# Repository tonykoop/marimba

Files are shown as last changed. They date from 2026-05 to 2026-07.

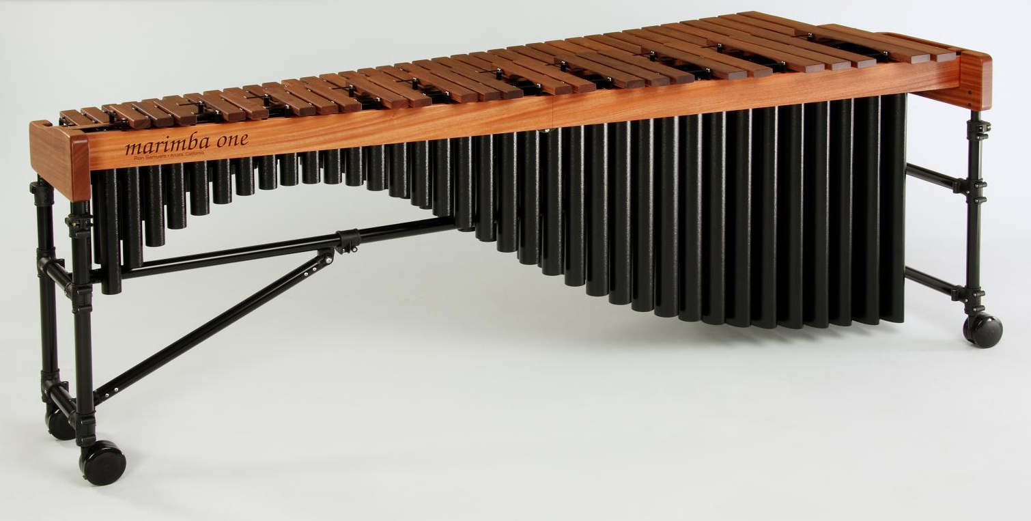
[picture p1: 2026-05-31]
images/hero-render.png

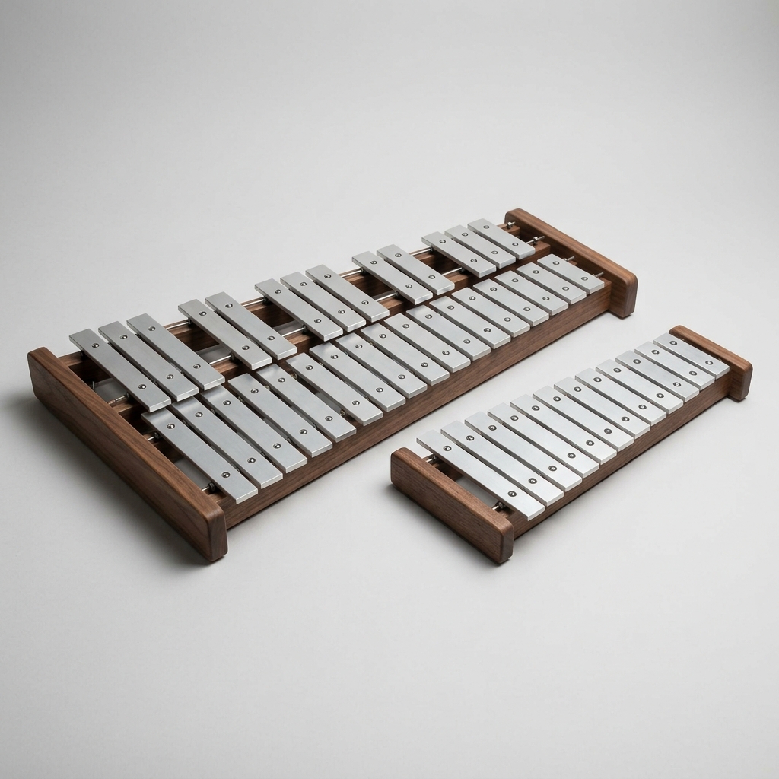
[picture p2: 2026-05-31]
images/family-group.png

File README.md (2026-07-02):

# Marimba - CNC Bar And Resonator Build Packet

> A workbook-derived 37-bar C3-C6 marimba packet for CNC-cut Padauk bars, 3D arch undercuts, tuned quarter-wave resonators, and a SolidWorks-ready master-layout handoff.

Status: L1 concept packet

## What This Is

This repository is the Mode A v4.2 build packet for a marimba: tuned wooden free-free bars suspended at their nodes, with a matched resonator under each note. It turns the existing `marimba-design-table.xlsx` scaffold into a shop-facing documentation set:

1. `design.md` explains the physics model, build range, assumptions, and validation plan.
2. `family-spec.csv` is the 37-bar C3-C6 schedule extracted from the workbook formulas.
3. `bom.csv`, `sourcing.csv`, and `cut-list.csv` separate stable specifications from supplier facts that should be verified before buying.
4. `drawings/`, `cad/`, `cnc/`, `wolfram/`, and `site/` carry the technical handoff layers.
5. `jig-decision.md` turns the fixture assumptions into pilot-build gates before the full Padauk run.
6. `visual-output-register.csv`, `docs/v5-authority-register.csv`,
   `validation-loop.csv`, `docs/v5-readiness.md`, and
   `cad/mcp-session-log.md` make the V5 promotion boundary explicit.

Part of the [tonykoop/instrument-maker](https://github.com/tonykoop/instrument-maker) catalog.

## Physics In One Minute

A marimba bar is a free-free beam. The first mode uses `lambda_1 = 4.730`, and the practical workbook model is:

```text
f ~= K * t / L^2
L ~= sqrt(K * t / f)
```

Length is the dominant pitch lever. Bar thickness and the underside arch tune the bar; width mostly affects feel, loudness, stiffness distribution, and available resonator bore. The cord/support points land at about `0.224 * L` and `0.776 * L`.

The resonator tubes are quarter-wave closed pipes:

```text
L_res ~= c / (4 * f) - 0.82 * bore
```

The resonator reinforces the bar's target frequency. It does not tune the bar itself.

## Build Range

The active packet is a 37-bar chromatic range from C3 to C6, using the workbook's African Padauk setting:

| Note | Frequency | Bar length | Width | Arch depth | Resonator |
| --- | ---: | ---: | ---: | ---: | ---: |
| C3 | 130.813 Hz | 32.251 in | 2.000 in | 0.625 in | 24.260 in |
| C4 | 261.626 Hz | 22.805 in | 1.750 in | 0.469 in | 11.515 in |
| A4 | 440.000 Hz | 17.585 in | 1.750 in | 0.352 in | 6.265 in |
| C6 | 1046.502 Hz | 11.403 in | 1.250 in | 0.156 in | 2.212 in |

The workbook also documents two expansion shapes: a full C2-F6 marimba and a portable C4-F6 instrument. Those are not cut lists yet; they are future configurations once the C3-C6 bar and resonator workflow is validated.

## Repository Structure

```text
marimba/
|-- README.md
|-- design.md
|-- marimba-design-table.xlsx
|-- family-spec.csv
|-- bom.csv
|-- sourcing.csv
|-- cut-list.csv
|-- validation.csv
|-- validation-loop.csv
|-- visual-output-register.csv
|-- assembly-manual.md
|-- supplier-rfq.md
|-- visual-bom-brief.md
|-- drawing-brief.md
|-- risks.md
|-- photo-shotlist.md
|-- cad/
|-- cnc/
|-- data/
|-- docs/
|-- drawings/
|-- evolution/
|-- images/
|-- site/
`-- wolfram/
```

`evolution/` - Stage 0 intake only (manifest, design-intent, revisions); Gate A not yet run.

## Status

**Readiness: L1** — concept / scaffold. Acoustic predictions are empirical estimates; no validated physical build or measured outputs yet. Not a V5 build-packet candidate.

| Area | Status |
| --- | --- |
| Readiness level | **L1** (concept/scaffold; estimates only) |
| V5 status | explorer/prototype scaffold only; not a V5 build-packet candidate |
| Workbook scaffold | done, source table in `marimba-design-table.xlsx` |
| Guided intake | done, see `data/design-intake.json` |
| C3-C6 bar schedule | done, see `family-spec.csv` |
| Visual authority register | done, see `visual-output-register.csv` |
| Issue #5 V5 authority register | reviewed packet surface, see `docs/v5-authority-register.csv` |
| Pilot DXF | C3/A4/C6 only, see `drawings/marimba-pilot-plate.dxf` |
| Validation loop | measurement-required, see `validation-loop.csv` |
| V5 readiness ledger | scaffolded, see `docs/v5-readiness.md` |
| MCP provenance | scaffolded with no live sessions yet, see `cad/mcp-session-log.md` |
| CNC operation plan | generated, pre-CAM only |
| SolidWorks handoff | prepared as CSV/Markdown contract, no native CAD yet |
| Wolfram source | prepared as `.wl`; notebook execution pending local Wolfram |
| Jig decision layer | done, see `jig-decision.md` |
| Build photos | pending first shop build |
| Measured tuning data | pending prototype validation |

The current CAD/DXF authority chain is a reviewed packet surface, not measured
fabrication authority. Workbook-derived design tables, the OpenSCAD starter,
and the pilot DXF plate are registered as `pending_measurement` in
`visual-output-register.csv` and `docs/v5-authority-register.csv`. Generated or
rendered visuals, when added later, are concept/support artifacts only and do
not control dimensions, node locations, resonator lengths, or CNC toolpaths.

## License

[CC BY 4.0](LICENSE) - see `LICENSE` for details.

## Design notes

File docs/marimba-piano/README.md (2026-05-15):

# Marimba Piano

Current status: bare-bones readiness packet

Fabrication authority: not build-ready. The sketch, notes, and estimates in this folder are concept and planning material only until a measured coupon build promotes specific dimensions into CAD, DXF, or a reviewed drawing.

## Concept

The Marimba Piano is a keyboard-driven modular idiophone. Piano-style keys and hammers stay in the chassis. The sound source is a removable tone-bar frame that can be swapped for different acoustic profiles: wood, synthetic bar stock, aluminum, or other tested materials.

The core idea has three modular systems:

- Interchangeable tone-bar frames on the front plane.
- A right-side platen lever that clamps the selected frame and seals its aperture plate against the resonator bank.
- A left-side hammer selector that rotates or indexes multiple hammer-face materials across the whole keyboard.

## File Map

- `design.md` - architecture, assumptions, acoustic model, and open measurements.
- `prototype-plan.md` - P0 through P3 build sequence.
- `tuning-targets-c4-c5.csv` - first-order C4-C5 targets for a 13-note module.
- `hammer-head-test-matrix.csv` - candidate hammer faces and expected effects.
- `aperture-test-matrix.csv` - aperture and coupling tests for resonator throats.
- `bom.csv` - starter bill of materials.
- `sourcing.csv` - sourcing placeholders; all supplier facts are unverified.
- `cut-list.csv` - candidate parts with TBD or estimate status.
- `validation.csv` - gates needed before this becomes a build-ready packet.
- `risks.md` - failure modes and mitigations.
- `drawing-brief.md` - future drawings and authority rules.
- `photo-shotlist.md` - optional documentation shots.
- `references/sketch-20260514.jpg` - original morning sketch, reference-only.

## Next Gates

1. Build a one-note P0 coupon with one key, one hammer, one interchangeable bar, one aperture plate, and one resonator.
2. Measure bar pitch, resonator pitch, gasket leakage, hammer-face tone changes, and platen repeatability.
3. Update the estimates with measured corrections.
4. Promote only measured or reviewed geometry into CAD/DXF authority.

## License Note

No license has been selected for this concept packet yet. Add a license before publishing or sharing fabrication files.

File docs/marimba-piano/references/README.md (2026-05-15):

# References

The files in this folder are reference-only. They do not control dimensions, cut paths, hole locations, aperture locations, hammer centers, or resonator lengths.

- `sketch-20260514.jpg` - original Marimba Piano sketch from the morning idea capture.

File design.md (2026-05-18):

# Marimba Design Packet

## Project Intent

Build a 37-bar C3-C6 marimba packet from the existing workbook design table. The first build target is a CNC-friendly instrument with African Padauk bars, parabolic underside arch undercuts, drilled node supports, quarter-wave resonators, and a frame layout that can become a SolidWorks master sketch.

The useful boundary for this packet is "prototype/shop-planning documentation, not finished CAD or measured build authority." Native SolidWorks files do not exist yet. The CAD folder defines the global-variable and design-table contract Tony can use to build the real model after pilot measurements review the workbook predictions.

## Design Intake

| Field | Value |
| --- | --- |
| Instrument | Marimba |
| Instrument family | Free-free beam idiophone with tuned quarter-wave resonators |
| Active build range | C3-C6 chromatic, 37 bars |
| Source workbook | `marimba-design-table.xlsx`, sheet `Marimba`, range `A1:X106` |
| Primary material | African Padauk bars, workbook K constant `155502` |
| Bar thickness | `0.875 in` nominal edge thickness |
| Minimum center thickness | `0.250 in` after arch undercut |
| Construction pipeline | CNC surfaced blanks, 3D arch undercut, profile/tabs, node drilling, resonator cutting, frame assembly |
| Done-bar reference | `tongue-drum` README and wooden idiophone validation discipline |

The guided v4.2 intake artifacts are in `data/design-intake.json` and `data/design-input-row.csv`.

## Governing Model

### Bar Pitch

The marimba bars are treated as free-free beams. The first flexural mode uses:

```text
lambda_1 = 4.730
f_1 = (lambda_1^2 / (2*pi*L^2)) * sqrt(E*I/(rho*A))
```

The workbook uses the practical shop form:

```text
f ~= K * t / L^2
L ~= sqrt(K * t / f)
```

where:

- `f` is target frequency in Hz.
- `K` is the material-specific free-free bar constant.
- `t` is nominal bar thickness at the edge.
- `L` is bar length.

For the active packet:

```text
K = 155502
t = 0.875 in
```

The workbook material library derives this free-free K from the beam material properties and the `lambda_1 = 4.730` mode shape. Do not apply flute-bore K2 corrections here; those belong to Native American style flute bore correction work, not beam idiophones.

### Nodes And Supports

The suspension node locations are:

```text
node_1 = 0.224 * L
node_2 = 0.776 * L
```

Cord holes and rail pins reference these two locations. Holes must be drilled at the nodal line so the support does not damp the main mode.

### Arch Undercut

The workbook defines a linear MIDI-scaled arch-depth schedule:

```text
arch_depth = (edge_thickness - min_center_thickness) * min(1, (96 - midi)/48)
center_thickness = edge_thickness - arch_depth
```

This makes the low bars carry the deepest undercut and the high bars approach a shallow arch. The current minimum center thickness is `0.250 in`, so C3 reaches the minimum while C6 remains about `0.719 in` at center.

The arch should be cut as a centered parabolic underside relief over roughly 60 percent of the bar length. Final voicing still requires controlled sanding and tuner checks; the workbook is the first-pass schedule.

### Resonators

The resonator tubes are treated as quarter-wave closed pipes:

```text
L_res = 13552 / (4 * f) - 0.82 * bore
```

The sheet currently uses the bar-width column as the resonator bore/end-correction proxy. That is acceptable as a first-pass planning value, but the sourcing pass should decide real tube diameters and update `family-spec.csv` if the selected bore differs from the workbook proxy.

The distinction is important:

- Bar pitch is tuned by bar length, thickness, arch geometry, and material.
- Resonator length is tuned to reinforce the already-tuned bar frequency.
- A resonator mismatch changes sustain/loudness/color; it does not fix a wrong bar pitch.

## Bar Schedule

The full schedule is in `family-spec.csv`. Representative rows:

| Note | MIDI | Target Hz | Length in | Width in | Node 1 in | Node 2 in | Arch in | Center in | Resonator in |
| --- | ---: | ---: | ---: | ---: | ---: | ---: | ---: | ---: | ---: |
| C3 | 48 | 130.813 | 32.251 | 2.000 | 7.224 | 25.027 | 0.625 | 0.250 | 24.260 |
| C4 | 60 | 261.626 | 22.805 | 1.750 | 5.108 | 17.697 | 0.469 | 0.406 | 11.515 |
| A4 | 69 | 440.000 | 17.585 | 1.750 | 3.939 | 13.646 | 0.352 | 0.523 | 6.265 |
| C6 | 84 | 1046.502 | 11.403 | 1.250 | 2.554 | 8.848 | 0.156 | 0.719 | 2.212 |

## Resonator Schedule

`family-spec.csv` includes a first-pass tube length for every note. Treat these as cut-long values until a tube material, bore, cap style, and stopper/trim strategy are selected.

Recommended build behavior:

1. Cut resonators at least `0.5 in` long for C5 and above, and at least `1.0 in` long below C5.
2. Use adjustable caps or removable plugs for the first build.
3. Tune resonators after the bars are struck and measured in the frame.
4. Record final tube length and cents response in `validation.csv`.

## Hardware Alignment

The support rails follow the node path rather than a fixed straight rail. For each bar:

- Left support: `node_1_in`.
- Right support: `node_2_in`.
- Cord/support hole diameter: `0.250 in` starting point.
- Frame pin/rubber support must touch at the node, not at the bar end.
- Bar spacing and frame taper are `TBD` until mallet clearance and resonator tube diameters are chosen.

`jig-decision.md` is the controlling fixture decision record. It keeps the pilot workflow staged: build only the carrier, two-sided spoilboard, arch cradle, node-drilling support, and tube V-block needed for C3/A4/C6 before freezing full-set CAM or final frame geometry.

## SolidWorks MasterLayout Plan

The SolidWorks model should be driven from a master sketch and equations:

1. A `Master_Bar` part with configurations from `cad/design-table-inputs.csv`.
2. A `Master_Resonator` part with tube length, bore, cap allowance, and mounting hole variables.
3. A `Frame_MasterLayout` sketch defining bass and treble rail curves, bar spacing, resonator centerlines, and player-side datum.

Do not model hand-edited dimensions in SolidWorks. Every repeated note configuration should be driven by the variables listed in `cad/sw-global-variables.csv`.

## Open Assumptions

- Active packet uses C3-C6 instead of the workbook's full C2-F6 or portable C4-F6 variants.
- African Padauk is the workbook-selected material; actual board availability and moisture content are not verified.
- Resonator tube material and exact bore are `TBD`; current resonator lengths use the workbook width/end-correction proxy.
- Frame geometry, rail spacing, bar spacing, and transport strategy need CAD and ergonomic review.
- CNC feeds/speeds are starting notes only; final CAM must use the actual bit, router, hold-down, stock, and simulation.
- No measured bar data exists yet, so all frequencies are target predictions.

## Validation Plan

1. Surface three sacrificial bars first: C3, A4, and C6. These bound the length, arch, and treble-end assumptions.
2. Measure blank thickness, length, density estimate, and moisture content before cutting the arch.
3. Record flat-bar pitch, post-arch pitch, post-sanding pitch, and final assembled pitch.
4. Update `validation.csv` with measured Hz and cents error:

```text
cents = 1200 * log2(measured_hz / target_hz)
```

5. If the C3/A4/C6 pilot set misses by more than +/- 15 cents before final sanding, update the K constant or arch schedule before cutting the remaining 34 bars.
6. Tune resonators only after bars are within the target tuning window.

## Provenance

- Source workbook: `marimba-design-table.xlsx`, generated before this v4.2 packet run.
- Skill workflow: `instrument-maker-v4` v4.2.
- Reference family: `cantilever-idiophone` in `repo-relationships.yaml`; marimba notes call out bar tuning plus resonator coupling.

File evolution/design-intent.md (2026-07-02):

# Design Intent — marimba rev A

- Master CAD: `cad/marimba-master.scad` (sha256: 21992d58f3f68e8395d4e0ee72059a1bea4e34cf695be2ac47890f6cfe9047b7, existing master — kept, not rewritten), driven by `marimba-design-table.xlsx` (sha256: 18026262836f8fb903d49de57e870309a49bbbb24a219b928fb5d9400e56b172) via `cad/design-table-inputs.csv` / `family-spec.csv`.
- Function: 37-bar C3-C6 chromatic marimba. Free-free Padauk bars suspended near their 0.224L/0.776L nodes, each paired with a tuned quarter-wave closed resonator tube. Bar length is the dominant pitch lever (`f ~= K*t/L^2`); resonator length reinforces the bar's target frequency (design.md "Physics In One Minute").
- Environment: shop-built percussion instrument; CNC-cut bars with 3D-printed/machined arch undercuts.
- Target qty: 1 pilot (C3/A4/C6), then full 37-bar run. Deadline: TBD. Budget: TBD.

## Critical dimensions (carry tolerances)

| Feature | Nominal | Tolerance | Why critical | Source |
| --- | --- | --- | --- | --- |
| Bar length (per note) | e.g. A4 17.585 in | +/- 10 cents after tuning allowance | sets fundamental pitch | family-spec.csv / marimba-design-table.xlsx |
| Bar thickness / arch depth | e.g. A4 0.352 in arch | measurement_required; C3 floor 0.250 in center thickness | tunes pitch, avoids cracking | family-spec.csv; risks.md "Arch cut-through or weak low bars" |
| Support node positions | 0.224 L / 0.776 L | measurement_required | free-free suspension points | design.md "Physics In One Minute" |
| Resonator length | e.g. A4 6.265 in | measurement_required — bore proxy currently uses bar width | tunes resonator coupling | family-spec.csv; risks.md "Resonator bore proxy is wrong" |
| Support hole diameter | 1/4 in | measurement_required (splitting risk near nodes) | structural | risks.md "Support holes weaken bars" |

## Incidental (free for DFM)

- Frame/rail cosmetic styling, non-mating surface finish, resonator tube color/coating.

## Must-nots (DFM may never violate)

- Bar length/thickness stay workbook-formula-derived (`f ~= K*t/L^2`) until pilot C3/A4/C6 measurement corrects the K constant (risks.md "Bar pitch misses workbook prediction").
- Do not cut the full 37-bar run before the C3/A4/C6 pilot passes tuning and structural gates (README.md "Status" table; risks.md).
- Never let C3 (or any bar) go below 0.250 in center thickness after arch cut (risks.md "Arch cut-through or weak low bars").
- Resonator bore/end-correction proxy (currently bar width) must be replaced with real tube ID before cutting the full resonator bank (risks.md "Resonator bore proxy is wrong").

## Material intent

- Bars: African Padauk (active workbook setting) per bom.csv/sourcing.csv. Resonator tubes: material/bore TBD pending selection.

## Stage status

Stage 0 intake complete 2026-07-01. Gate A (Alpha shop compile) NOT yet run — no concessions logged, nothing presented as shippable. Remains L1 concept/scaffold; not a V5 build-packet candidate (README.md).

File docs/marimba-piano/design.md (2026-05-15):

# Marimba Piano Design Notes

Current status: bare-bones readiness packet

Fabrication authority: not build-ready. Generated images, sketches, and first-order estimates do not control dimensions. Future CAD, DXF, design tables, measured templates, or explicitly reviewed drawings will control fabrication.

## Intent

Build a keyboard instrument that plays like a small upright piano but sounds through struck tone bars and tuned resonators. The player can swap a complete tone-bar frame to change the instrument voice, then use a side handle to change hammer-face material without removing the hammers from the chassis.

The design goal is not just "piano plus marimba." The interesting part is a repeatable experimental platform for idiophone timbre:

- Same keyboard action, different bar materials.
- Same bars, different hammer faces.
- Same pitch bank, different aperture and resonator couplings.
- Same chassis, multiple voice cassettes.

## Baseline Architecture

### Fixed Chassis

The chassis holds the key bed, hammer action, left-side hammer selector, right-side platen lever, and adjustable resonator bed. For the first prototype, use a 13-note chromatic module from C4 to C5 instead of a full keyboard.

### Interchangeable Voice Cassette

Each voice cassette carries:

- Tone bars mounted at free-free beam suspension nodes.
- Bar supports and quiet locating hardware.
- A lower aperture plate aligned to the resonator bank.
- Gaskets bonded to the aperture plate or seated in replaceable gasket pockets.
- Tapered alignment features that locate the cassette before the platen lever compresses it.

The cassette should slide into the front plane, then move a short controlled distance under platen pressure to seal against the resonators.

### Adjustable Resonator Bed

The resonator bank is independent from the tone-bar cassette. It should have:

- Threaded standoffs for height and angle adjustment.
- Compression springs or compliant mounts to take up slack.
- Tapered pins or V-block features for repeatable alignment.
- Replaceable pipe banks for wood/synthetic voices versus metallic voices if testing shows the same bank cannot support both well.

The first assumption is that resonator pipe length sets the main pitch support, while the cassette aperture controls coupling, loudness, sustain, and spectral balance.

### Platen Lever

The right-side platen lever should move the tone-bar cassette into the fixed or floating resonator bank. Preferred first mechanism:

- Over-center cam shaft or toggle clamp linkage.
- 2 to 4 mm gasket compression target for P0 testing.
- Adjustable hard stop so the lever cannot over-crush gaskets.
- Mechanical interlock that prevents cassette removal while clamped.

### Hammer Selector

The left-side selector changes hammer material across the row. For P0, test one hammer with a manual three-face head. For P1, use a ganged selector rail only after the one-note mechanism is reliable.

Preferred P1 direction:

- Each hammer has a small indexed three-face rotor at the strike end.
- The selector rail engages the hammer-head rotors only at rest.
- A left-side handle indexes the rail by 120 degrees.
- A detent confirms soft, medium, or hard face selection.
- The hammer action remains free during play, without continuous drag from the selector.

Avoid treating the ganged selector as solved until the one-note coupon proves rebound, noise, return, and indexing repeatability.

## Acoustic Model

### Tone Bars

Tone bars are modeled as free-free beams. First-order support nodes are 22.4 percent and 77.6 percent of bar length.

For rectangular flat bars:

```text
f is proportional to thickness / length^2
```

The first table uses the instrument-maker free-free beam estimate derived from the listed material constants. These are planning estimates only. Wood bars should be tuned by undercutting and measurement; aluminum bars may need different thickness, width, damping, or support choices.

### Resonators

Resonator tubes are treated as closed-open quarter-wave pipes:

```text
L_tube = c / (4f) - 0.82 * bore_diameter
```

The C4-C5 table assumes about 68 F air temperature and A4 = 440 Hz. Bent, downward-facing, upward-facing, and straight-out tubes can share effective length only if the bend and aperture losses are validated by measurement.

### Apertures

Apertures are part of the voice cassette, not the fixed resonator bank. Aperture geometry is treated as a coupling/Q control, not the primary pitch control.

Initial aperture hypotheses:

- Wood bars: larger, more open throats for bloom and projection.
- Synthetic bars: medium throats for consistency and controlled sustain.
- Aluminum bars: smaller throats, slot throats, baffles, or damping screens to reduce excessive sustain and high-frequency glare.

## Open Measurements

- Actual tone-bar stock dimensions, density, grain direction, and moisture state.
- Measured pitch of each flat bar before and after support drilling or cording.
- Amount of pitch drop available from undercutting each wood profile.
- Hammer strike speed and rebound with each face material.
- Mechanical noise from selector detents and hammer return.
- Gasket compression needed for an audible seal.
- Resonator pipe pitch before aperture coupling.
- Effect of aperture diameter/slot/baffle on loudness, sustain, and timbre.
- Whether a single pipe bank can support multiple wood/synthetic cassettes.
- Whether metallic cassettes require a separate pipe bank.

## First Build Scope

P0 is one note, not a whole keyboard. Build one middle-range note, preferably A4 or C5, because the bar and resonator dimensions are manageable and measurement is easy. P1 is the 13-note C4-C5 module.

Do not build the full instrument until P0 proves the seal, hammer selector, and resonator coupling.

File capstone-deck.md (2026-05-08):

# Marimba CNC Bar And Resonator Build Packet
- Musical instrument documentation capstone
- Build packet: marimba
- Generated: 2026-05-06

---

# Project Intent
- Build a 37-bar C3-C6 marimba packet from the existing workbook design table. The first build target is a CNC-friendly instrument with African Padauk bars, parabolic underside arch undercuts, drilled node supports, quarter-wave resonators, and a frame layout that can become a SolidWorks master sketch.

_Speaker notes:_ Read design.md before committing to dimensions or sourcing decisions.

---

# Physics Model
- ### Bar Pitch

```
lambda_1 = 4.730
f_1 = (lambda_1^2 / (2*pi*L^2)) * sqrt(E*I/(rho*A))
```

```
f ~= K * t / L^2
L ~= sqrt(K * t / f)
```

```
K = 155502
t = 0.875 in
```

```
node_1 = 0.224 * L
node_2 = 0.776 * L
```

```
arch_depth = (edge_thickness - min_center_thickness) * min(1, (96 - midi)/48)
center_thickness = edge_thickness - arch_depth
```

```
L_res = 13552 / (4 * f) - 0.82 * bore
```

_Speaker notes:_ Governing equations extracted verbatim from design.md. Apply empirical corrections (NAF K2, scale offsets) only where the model permits — see references/acoustic-models.md.

---

# Hardware Alignment
- The support rails follow the node path rather than a fixed straight rail. For each bar:

_Speaker notes:_ Identifies which shop pipeline(s) this instrument lives in: Bambu+kiln slip-cast, 40W laser flat-pack, CNC+lathe, segmented turning, drum-skin work, or hybrid combinations.

---

# How To Use This Packet
- Start with design.md for intent and assumptions.
- Use bom.csv, sourcing.csv, and cut-list.csv before buying or cutting.
- Use drawing-brief.md and CAD/CNC folders before machining.
- Print the packet for shopping, shop work, and validation.

---

# File Map
- design.md: Project intent, catalog metadata, assumptions, and validation plan.
- bom.csv: Starter bill of materials with part categories, quantities, drawing refs, and notes.
- sourcing.csv: Supplier/search tracker with specs, price/date fields, lead time, substitutes, and risks.
- cut-list.csv: Rough/final stock sizes, material, grain/orientation, operations, yield, and offcuts.
- drawing-brief.md: Manufacturing drawing and technical product sketch brief.
- jig-decision.md: Fixture decision record and pilot jig release gates.
- assembly-manual.md: Shop-facing sequence, tools, fixtures, safety, tuning, finishing, and maintenance notes.
- validation.csv: Target/measured values, tolerance, environment, result, and tuning/build action log.
- supplier-rfq.md: Supplier email/request-for-quote starter.

---

# Family Spec

| member_id | target_note | midi | target_hz | predicted_length_in | predicted_width_in | predicted_thick_in | node_1_in | node_2_in | arch_depth_in | center_thickness_in | resonator_length_in | resonator_bore_in | material | k_constant | scale_label | notes |
| --- | --- | --- | --- | --- | --- | --- | --- | --- | --- | --- | --- | --- | --- | --- | --- | --- |
| MAR-C3 | C3 | 48 | 130.813 | 32.251 | 2.000 | 0.875 | 7.224 | 25.027 | 0.625 | 0.250 | 24.260 | 2.000 | African Padauk | 155502 | C3-C6 chromatic | Workbook-derived from Marimba sheet; resonator bore currently follows width/end-correction proxy. |
| MAR-Csharp3 | C#3 | 49 | 138.591 | 31.333 | 2.000 | 0.875 | 7.019 | 24.315 | 0.612 | 0.263 | 22.806 | 2.000 | African Padauk | 155502 | C3-C6 chromatic | Workbook-derived from Marimba sheet; resonator bore currently follows width/end-correction proxy. |
| MAR-D3 | D3 | 50 | 146.832 | 30.441 | 2.000 | 0.875 | 6.819 | 23.622 | 0.599 | 0.276 | 21.434 | 2.000 | African Padauk | 155502 | C3-C6 chromatic | Workbook-derived from Marimba sheet; resonator bore currently follows width/end-correction proxy. |
| MAR-Dsharp3 | D#3 | 51 | 155.563 | 29.575 | 2.000 | 0.875 | 6.625 | 22.950 | 0.586 | 0.289 | 20.139 | 2.000 | African Padauk | 155502 | C3-C6 chromatic | Workbook-derived from Marimba sheet; resonator bore currently follows width/end-correction proxy. |
| MAR-E3 | E3 | 52 | 164.814 | 28.733 | 2.000 | 0.875 | 6.436 | 22.297 | 0.573 | 0.302 | 18.917 | 2.000 | African Padauk | 155502 | C3-C6 chromatic | Workbook-derived from Marimba sheet; resonator bore currently follows width/end-correction proxy. |
| MAR-F3 | F3 | 53 | 174.614 | 27.915 | 2.000 | 0.875 | 6.253 | 21.662 | 0.560 | 0.315 | 17.763 | 2.000 | African Padauk | 155502 | C3-C6 chromatic | Workbook-derived from Marimba sheet; resonator bore currently follows width/end-correction proxy. |
| MAR-Fsharp3 | F#3 | 54 | 184.997 | 27.120 | 2.000 | 0.875 | 6.075 | 21.045 | 0.547 | 0.328 | 16.674 | 2.000 | African Padauk | 155502 | C3-C6 chromatic | Workbook-derived from Marimba sheet; resonator bore currently follows width/end-correction proxy. |
| MAR-G3 | G3 | 55 | 195.998 | 26.348 | 2.000 | 0.875 | 5.902 | 20.446 | 0.534 | 0.341 | 15.646 | 2.000 | African Padauk | 155502 | C3-C6 chromatic | Workbook-derived from Marimba sheet; resonator bore currently follows width/end-correction proxy. |
| MAR-Gsharp3 | G#3 | 56 | 207.652 | 25.598 | 2.000 | 0.875 | 5.734 | 19.864 | 0.521 | 0.354 | 14.676 | 2.000 | African Padauk | 155502 | C3-C6 chromatic | Workbook-derived from Marimba sheet; resonator bore currently follows width/end-correction proxy. |
| MAR-A3 | A3 | 57 | 220.000 | 24.869 | 2.000 | 0.875 | 5.571 | 19.298 | 0.508 | 0.367 | 13.760 | 2.000 | African Padauk | 155502 | C3-C6 chromatic | Workbook-derived from Marimba sheet; resonator bore currently follows width/end-correction proxy. |
| MAR-Asharp3 | A#3 | 58 | 233.082 | 24.161 | 2.000 | 0.875 | 5.412 | 18.749 | 0.495 | 0.380 | 12.896 | 2.000 | African Padauk | 155502 | C3-C6 chromatic | Workbook-derived from Marimba sheet; resonator bore currently follows width/end-correction proxy. |
| MAR-B3 | B3 | 59 | 246.942 | 23.473 | 2.000 | 0.875 | 5.258 | 18.215 | 0.482 | 0.393 | 12.080 | 2.000 | African Padauk | 155502 | C3-C6 chromatic | Workbook-derived from Marimba sheet; resonator bore currently follows width/end-correction proxy. |
| MAR-C4 | C4 | 60 | 261.626 | 22.805 | 1.750 | 0.875 | 5.108 | 17.697 | 0.469 | 0.406 | 11.515 | 1.750 | African Padauk | 155502 | C3-C6 chromatic | Workbook-derived from Marimba sheet; resonator bore currently follows width/end-correction proxy. |
| MAR-Csharp4 | C#4 | 61 | 277.183 | 22.156 | 1.750 | 0.875 | 4.963 | 17.193 | 0.456 | 0.419 | 10.788 | 1.750 | African Padauk | 155502 | C3-C6 chromatic | Workbook-derived from Marimba sheet; resonator bore currently follows width/end-correction proxy. |
| MAR-D4 | D4 | 62 | 293.665 | 21.525 | 1.750 | 0.875 | 4.822 | 16.704 | 0.443 | 0.432 | 10.102 | 1.750 | African Padauk | 155502 | C3-C6 chromatic | Workbook-derived from Marimba sheet; resonator bore currently follows width/end-correction proxy. |
| MAR-Dsharp4 | D#4 | 63 | 311.127 | 20.912 | 1.750 | 0.875 | 4.684 | 16.228 | 0.430 | 0.445 | 9.454 | 1.750 | African Padauk | 155502 | C3-C6 chromatic | Workbook-derived from Marimba sheet; resonator bore currently follows width/end-correction proxy. |
| MAR-E4 | E4 | 64 | 329.628 | 20.317 | 1.750 | 0.875 | 4.551 | 15.766 | 0.417 | 0.458 | 8.843 | 1.750 | African Padauk | 155502 | C3-C6 chromatic | Workbook-derived from Marimba sheet; resonator bore currently follows width/end-correction proxy. |
| MAR-F4 | F4 | 65 | 349.228 | 19.739 | 1.750 | 0.875 | 4.421 | 15.317 | 0.404 | 0.471 | 8.266 | 1.750 | African Padauk | 155502 | C3-C6 chromatic | Workbook-derived from Marimba sheet; resonator bore currently follows width/end-correction proxy. |
| MAR-Fsharp4 | F#4 | 66 | 369.994 | 19.177 | 1.750 | 0.875 | 4.296 | 14.881 | 0.391 | 0.484 | 7.722 | 1.750 | African Padauk | 155502 | C3-C6 chromatic | Workbook-derived from Marimba sheet; resonator bore currently follows width/end-correction proxy. |
| MAR-G4 | G4 | 67 | 391.995 | 18.631 | 1.750 | 0.875 | 4.173 | 14.458 | 0.378 | 0.497 | 7.208 | 1.750 | African Padauk | 155502 | C3-C6 chromatic | Workbook-derived from Marimba sheet; resonator bore currently follows width/end-correction proxy. |
| MAR-Gsharp4 | G#4 | 68 | 415.305 | 18.100 | 1.750 | 0.875 | 4.054 | 14.046 | 0.365 | 0.510 | 6.723 | 1.750 | African Padauk | 155502 | C3-C6 chromatic | Workbook-derived from Marimba sheet; resonator bore currently follows width/end-correction proxy. |
| MAR-A4 | A4 | 69 | 440.000 | 17.585 | 1.750 | 0.875 | 3.939 | 13.646 | 0.352 | 0.523 | 6.265 | 1.750 | African Padauk | 155502 | C3-C6 chromatic | Workbook-derived from Marimba sheet; resonator bore currently follows width/end-correction proxy. |
| MAR-Asharp4 | A#4 | 70 | 466.164 | 17.085 | 1.750 | 0.875 | 3.827 | 13.258 | 0.339 | 0.536 | 5.833 | 1.750 | African Padauk | 155502 | C3-C6 chromatic | Workbook-derived from Marimba sheet; resonator bore currently follows width/end-correction proxy. |
| MAR-B4 | B4 | 71 | 493.883 | 16.598 | 1.750 | 0.875 | 3.718 | 12.880 | 0.326 | 0.549 | 5.425 | 1.750 | African Padauk | 155502 | C3-C6 chromatic | Workbook-derived from Marimba sheet; resonator bore currently follows width/end-correction proxy. |
| MAR-C5 | C5 | 72 | 523.251 | 16.126 | 1.500 | 0.875 | 3.612 | 12.513 | 0.312 | 0.562 | 5.245 | 1.500 | African Padauk | 155502 | C3-C6 chromatic | Workbook-derived from Marimba sheet; resonator bore currently follows width/end-correction proxy. |
| MAR-Csharp5 | C#5 | 73 | 554.365 | 15.667 | 1.500 | 0.875 | 3.509 | 12.157 | 0.299 | 0.576 | 4.881 | 1.500 | African Padauk | 155502 | C3-C6 chromatic | Workbook-derived from Marimba sheet; resonator bore currently follows width/end-correction proxy. |
| MAR-D5 | D5 | 74 | 587.330 | 15.221 | 1.500 | 0.875 | 3.409 | 11.811 | 0.286 | 0.589 | 4.538 | 1.500 | African Padauk | 155502 | C3-C6 chromatic | Workbook-derived from Marimba sheet; resonator bore currently follows width/end-correction proxy. |
| MAR-Dsharp5 | D#5 | 75 | 622.254 | 14.787 | 1.500 | 0.875 | 3.312 | 11.475 | 0.273 | 0.602 | 4.215 | 1.500 | African Padauk | 155502 | C3-C6 chromatic | Workbook-derived from Marimba sheet; resonator bore currently follows width/end-correction proxy. |
| MAR-E5 | E5 | 76 | 659.255 | 14.366 | 1.500 | 0.875 | 3.218 | 11.148 | 0.260 | 0.615 | 3.909 | 1.500 | African Padauk | 155502 | C3-C6 chromatic | Workbook-derived from Marimba sheet; resonator bore currently follows width/end-correction proxy. |
| MAR-F5 | F5 | 77 | 698.456 | 13.957 | 1.500 | 0.875 | 3.126 | 10.831 | 0.247 | 0.628 | 3.621 | 1.500 | African Padauk | 155502 | C3-C6 chromatic | Workbook-derived from Marimba sheet; resonator bore currently follows width/end-correction proxy. |
| MAR-Fsharp5 | F#5 | 78 | 739.989 | 13.560 | 1.500 | 0.875 | 3.037 | 10.523 | 0.234 | 0.641 | 3.348 | 1.500 | African Padauk | 155502 | C3-C6 chromatic | Workbook-derived from Marimba sheet; resonator bore currently follows width/end-correction proxy. |
| MAR-G5 | G5 | 79 | 783.991 | 13.174 | 1.500 | 0.875 | 2.951 | 10.223 | 0.221 | 0.654 | 3.091 | 1.500 | African Padauk | 155502 | C3-C6 chromatic | Workbook-derived from Marimba sheet; resonator bore currently follows width/end-correction proxy. |
| MAR-Gsharp5 | G#5 | 80 | 830.609 | 12.799 | 1.500 | 0.875 | 2.867 | 9.932 | 0.208 | 0.667 | 2.849 | 1.500 | African Padauk | 155502 | C3-C6 chromatic | Workbook-derived from Marimba sheet; resonator bore currently follows width/end-correction proxy. |
| MAR-A5 | A5 | 81 | 880.000 | 12.435 | 1.500 | 0.875 | 2.785 | 9.649 | 0.195 | 0.680 | 2.620 | 1.500 | African Padauk | 155502 | C3-C6 chromatic | Workbook-derived from Marimba sheet; resonator bore currently follows width/end-correction proxy. |
| MAR-Asharp5 | A#5 | 82 | 932.328 | 12.081 | 1.500 | 0.875 | 2.706 | 9.375 | 0.182 | 0.693 | 2.404 | 1.500 | African Padauk | 155502 | C3-C6 chromatic | Workbook-derived from Marimba sheet; resonator bore currently follows width/end-correction proxy. |
| MAR-B5 | B5 | 83 | 987.767 | 11.737 | 1.500 | 0.875 | 2.629 | 9.108 | 0.169 | 0.706 | 2.200 | 1.500 | African Padauk | 155502 | C3-C6 chromatic | Workbook-derived from Marimba sheet; resonator bore currently follows width/end-correction proxy. |
| MAR-C6 | C6 | 84 | 1046.502 | 11.403 | 1.250 | 0.875 | 2.554 | 8.848 | 0.156 | 0.719 | 2.212 | 1.250 | African Padauk | 155502 | C3-C6 chromatic | Workbook-derived from Marimba sheet; resonator bore currently follows width/end-correction proxy. |

_Speaker notes:_ Sizes scale via the master scale factor; tuning targets are first-order Helmholtz/cantilever predictions to be empirically corrected per prototype.

---

# Build Workflow
- Design and assumptions
- Source materials and hardware
- Prepare stock, fixtures, and CNC/laser/lathe setup
- Build the pilot jig set from jig-decision.md before committing full stock
- Assemble, tune, finish, and validate

---

# Sourcing And BOM
- BOM gives part categories and drawing references.
- Sourcing tracks search terms, supplier candidates, price/date, lead time, substitutions.
- Visual BOM brief turns the parts list into a presentation-ready image board.

---

# Shop Packet
- Cut list for lumber/sheet/blank planning.
- Assembly manual for away-from-keyboard work.
- Validation sheet for measured dimensions, tuning, pass/fail checks.

---

# Drawings, CAD, CNC
- drawing-brief.md defines required views, dimensions, datums, sketch intent.
- cad/ holds models and design tables.
- cnc/ holds CAM, toolpaths, setup sheets, dry-run notes.
- drawings/ holds PDFs, SVGs, DXFs, drawing exports.






---

# Images And Screenshots
- Add hero render/photo, visual BOM, shop screenshots, drawing previews, validation photos in images/.

---

# Validation Plan
- A4 = 440 Hz reference check.
- Tuning targets logged in validation.csv.
- Critical dimensions verified against design sheet and CAD.
- Photos and revision notes after each major step.

---

# Open Risks / Decisions
- TBDs in design sheet and BOM.
- Supplier price/availability not yet verified.
- Generated images marked as concept placeholders.
- Empirical corrections await measured prototype data.
- Full 37-bar fixture is blocked until C3/A4/C6 pilot validation rows pass.

---

# Next Actions
- Replace TBDs with measured/source-backed values.
- Verify live supplier price and availability before buying.
- Export final drawings and visual BOM images.
- Regenerate this deck and print packet after final edits.

---

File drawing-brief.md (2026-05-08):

# Drawing Brief

## Drawing Set

The current packet requires four build-critical drawing classes:

1. Per-bar SVGs generated from `family-spec.csv`.
2. `arch-undercut-section.svg` showing underside relief, edge thickness, center thickness, and tool assumptions.
3. `resonator-layout.svg` showing first-pass tube lengths and note mapping.
4. `frame-overview.svg` showing the frame datum plan, rail concept, bar order, and resonator clearance assumptions.
5. Fixture/jig sketches derived from `jig-decision.md`: two-sided spoilboard, arch cradle, node-drilling backer, resonator V-block, and temporary validation frame.

## Drawing Standards

- Units: inches.
- Primary datum for each bar: left end and centerline.
- Support holes: show `0.224 * L` and `0.776 * L`.
- Bar dimensions: length, width, edge thickness, center thickness, arch depth.
- Resonator dimensions: tube bore, acoustic length, trim allowance, cap style.
- Tolerances:
  - Bar length rough cut: +0.125 in / -0.000 in before tuning.
  - Final length: tune-to-pitch, not dimension-only.
  - Thickness before arch: +/- 0.005 in.
  - Node hole placement: +/- 0.020 in first-pass, improve after pilot data.
- CNC notes: bit diameter, stepover, Z-zero surface, tabs, workholding, and release checks.
- Jig notes: which fixture carries datum A/B/C and which validation row releases the operation.

## Open Drawing Questions

- Final resonator tube bore and cap style.
- Final frame rail curve and cross-member spacing.
- Bar spacing and accidental/natural row layout.
- Whether the first build uses a temporary validation frame or final furniture frame.
- Whether the pilot jig set graduates unchanged to the full 37-bar run after C3/A4/C6 measurements.

## Source Files

- `family-spec.csv`
- `design.md`
- `marimba-design-table.xlsx`
- `cad/SolidWorks-MasterLayout-Plan.md`
- `cnc/setup-sheet.md`
- `jig-decision.md`

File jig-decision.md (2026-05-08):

# Marimba Jig Decision Record

Generated: 2026-05-08

## Purpose

This file is the manufacturing decision layer for the marimba packet. The design table gives bar and resonator dimensions; the CNC setup sheet gives operations. This record decides which jigs earn their way into the first build, what each jig controls, and which validation row proves the decision worked.

The active recommendation is a staged jig system, not one universal fixture. The pilot build should make only the jigs needed to cut and measure C3, A4, and C6. The remaining 34 bars wait until those three bars validate material K, CNC arch behavior, support-hole placement, and resonator coupling.

## Source Inputs

| Source | Used for |
| --- | --- |
| `family-spec.csv` | Bar length, width, node positions, arch depth, center thickness, resonator length, bore proxy. |
| `design.md` | Free-free beam model, quarter-wave resonator model, open assumptions. |
| `cnc/setup-sheet.md` | Operation sequence, datum scheme, tool list, pilot gate. |
| `drawings/arch-undercut-section.svg` | Underside arch geometry and minimum center thickness. |
| `drawings/resonator-layout.svg` | Resonator tube length and note mapping. |
| `validation.csv` | Measurement rows that decide whether to scale from pilot to full set. |

## Datum Rules

| Datum | Meaning | Must survive |
| --- | --- | --- |
| A | Top face of the bar blank | Surfacing, profile, flip, arch cut, final thickness check. |
| B | Left end of the bar | Profile, node drilling, arch start/stop, SolidWorks comparison. |
| C | Bar centerline | Node holes, arch center, resonator centerline, frame rail layout. |

If a jig loses A/B/C, the bar is no longer traceable to `family-spec.csv`; stop and remark before cutting.

## Pilot Decision

| Pilot bar | Why it is in the pilot | Pass gate before full set |
| --- | --- | --- |
| C3 | Longest bar, deepest arch, minimum `0.250 in` center thickness, longest resonator. | Center thickness stays at or above `0.250 in`; pitch can be tuned within normal sanding allowance; resonator reinforces without buzz. |
| A4 | A4 = 440 Hz reference, mid-scale K check, mid-depth arch. | Measured K trend matches C3/C6 closely enough to continue; support holes do not damp sustain. |
| C6 | Shortest bar, shallowest arch, shortest resonator. | Z-zero and ball-end toolpath do not leave a dead/stiff bar; short resonator strategy remains audible. |

Full production is blocked until these rows in `validation.csv` have measured values: `flat_blank`, `post_arch`, `post_sand`, `resonator_coupled`, and `final_frame` for C3, A4, and C6.

## Decision Matrix

| Decision ID | Operation | Chosen jig | Why this choice | Go/no-go test |
| --- | --- | --- | --- | --- |
| JD-010 | Surface and thickness blanks | Planer/drum-sander carrier with grain arrow and top-face mark | Keeps Padauk blanks flat and preserves datum A before CNC. | Thickness is `0.875 in +/- 0.005 in` at both ends and center. |
| JD-020 | CNC profile and arch undercut | Two-sided spoilboard with fixed left-end fence, centerline pins, and replaceable tape/clamp zones | A repeatable B/C reference matters more than high clamp force; tabs must avoid nodes and arch region. | Air cut clears clamps; pilot bar length and node marks match drawing within `+/- 0.020 in`. |
| JD-030 | Flip for underside arch | Soft cradle or gasketed fixture under top face A, referenced to B and C | The tuned face cannot be dented; arch must stay centered after the flip. | C3 arch reaches target depth without center thickness dropping below `0.250 in`; no chatter or burn. |
| JD-040 | Node drilling | Drill-press fence or CNC drill cycle with backer board | Node holes are acoustic supports, not cosmetic holes; breakout or drift will damp the bar. | Hole center is within `+/- 0.020 in`; strike test shows no support buzz. |
| JD-050 | Resonator tube cutting | V-block sled with adjustable stop and note label station | Tube length changes with actual selected bore and cap style, so the jig must support trim passes. | C3/A4/C6 tubes can be cut long, capped, adjusted, and re-measured without label confusion. |
| JD-060 | Resonator mounting | Temporary rail with slotted tube mounts | Resonator position and cap access need iteration after bars are tuned. | Tubes clear bars and rails; no buzz at soft, medium, or loud strikes. |
| JD-070 | Frame supports | Temporary validation frame before furniture-grade frame | The frame should validate node paths, mallet clearance, and resonator access before final joinery. | Supports land on node positions; player reach and tube clearance pass full-size layout check. |

## Rejected Fixture Options

| Rejected option | Reason |
| --- | --- |
| One universal 37-bar CNC nest | Too much Padauk is at risk before pilot K and arch behavior are measured. |
| Clamp directly over the tuning arch region | Clamp pressure can dent the bar and bias the pitch/decay measurement. |
| Fixed-length resonator stop block from workbook proxy bore | The workbook uses width as a bore/end-correction proxy; final tube ID must be selected first. |
| Final furniture-grade frame before tuning | It hides access, makes resonator changes harder, and may lock in a bad rail path. |

## Jig Build Order

1. Build only JD-010 through JD-050 for the pilot set.
2. Cut and measure C3, A4, and C6 through `post_sand`.
3. Select actual resonator tube ID and cap/stopper style.
4. Build JD-060 as a temporary resonator rail and run `resonator_coupled` measurements.
5. Build JD-070 only after the pilot bars and resonators pass.
6. Freeze full-set CAM and rail geometry after the pilot gate.

## Validation Rows To Preserve

| Row pattern | Purpose | Release threshold |
| --- | --- | --- |
| `flat_blank` | Material K sanity check before arching. | Trend is consistent enough to update K or continue. |
| `post_arch` | CNC arch and center-thickness check. | No pilot bar violates minimum center thickness or misses by more than `+/- 15 cents` before sanding. |
| `post_sand` | Hand tuning check. | Pilot bars can approach `+/- 10 cents`. |
| `resonator_coupled` | Resonator reinforcement check. | Reinforcement improves sustain/loudness without buzz or obvious detuning. |
| `final_frame` | Full support and assembly check. | Node supports do not damp, and no hardware buzz remains. |

## Open Decisions

- Actual resonator tube material and inside diameter remain `TBD`.
- Final support method remains open: cord through holes, rubber posts, or hybrid rail pins.
- Final frame width and accidental/natural row offsets remain `TBD` until a full-size layout confirms mallet reach.
- CAM feeds/speeds and stepover must be set from the actual CNC router, bit geometry, hold-down, and dust collection setup.

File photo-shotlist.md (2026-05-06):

# Photo Shotlist

This shotlist follows the repo-level photo pipeline expectations from `instrument-maker/docs/photo-pipeline.md`: capture real process images first, use generated or supplier images only as labeled placeholders, and keep build-log image names stable enough for `site/index.html`.

## Intake And Materials

- `images/01-workbook-table.png`: screenshot of `marimba-design-table.xlsx` showing the Marimba sheet.
- `images/02-padauk-stock.jpg`: rough Padauk boards with ruler and grain direction.
- `images/03-resonator-tube-options.jpg`: tube material and cap options.
- `images/04-cnc-tooling.jpg`: ball-end mills and profile bits.

## Bar Fabrication

- `images/10-blank-layout.jpg`: labeled rough blanks before cutting.
- `images/11-thickness-check.jpg`: calipers on surfaced blank.
- `images/12-node-marking.jpg`: node positions marked on one bass and one treble bar.
- `images/13-cnc-arch-setup.jpg`: bar blank held for underside arch.
- `images/14-arch-detail.jpg`: finished underside arch with straightedge.
- `images/15-support-hole-detail.jpg`: clean support hole at node.

## Resonators And Frame

- `images/20-resonator-cutting.jpg`: tube cutting/deburring setup.
- `images/21-resonator-cap-detail.jpg`: adjustable cap or stopper.
- `images/22-frame-rail-layout.jpg`: rail layout with node/support marks.
- `images/23-dry-fit-overview.jpg`: bars, rails, and resonators dry-fit.

## Validation

- `images/30-pilot-c3-tuning.jpg`: C3 supported at nodes and measured.
- `images/31-pilot-a4-tuning.jpg`: A4 tuning reference.
- `images/32-pilot-c6-tuning.jpg`: C6 treble validation.
- `images/33-validation-log.jpg`: tuner, microphone, and `validation.csv` workflow.

## Final Documentation

- `images/40-finished-front.jpg`: full instrument front view.
- `images/41-finished-player-view.jpg`: player reach/ergonomics view.
- `images/42-resonator-underneath.jpg`: underside resonator alignment.
- `images/43-detail-beauty.jpg`: finish/detail close-up.

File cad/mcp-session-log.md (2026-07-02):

# Marimba MCP Session Log

Current status: no MCP sessions were run or verified in the Round 30 lane or
the Round 2 issue #1 recovery lane.

This log exists so future V5 work can attach provenance before promoting the
packet to a V5 build-packet candidate. Existing workbook, OpenSCAD, SVG, PDF,
and explorer artifacts are useful packet assets, but this file does not claim
that they were produced by a traceable MCP session.

| timestamp_utc | tool | session_id | artifact | parent_artifact | role | authority | notes |
| --- | --- | --- | --- | --- | --- | --- | --- |
| TBD | OpenSCAD MCP | TBD | `cad/marimba-master.scad` or exported STL | `cad/design-table-inputs.csv` | parametric CAD | prototype authority after review | Future session must confirm no magic numbers and trace dimensions to `family-spec.csv`. |
| TBD | Blender MCP | TBD | `images/hero-render.png` | reviewed OpenSCAD STL | render preview | non-fabrication | Future render only; does not prove dimensions. |
| TBD | Blender MCP | TBD | `images/exploded-diagram.png` | reviewed OpenSCAD STL | exploded diagram | non-fabrication | Future diagram only; callouts must cite design-table cells. |
| TBD | Illustrator MCP | TBD | `drawings/marimba.svg` and `drawings/marimba.dxf` | `family-spec.csv`; `cad/design-table-inputs.csv` | vector plate | fabrication after review | Full 37-bar vector export remains pending. |
| TBD | image-gen-2 / Adobe MCP | TBD | `images/family-group.png`; `images/macro/*.png` | design notes | concept imagery | non-fabrication | Concept-only; no cut-ready dimensions or toolpaths. |
| TBD | Photoshop MCP | TBD | `print-packet/assembly-plate.pdf` | `drawings/marimba-pilot-plate.dxf`; `cad/design-table-inputs.csv`; `docs/issue-1-annotated-print-plate-brief.md` | annotated print plate | pending_measurement | Issue #1 future row only. Callouts must cite registered artifacts; no Photoshop session was available in this lane. |
| 2026-07-01 | claude-code (Fable 5) | fable-v5-refresh-2026-07-01 | `README.md` | design.md, README's own prior "Readiness: L1" prose | packet_refresh | concept_only | V5 refresh pass: added a validator-parseable `Status: L1 concept packet` line to README.md (repo had no line matching the V5 Status regex before — only a "**Readiness: L1**" heading). No dimension or readiness-level change; kept existing L1/"not a V5 build-packet candidate" language as-is. Verified existing `cad/marimba-master.scad` still renders: `openscad -o /tmp/marimba-check.stl cad/marimba-master.scad`, exit 0. Did NOT rewrite the master (repo already has a real, non-placeholder master per the percussion addendum's EXISTING MASTERS rule). |
| 2026-07-01 | claude-code (Fable 5) | fable-v5-refresh-2026-07-01 | none — deferred | visual-output-register.csv | provenance_gap_note | n/a | `visual-output-register.csv` has no row for `marimba-starter.wl` / `wolfram/marimba-wolfram-model.wl` / `wolfram/instrument-model.wl` (duplicate of the latter). A register row should be added, but `visual-output-register.csv` had an uncommitted, not-mine change (one added row for `images/family-group.png`) at the start of this session — per the V5 refresh dirty-repo rule, this pass did not stage or modify that file to avoid committing someone else's uncommitted work. Follow-up: commit or triage the pending `images/family-group.png` row first, then add WL-* rows for the three Wolfram files. |

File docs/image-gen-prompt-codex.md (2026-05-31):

# Image-Gen Prompt - Marimba

Concept image only; not fabrication authority. Do not include cut-ready dimensions, node locations, resonator lengths, or CNC toolpaths.

## Hero Prompt

Photorealistic studio product photograph of a finished 37-bar C3-C6 marimba with warm African Padauk bars arranged chromatically over matched vertical quarter-wave resonator tubes, a clean CNC-made frame, visible black suspension cord at the bar nodes, and subtle parabolic underside arching hinted at on the bass bars. Show the instrument at realistic concert scale on a clean neutral studio background, three-quarter product-photography angle, soft directional studio lighting, approximately 50mm lens, high detail, natural wood grain, brushed or satin metal resonators, no logos.

## In-Context Prompt

Photorealistic image of the marimba staged in a quiet makerspace rehearsal room, with a player standing behind it holding two yarn mallets, warm daylight from high windows, a few measuring tools and tuner notebook off to the side to suggest prototype validation, Padauk bars glowing against the metal resonator bank, realistic scale and reach, natural shadows, documentary product-build atmosphere.

## Detail/Macro Prompt

Macro photorealistic close-up of one Padauk marimba bar suspended at its nodal cord holes above a resonator tube, showing smooth CNC-surfaced edges, a subtle underside tuning arch, rubber or cord isolation, and the round resonator mouth below, shallow depth of field, crisp wood grain and satin metal texture, soft raking studio light.

## Negative/Avoid

No text, no watermarks, no brand marks, no extra bars or impossible note layouts, no cut-ready dimensions, no toolpath overlays, no floating resonators, anatomically plausible hands if a player is shown.

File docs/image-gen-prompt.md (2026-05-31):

# Image-Gen Prompts

Concept image only; not fabrication authority. Do not include cut-ready dimensions, hole locations, node positions, bar lengths, arch depths, resonator lengths, tuning numbers, or toolpaths.

## Hero Prompt

Photorealistic 3/4 product photograph of a finished concert marimba: a wide graduated row of free-free wooden bars descending in length from long deep bass bars on the left to short stubby treble bars on the right, every bar cut from warm reddish-orange African Padauk with a satin oil finish that lets the straight grain read clearly, each bar suspended at its two nodal points by a cord threaded through small holes near the ends so the bars float just above the frame and ring freely, the underside of each bar carrying a centered parabolic arch undercut that is deepest on the bass bars and nearly flat on the treble, beneath each bar a vertical tuned metal resonator tube hanging like organ pipes that grow tall and long under the bass and shrink to short stubs under the treble, the whole array carried on a simple two-rail wooden shop frame that follows the curved nodal path rather than a straight line, naturals and accidentals laid out in two staggered rows like a piano keyboard, clean neutral studio background, soft directional studio light raking across the bar tops and catching the brushed metal tubes, realistic concert-instrument scale cues, ~50mm lens, high detail, photorealistic, no text labels. Avoid: no text, logos, watermarks, or fake maker marks, no dimension callouts or cut diagrams, no impossible floating bars or mismatched resonator counts. IMPORTANT: This image is a concept visualization only. Do not include dimension lines, measurements, or fabrication specifications. The image is not authoritative for any physical build dimension.

## In-Context Prompt

Photorealistic image of the C3-C6 Padauk marimba staged in a bright woodworking shop, a player standing at the keyboard side with four mallets raised mid-stroke over the graduated bars, natural window light pouring across the warm reddish bar tops and glinting off the row of metal resonator tubes hanging beneath, sawdust-dusted bench and a couple of sacrificial test bars nearby for storytelling, the curved nodal support rails and suspension cords visible where the bars float above the frame, shallow depth of field, warm workshop atmosphere, environmental storytelling, concept visualization only. Avoid: no text, logos, watermarks, or fake maker marks, no dimension callouts, no impossible mechanisms; anatomically plausible hands holding mallets naturally. IMPORTANT: This image is a concept visualization only. Do not include dimension lines, measurements, or fabrication specifications. The image is not authoritative for any physical build dimension.

## Detail Prompt

Photorealistic macro close-up of the signature mechanism: a single Padauk bar suspended at its nodal point, showing the small cord hole drilled cleanly through the bar near the support line, the cord and a rubber support isolating the bar so it touches the frame only at the node, and just below the bar the open top of a tuned quarter-wave metal resonator tube aligned under the bar center, raking light revealing the satin-oiled straight grain of the Padauk, the rounded edges, and the start of the centered parabolic underside arch curving away into shadow, brushed metal tube texture below, shallow depth of field, high detail, no measurements. Avoid: no text, logos, watermarks, or fake maker marks, no dimension callouts, no impossible mechanisms. IMPORTANT: This image is a concept visualization only. Do not include dimension lines, measurements, or fabrication specifications. The image is not authoritative for any physical build dimension.

## Negative / Avoid

No text, logos, watermarks, fake maker marks, cut diagrams, dimension callouts, node-position markings, impossible floating bars, bars touching the frame anywhere but the node, or mismatched bar/resonator counts; anatomically plausible hands if a player is shown.

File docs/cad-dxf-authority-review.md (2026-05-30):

# Marimba CAD/DXF Authority Review

Status: reviewed V5 packet surface, with CAD/DXF authority marked
`pending_measurement`. This does not promote the packet to build-ready, L3,
CAM-ready, or full-family DXF authority.

Issue #5 asks for reviewed design-table traceability and one pilot DXF check
while keeping the work distinct from the print-plate-specific issue. The
current review scope is the existing `drawings/marimba-pilot-plate.dxf`, which
covers C3, A4, and C6 only. The issue #5 register is
[`v5-authority-register.csv`](v5-authority-register.csv).

## Authority Chain

| Artifact | Role | Current boundary |
| --- | --- | --- |
| `cad/design-table-inputs.csv` | Design-table parent for C3-C6 workbook-derived dimensions | `pending_measurement`; reviewed as packet input until measured tuning revises the schedule. |
| `family-spec.csv` | Family note schedule and resonator estimates | `pending_measurement`; prediction-level; no measured pitch data is logged yet. |
| `cad/marimba-master.scad` | Current CAD surface | `pending_measurement`; concept/prototype CAD only, not native CAD authority. |
| `drawings/marimba-pilot-plate.dxf` | Pilot DXF for C3/A4/C6 bar outlines and node locations | `pending_measurement`; reviewable pilot geometry only; not a full 37-bar export and not CAM-ready. |
| `scripts/validate_marimba_pilot_dxf.py` | Repo-local DXF traceability check | Confirms DXF outline length, width, and node X positions match the design table. |
| `validation.csv` | Measurement ledger | Empty measured fields; no measured tuning, cents-error, sustain, or resonator-coupling authority. |

## Pilot DXF Check

Run from the repo root:

```bash
python3 scripts/validate_marimba_pilot_dxf.py
```

The check verifies:

- DXF units are inches via `$INSUNITS=1`.
- C3, A4, and C6 bar outline bounding boxes match
  `cad/design-table-inputs.csv`.
- C3, A4, and C6 support-node X positions match the same design-table rows.
- DXF labels include the member ID, note, frequency, length, and width.

The check does not verify:

- CAM toolpaths, feeds, speeds, tabs, fixturing, or cutter compensation.
- Underside arch surfaces, resonator fabrication, or frame geometry.
- Measured tuning, cents error, sustain, or resonator coupling.
- The full 37-bar DXF export.

## Issue Boundary

This lane is intentionally separate from the print-plate issue. It validates a
pilot DXF against CAD/design-table inputs and records that boundary in the
authority register. Annotated print plates, rendered assembly pages, and PDF
layout work remain separate downstream deliverables.

This lane also records the honesty boundary in
[`issue-5-v5-packet-surface.md`](issue-5-v5-packet-surface.md): no MCP tools,
shop measurements, native CAD session, CAM review, or tuning evidence were
available, so the packet surface is organized but not promoted to fabrication
authority.

## Promotion Gates

Before this packet can claim broader fabrication authority:

- Run and review the C3/A4/C6 pilot loop in `validation.csv`.
- Record measured flat-blank, post-arch, post-sand, resonator-coupled, and
  final-frame pitch results for the pilot bars.
- Review or regenerate the full 37-bar DXF from the same table source.
- Add CAM review evidence before treating any DXF as shop-ready toolpath input.

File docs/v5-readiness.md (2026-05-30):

# Marimba V5 Readiness Notes

Current readiness: V5 explorer/prototype scaffold with issue #5 authority
register, not a V5 build-packet candidate yet.

The repo has a strong v4 packet base: workbook-derived note schedule,
OpenSCAD starter, SolidWorks-ready CSVs, SVG drawing previews, CNC operation
planning, print packet, and an explorer page. The missing V5 evidence is
mostly provenance, full export coverage, and measured pilot validation.

## Evidence Present

| Area | Current artifact | Readiness posture |
| --- | --- | --- |
| Parametric CAD starter | `cad/marimba-master.scad` | Prototype geometry starter, not native CAD or CAM verified. |
| Design table | `cad/design-table-inputs.csv`, `cad/sw-global-variables.csv`, `family-spec.csv` | Workbook-derived prototype authority until pilot data revises it. |
| Vector previews | `drawings/*.svg` | Derived previews from the note schedule, not DXF/CAM release. |
| Issue #5 authority register | `docs/v5-authority-register.csv`, `docs/issue-5-v5-packet-surface.md` | Reviewed packet surface; CAD/DXF/design-table authority is explicitly pending measurement. |
| Pilot DXF | `drawings/marimba-pilot-plate.dxf`, `scripts/validate_marimba_pilot_dxf.py`, `docs/cad-dxf-authority-review.md` | C3/A4/C6 layout now has a repo-local design-table trace check; full 37-bar export, CAM review, and measured tuning remain pending. |
| Validation plan | `validation.csv`, `validation-loop.csv`, `cnc/operations.csv` | Measurement-required; no bar tuning results logged yet. |
| Explorer | `explorer.html` | Present and updated with authority/provenance files. |
| Capstone manifest | `capstone-manifest.json` | Repo-relative artifact inventory. |

## V5 Deliverable Gate

| V5 deliverable from issue #2 | Status in this lane | Remaining gate |
| --- | --- | --- |
| Parametric CAD master | Partial | Review/update `cad/marimba-master.scad` so every critical dimension is programmatically traced to the tables. |
| Vector design plate plus DXF | Partial | `drawings/marimba-pilot-plate.dxf` covers pilot bars only; full `drawings/marimba.dxf` remains pending. CAD/DXF authority is `pending_measurement` in `docs/v5-authority-register.csv`. |
| Hero render | Missing | Create from reviewed CAD/STL and register as non-fabrication. |
| Exploded diagram | Missing | Create from reviewed CAD/STL and register as non-fabrication. |
| AI artistic shots | Missing | Create only as concept/story support; no dimensional authority. |
| Annotated print plate | Scaffolded only | `docs/issue-1-annotated-print-plate-brief.md` and register rows define the Photoshop-MCP contract; no plate was generated. |
| MCP provenance log | Scaffolded | `cad/mcp-session-log.md` has placeholder rows; future MCP sessions must replace TBD values. |

## Honesty Boundary

- Do not label this repo `V5 build-packet candidate` until the missing V5
  deliverables exist and are logged.
- Do not label tuning as measured or validated until `validation.csv` contains
  measured Hz and cents-error results.
- Do not use generated images or renders as fabrication authority.
- Do not release the full 37-bar CNC sequence until the C3/A4/C6 pilot loop is
  measured and reviewed.
- The pilot DXF traceability check confirms outline and node dimensions against
  `cad/design-table-inputs.csv`; it does not validate CAM, toolpaths, arch
  machining, frame geometry, resonator coupling, or measured tuning.
- Do not claim a Photoshop-MCP annotated print plate exists until a real
  session creates or reviews `print-packet/assembly-plate.pdf` and logs
  provenance in `cad/mcp-session-log.md`.
- Do not promote `cad/marimba-master.scad` or `drawings/marimba-pilot-plate.dxf`
  beyond `pending_measurement` until real shop measurements and CAD/CAM review
  are recorded.

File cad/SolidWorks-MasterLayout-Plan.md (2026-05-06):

# SolidWorks MasterLayout Plan

## Purpose

This folder is a handoff contract for native SolidWorks work. It does not claim a `.SLDPRT` or `.SLDASM` exists yet. The goal is to make the future SolidWorks model deterministic: master sketch, global equations, and design table all use the same variable names as the CSV files in this repo.

## Recommended File Set

```text
MAR-000_MasterLayout.SLDASM
MAR-001_Bar_Master.SLDPRT
MAR-002_Resonator_Master.SLDPRT
MAR-003_Frame_Master.SLDPRT
```

## Configuration Strategy

Use one bar/resonator configuration per `member_id` from `family-spec.csv`.

Primary input table:

```text
cad/design-table-inputs.csv
```

Global variable registry:

```text
cad/sw-global-variables.csv
```

## Master Sketch Hierarchy

```text
MAR-000_MasterLayout
|-- SK_MASTER_TOP_VIEW
|   |-- player_side_datum
|   |-- bass_bar_left_datum
|   |-- natural_row_centerline
|   |-- accidental_row_centerline
|   |-- bass_rail_curve
|   `-- treble_rail_curve
|-- SK_BAR_ENVELOPE
|   |-- bar_length_in
|   |-- bar_width_in
|   |-- node_1_in
|   `-- node_2_in
|-- SK_ARCH_SECTION
|   |-- edge_thickness_in
|   |-- center_thickness_in
|   |-- arch_depth_in
|   |-- arch_length_ratio
|   `-- ball_end_bit_diameter_in
`-- SK_RESONATOR_LAYOUT
    |-- resonator_length_in
    |-- resonator_bore_in
    |-- resonator_mount_clearance_in
    `-- tube_cap_allowance_in
```

## Required Global Variables

Minimum globals:

- `bar_note`
- `midi`
- `target_frequency_hz`
- `bar_length_in`
- `bar_width_in`
- `edge_thickness_in`
- `center_thickness_in`
- `arch_depth_in`
- `node_1_in`
- `node_2_in`
- `cord_hole_diameter_in`
- `resonator_length_in`
- `resonator_bore_in`
- `resonator_mount_clearance_in`
- `tube_cap_allowance_in`
- `bar_spacing_in`
- `natural_row_offset_in`
- `accidental_row_offset_in`
- `frame_rail_width_in`
- `frame_rail_height_in`
- `ball_end_bit_diameter_in`
- `stepover_in`
- `stock_allowance_length_in`
- `tab_allowance_in`

## Feature Notes

- Bar master should expose the top rectangle, side profile, underside arch section, node holes, and optional tab geometry.
- Resonator master should expose tube OD/ID, length, cap/stopper allowance, and mounting clearance.
- Frame master should remain flexible until bar spacing and resonator bore are confirmed.
- Avoid fixing accidental/natural row geometry too early; first validate bar and resonator physics.

## Verification

After native CAD exists, run Tony's SolidWorks dimension extraction macro and compare its CSV against this repo:

```text
cad/dimensions/<date>-MAR-000-dimensions.csv
```

The useful checks are:

- Every global equation has a matching CSV input.
- No feature dimension bypasses the master sketch.
- Node hole positions agree with `family-spec.csv`.
- Resonator length and bore agree with the selected sourcing revision.

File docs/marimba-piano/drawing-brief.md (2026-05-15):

# Drawing Brief

Current drawing authority: future. This packet has no fabrication-authority CAD, DXF, or reviewed dimensioned drawings yet.

Generated images and sketches are concept/reference only. They must not be used for cut-ready dimensions, hole locations, toolpaths, hammer centers, aperture centers, or resonator lengths.

## Future Authority Drawings

### D001: P0 Bench Coupon Assembly

Purpose: prove one key, hammer, bar, aperture, gasket, resonator, and platen clamp.

Must show:

- Pivot locations.
- Adjustable hammer strike point.
- Bar support node positions.
- Aperture plate and gasket stack.
- Resonator height adjustment.
- Clamp throw and hard stop.

Authority target: first fabrication drawing after dimensions are selected from available stock.

### D002: Three-Face Hammer Head

Purpose: define the manually indexed P0 hammer head and later P1 selector-compatible head.

Must show:

- Face insert pockets.
- Indexing detent geometry.
- Retention method for soft and hard faces.
- Strike radius and clearance envelope.

Authority target: CAD or measured drawing after face material samples are chosen.

### D003: 13-Note Voice Cassette

Purpose: define a removable C4-C5 tone-bar and aperture module.

Must show:

- Bar centerline map.
- Node support positions.
- Aperture centerline map.
- Gasket pockets.
- Tapered registration features.
- Platen contact surfaces.

Authority target: future CAD/DXF only after P0 and early P1 measurements.

### D004: Adjustable Resonator Bed

Purpose: define independent, adjustable pipe support.

Must show:

- Pipe centerlines.
- Standoff and spring locations.
- Adjustment range.
- Alignment pins or V-blocks.
- Clearance for straight, bent, and downward-facing pipe experiments.

Authority target: future CAD/DXF after aperture tests show the needed pipe bank strategy.

### D005: Platen Lever and Interlock

Purpose: make the cassette clamping safe and repeatable.

Must show:

- Lever throw.
- Cam or toggle geometry.
- Over-center or lock position.
- Adjustable hard stop.
- Guarding and cassette-removal interlock.

Authority target: future mechanical drawing after P0 clamp force is known.

### D006: Hammer Selector Rail

Purpose: define the left-side selector that changes hammer faces across the row.

Must show:

- Rest-state engagement.
- 120-degree index positions.
- Detent locations.
- Clearance during hammer travel.
- Manual override or service release.

Authority target: defer until one-note and three-note selector tests pass.

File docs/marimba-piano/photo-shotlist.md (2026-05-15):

# Photo Shotlist

Use these only for build documentation. Avoid private location or personal details if the packet is published.

- Original sketch beside the P0 coupon, labeled as concept/reference only.
- One-note bar support close-up showing node locations.
- Hammer head face samples before installation.
- Hammer head selected to each face position.
- Aperture inserts side by side.
- Gasket before and after clamp cycling.
- Resonator tube adjustment detail.
- Platen lever unclamped and clamped.
- Tuner or spectrum screenshot for each P0 measurement.
- P1 cassette sliding into the chassis.
- Witness marks or pressure paper showing seal uniformity.

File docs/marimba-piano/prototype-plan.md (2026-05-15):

# Prototype Plan

## P0: One-Note Truth Coupon

Goal: prove the architecture before committing to a keyboard-width mechanism.

Build:

- One key or lever.
- One hammer with a manually indexed three-face head.
- One removable bar holder.
- One tone bar, starting with A4 or C5.
- One aperture plate with replaceable aperture inserts.
- One resonator tube with adjustable height.
- One mini platen clamp that compresses the gasket.

Measure:

- Bar pitch alone.
- Resonator pitch alone.
- Coupled note pitch, loudness, and sustain.
- Cents error from target.
- Gasket leakage by listening and by comparing clamped versus unclamped level.
- Hammer attack character for each face.
- Rebound and double-strike behavior.
- Mechanical noise.

Pass condition:

- The note speaks cleanly.
- The cassette can be removed and reinstalled three times with no more than 5 cents pitch/coupling shift.
- At least two hammer faces produce clearly different recorded attacks without causing unreliable rebound.

## P1: 13-Note C4-C5 Module

Goal: prove registration, repeatability, and player ergonomics across a small keyboard span.

Build:

- 13 keys, C4 through C5.
- 13 hammer assemblies.
- One wood or synthetic voice cassette.
- One test aperture set.
- One resonator bank with adjustable float.
- Right-side platen lever.
- Left-side hammer selector, initially allowed to be a slower indexed service control rather than a performance control.

Measure:

- Per-note tuning.
- Bar support noise.
- Strike alignment at rest and after cassette swaps.
- Platen compression uniformity across the width.
- Resonator balance across low and high notes.
- Whether hammer selector changes all notes evenly.

Pass condition:

- All notes play without missed strikes or double strikes.
- Cassette swap returns hammer-to-bar alignment within a visible target window.
- Resonator seal remains stable after repeated clamping.
- At least one complete cassette is playable enough for musical testing.

## P2: Second Voice Cassette

Goal: prove the instrument is actually modular, not just removable.

Build one contrasting cassette:

- If P1 used wood, make P2 aluminum or synthetic.
- If P1 used aluminum, make P2 wood.

Test:

- Same chassis and hammer row.
- Same resonator bank first.
- Alternate aperture inserts before building a second pipe bank.
- Second pipe bank only if measurements show the first bank cannot support the new material.

## P3: Extended Keyboard

Goal: scale only after the mechanics stop changing.

Candidate ranges:

- 25 notes for a compact lap/bench instrument.
- 37 notes for a small performance instrument.
- 49 or 61 notes only after action weight, selector torque, and resonator packaging are proven.

Promotion requirement:

- CAD/DXF authority exists for the chassis, cassette, action, selector, resonator bed, and platen.
- Validation rows for tuning, seal, safety, and repeatability are closed or have explicit tolerances.

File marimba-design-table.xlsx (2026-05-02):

Marimba — CNC Bar & Arch Design Table |  |  |  |  |  |  |  |  |  |  | BUILD SPECIFICATIONS |  |  | MATERIAL LIBRARY
Free-Free Beam Model: f = K × t / L² · λ₁ = 4.730 · Nodes at 22.4% from each end |  |  |  |  |  |  |  |  |  |  |  | Full 4.5-Octave (C2-F6) | Portable 2.5-Octave (C4-F6) | Wood Species | E (GPa) | ρ (kg/m³) | K (marimba) | Use
 |  |  |  |  |  |  |  |  |  |  | Range | C2-F6 (54 bars) | C4-F6 (30 bars) | Honduras Rosewood | 16.1 | 1050 | 158466 | Professional standard
Note | MIDI | Freq (Hz) | Bar Length (in) | Bar Length (mm) | Width (in) | Node 1 (in) | Node 2 (in) | Arch Depth (in) | Center Thick (in) | Resonator (in) | Frame Length | ~8 feet | ~4 feet | African Padauk | 11.0 | 745 | 155502 | Pro alternative to rosewood
C3 | 48 |  |  |  | 2.00 |  |  |  |  |  | Longest Bar | ~32" (C2) | ~16" (C4) | Purpleheart | 15.4 | 860 | 171249 | Bright, hard
C#3 | 49 |  |  |  | 2.00 |  |  |  |  |  | Shortest Bar | ~5" (F6) | ~5" (F6) | Hard Maple | 12.6 | 705 | 171084 | Workshop/education builds
D3 | 50 |  |  |  | 2.00 |  |  |  |  |  | Bar Thickness | 7/8" (add glue blocks for C2-D#3) | 7/8" uniform | Cherry | 10.3 | 560 | 173557 | Warm tone, easy to work
D#3 | 51 |  |  |  | 2.00 |  |  |  |  |  | Material (lbf) | ~40 bd ft Padauk | ~12 bd ft Padauk | Black Walnut | 11.6 | 610 | 176475 | Rich dark tone
E3 | 52 |  |  |  | 2.00 |  |  |  |  |  | Resonators | 54 PVC tubes (Sch 20) | 30 PVC tubes (Sch 20) | Wenge | 15.8 | 870 | 172459 | Very resonant, splinters easily
F3 | 53 |  |  |  | 2.00 |  |  |  |  |  | Resonator Bore | 4" PVC bass, 2" PVC treble | 3" PVC bass, 1.5" treble | Mahogany | 10.1 | 590 | 167438 | Warm, can crack over time
F#3 | 54 |  |  |  | 2.00 |  |  |  |  |  | Rail Spacing | Graduated, 22.4% of each bar | Graduated, 22.4% of each bar | Synthetic (Kelon/FRP) | 20.0 | 1800 | 134895 | Weather-resistant, outdoor use
G3 | 55 |  |  |  | 2.00 |  |  |  |  |  | Cord Hole Diameter | 1/4" at node positions | 1/4" at node positions
G#3 | 56 |  |  |  | 2.00
A3 | 57 |  |  |  | 2.00 |  |  |  |  |  | CNC ARCH CUTTING SPECS
A#3 | 58 |  |  |  | 2.00 |  |  |  |  |  | Parameter | Value | Notes
B3 | 59 |  |  |  | 2.00 |  |  |  |  |  | Arch Profile | Parabolic | depth(x) = d_max × (1 - (2x/L_arch)²)
C4 | 60 |  |  |  | 1.75 |  |  |  |  |  | Arch Length | 60% of bar length | Centered on bar middle
C#4 | 61 |  |  |  | 1.75 |  |  |  |  |  | Ball-End Mill Diameter | 0.750" | 3/4" for bass, 1/2" for treble
D4 | 62 |  |  |  | 1.75 |  |  |  |  |  | Step-Over | 50% of bit diameter | 0.375" passes for 3/4" bit
D#4 | 63 |  |  |  | 1.75 |  |  |  |  |  | Depth per Pass | 0.125" | 1/8" max per CNC pass
E4 | 64 |  |  |  | 1.75 |  |  |  |  |  | Feed Rate | 40 ipm | Padauk/rosewood; 60 ipm for softer woods
F4 | 65 |  |  |  | 1.75 |  |  |  |  |  | Spindle Speed | 18,000 RPM | Ball-end mill in hardwood
F#4 | 66 |  |  |  | 1.75 |  |  |  |  |  | Holding Method | Vacuum table + clamps | Bar must not shift during arch cut
G4 | 67 |  |  |  | 1.75 |  |  |  |  |  | Passes for 0.625" arch | 5 passes
G#4 | 68 |  |  |  | 1.75
A4 | 69 |  |  |  | 1.75 |  |  |  |  |  | BAR DIMENSIONS CALCULATOR
A#4 | 70 |  |  |  | 1.75 |  |  |  |  |  | Selected Material | African Padauk | ← Pick from library above
B4 | 71 |  |  |  | 1.75 |  |  |  |  |  | K Constant
C5 | 72 |  |  |  | 1.50 |  |  |  |  |  | Bar Thickness (in) | 0.875 | ← 7/8" standard
C#5 | 73 |  |  |  | 1.50 |  |  |  |  |  | Min Center Thickness (in) | 0.250 | ← 1/4" minimum for durability
D5 | 74 |  |  |  | 1.50
D#5 | 75 |  |  |  | 1.50
E5 | 76 |  |  |  | 1.50
F5 | 77 |  |  |  | 1.50
F#5 | 78 |  |  |  | 1.50
G5 | 79 |  |  |  | 1.50
G#5 | 80 |  |  |  | 1.50
A5 | 81 |  |  |  | 1.50
A#5 | 82 |  |  |  | 1.50
B5 | 83 |  |  |  | 1.50
C6 | 84 |  |  |  | 1.25
C#6 | 85 |  |  |  | 1.25
D6 | 86 |  |  |  | 1.25
D#6 | 87 |  |  |  | 1.25
E6 | 88 |  |  |  | 1.25
F6 | 89 |  |  |  | 1.25
F#6 | 90 |  |  |  | 1.25
G6 | 91 |  |  |  | 1.25
G#6 | 92 |  |  |  | 1.25
A6 | 93 |  |  |  | 1.25
A#6 | 94 |  |  |  | 1.25
B6 | 95 |  |  |  | 1.25
C7 | 96 |  |  |  | 1.25
WOLFRAM CLOUD NOTEBOOK SPEC — MARIMBA
Companion notebook to this design sheet. Build in Wolfram Cloud — deploy as interactive bar/arch/resonator calculator.
§1 — HISTORY, ETYMOLOGY & ORIGIN
Origin: West/Central Africa (likely Bantu); 'marimba' from Bantu 'rimba' (xylophone bar) with prefix 'ma-' (plural). Carried to Latin America via the trans-Atlantic slave trade, 16–17th c.
Modern concert marimba: developed in Guatemala (chromatic version, ~1894 — Sebastián Hurtado) and refined in early-20th-c USA (Deagan, Musser). National instrument of Guatemala.
Wolfram items: GeoGraphics map of Bantu migration + Guatemala/Mexico/USA development arc. TimelinePlot[{1500,1894,1916,1950}→events]. Entity["MusicalInstrument","Marimba"].
§2 — PHYSICS & ACOUSTICS
Governing law: Euler–Bernoulli free-free beam. Mode 1: λ₁ = 4.730. f ∝ (t/L²)·√(E/ρ). Modes are inharmonic for a flat bar (f₂/f₁ ≈ 2.76).
Arch undercut tuning: parabolic relief on underside lowers f1 without shortening L; tunes f2 toward 4×f1 (octave + 2). f3 toward 10×f1. This is what gives marimba its singing tone vs. xylophone's 3×.
Node positions (mode 1): 22.4% and 77.6% of bar length — cord holes drilled here so the bar floats freely.
Resonator coupling: closed quarter-wave tube under each bar at L_tube = c/(4f) − 0.82·bore. Strong amplitude boost when tuned within ±3% of bar fundamental; sharp Q peak.
Wolfram functions: NDEigensystem on the beam PDE EI·∂⁴y/∂x⁴ + ρA·∂²y/∂t² = 0 with free-free BCs. Returns mode shapes and eigenfrequencies for any t(x) profile (i.e. arched bar).
Wolfram functions: NSolve / FindRoot for resonator length; ParametricNDSolveValue to sweep arch shape vs. f2/f1 ratio; Periodogram + Spectrogram for measured-bar validation.
§3 — GEOMETRY & DESIGN MODEL
Bar profile: thickness t(x) = t_edge for |x−L/2| > arch_half; t_edge − (t_edge−t_center)·(1 − ((x−L/2)/arch_half)²) inside the arched zone. Center thickness ≥ 0.25" structural minimum.
Resonator tubes: stepped lengths from longest (low C3) to shortest (high C7). Mount under bar centers with adjustable plug for fine-tune.
Wolfram items: ParametricPlot[t(x)] cross-section + RevolutionPlot3D for resonator. Manipulate[ ] sliders: t_edge, t_center, arch_width, L. Live recompute of f1, f2, f2/f1 ratio.
Wolfram items: Graphics3D exploded view of one bar + cord + resonator + frame; Animate[ ] mode shapes (n=1,2,3) overlaid on the bar geometry.
§4 — MATERIAL PROPERTIES & CORRECTION FACTORS
Honduran Rosewood (Dalbergia stevensonii) — the gold standard: ρ≈1000 kg/m³, E≈16 GPa, very low internal damping. Padauk and Bubinga are common substitutes; synthetic Kelon for school/outdoor.
K constant (imperial, free-free) ≈ K_cantilever × (4.730/1.875)² ≈ K_cantilever × 6.36. Use materials block in this sheet (cells around Q28:Q30) as authoritative inputs.
Correction factors: humidity shifts pitch ~±5 cents over a season; temperature dependence weak for wood, larger for aluminum bars; bar end condition (chamfer/radius) shifts mode 1 by ~0.5%.
Wolfram items: Entity["Material",…]["YoungModulus"|"Density"]; Quantity / UnitConvert; Around[ ] for material variability (Rosewood E = Around[16, 2] GPa).
§5 — ANIMATED PARTS DIAGRAMS & EXECUTABLE STUBS
kBar[E_,ρ_]:=(4.730^2/(2 π)) Sqrt[E/(12 ρ)] / 0.0254 (* imperial K *)
fBar[t_,L_,K_]:=K t/L^2; Lbar[f_,t_,K_]:=Sqrt[K t/f]
lRes[f_,bore_]:=13552/(4 f) - 0.82 bore (* in *)
archedBeamModes := NDEigensystem[{D[E I[x] D[y[x],{x,2}],{x,2}] - ρ A[x] ω^2 y[x], (free-free BCs)}, y, {x,0,L}, 5]
Animate[Plot[ shape_n[x] Cos[2π f_n t], {x,0,L}], {t,0,2/f_1}] for each mode; Grid[ ] them as a 5×1 panel.
§6 — BOM, MAP & DEPLOYMENT
Import bar list from this sheet via SemanticImport["Flutes-AI.xlsx","Marimba"]. Compute total rosewood board-feet via Total[L·w·t]. Cost roll-up by species.
Map: GeoGraphics over Africa→Mesoamerica showing instrument diffusion. Inset: Guatemala highlighted (chromatic marimba origin).
Wolfram functions: SemanticImport, Dataset, GroupBy, GeoGraphics, GeoMarker, CloudDeploy[Manipulate[ ]], FormFunction, APIFunction, Export["…","MP4"|"GIF"|"CDF"].
WOLFRAM EXPLORATIONS — MARIMBA
Curated from the wolfram-notebooks-roadmap brainstorm — pick a row, file an issue, build the notebook.
Roadmap-inspired notebook ideas tailored to this sheet:
• Cantilever-vs-Free-Free Mode Shape Animator (NDSolve) — Animate first 5 modes side-by-side for both BCs; SEE why 22.4% nodes matter and why arch undercut tunes mode 4 separately.
• Arch-Undercut Optimizer (NMinimize) — Given target f and partial ratios (1:4:10), find arch-depth profile that hits all three; constraint: center thickness ≥ 0.25".
• 17-Tonewood Material Scatter (Publication) — Interactive ListPlot E vs ρ, point size = K, color by tonewood-rating ★; click point → live recompute bar lengths.
• Resonator Tube Coupling Model — Coupled bar+tube oscillator; sweep tube length detune ±5% to show sweet-spot Q.
• Tolerance Stack-Up (Monte Carlo) — ±0.005" bar thickness + ±0.02" length → pitch error distribution; how tight does the planer need to be?
• Wood Grain Orientation Effect — Rotate bar grain 0°→90° and quantify K shift — informs blank orientation on the lathe/planer.

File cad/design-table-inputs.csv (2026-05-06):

configuration | description | bar_note | midi | target_frequency_hz | bar_length_in | bar_width_in | edge_thickness_in | center_thickness_in | arch_depth_in | node_1_in | node_2_in | resonator_length_in | resonator_bore_in | stock_allowance_length_in | tab_allowance_in
MAR-C3 | C3 marimba bar/resonator | C3 | 48 | 130.813 | 32.251 | 2.000 | 0.875 | 0.250 | 0.625 | 7.224 | 25.027 | 24.260 | 2.000 | 0.750 | 0.250
MAR-Csharp3 | C#3 marimba bar/resonator | C#3 | 49 | 138.591 | 31.333 | 2.000 | 0.875 | 0.263 | 0.612 | 7.019 | 24.315 | 22.806 | 2.000 | 0.750 | 0.250
MAR-D3 | D3 marimba bar/resonator | D3 | 50 | 146.832 | 30.441 | 2.000 | 0.875 | 0.276 | 0.599 | 6.819 | 23.622 | 21.434 | 2.000 | 0.750 | 0.250
MAR-Dsharp3 | D#3 marimba bar/resonator | D#3 | 51 | 155.563 | 29.575 | 2.000 | 0.875 | 0.289 | 0.586 | 6.625 | 22.950 | 20.139 | 2.000 | 0.750 | 0.250
MAR-E3 | E3 marimba bar/resonator | E3 | 52 | 164.814 | 28.733 | 2.000 | 0.875 | 0.302 | 0.573 | 6.436 | 22.297 | 18.917 | 2.000 | 0.750 | 0.250
MAR-F3 | F3 marimba bar/resonator | F3 | 53 | 174.614 | 27.915 | 2.000 | 0.875 | 0.315 | 0.560 | 6.253 | 21.662 | 17.763 | 2.000 | 0.750 | 0.250
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

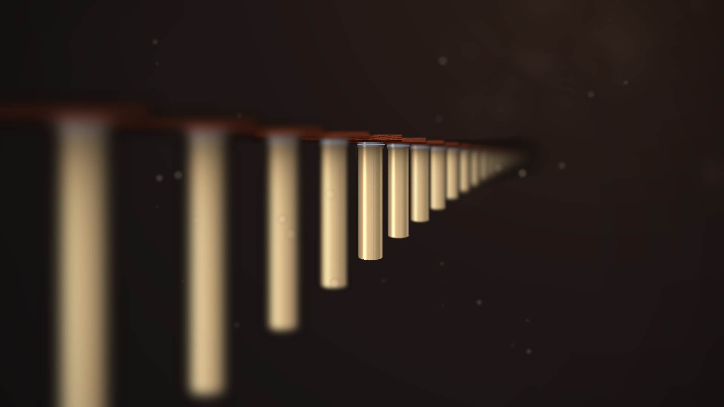
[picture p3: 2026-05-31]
images/macro/resonator-tube-array.png

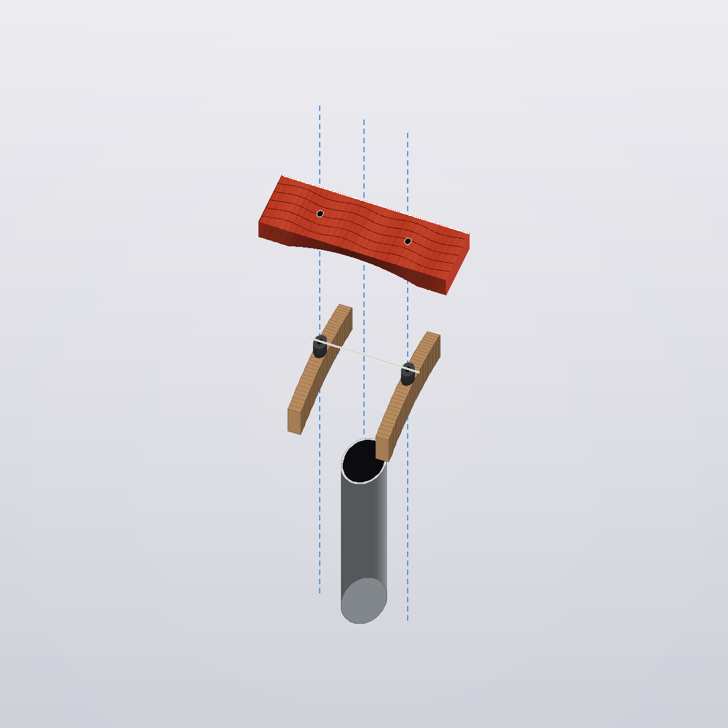
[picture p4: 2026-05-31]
images/exploded-diagram.png

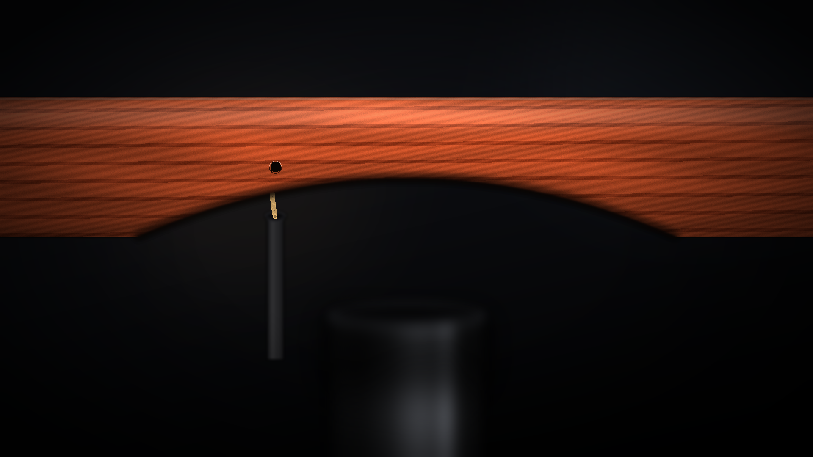
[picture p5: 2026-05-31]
images/macro/bar-node-suspension.png

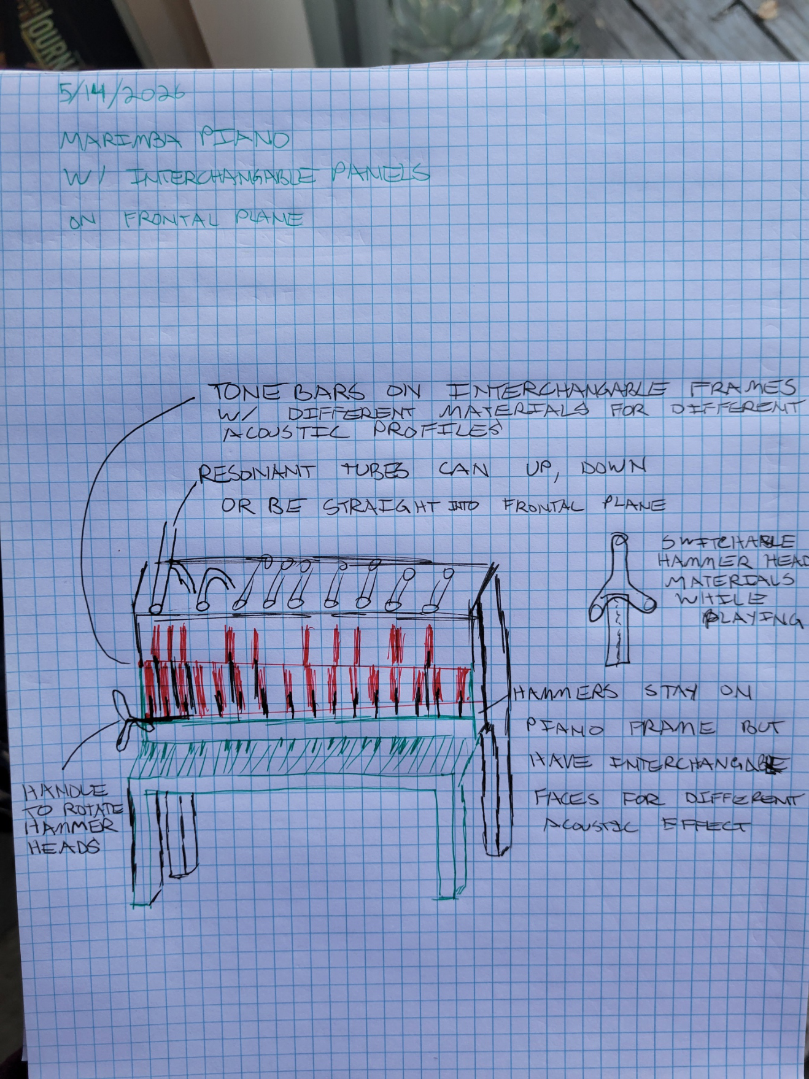
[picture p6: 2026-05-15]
docs/marimba-piano/references/sketch-20260514.jpg

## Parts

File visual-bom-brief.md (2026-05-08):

# Visual BOM Brief

## Goal

Create a visual BOM plate that lets another maker understand the marimba build at a glance: bars, resonators, support hardware, frame rails, tooling, and measurement gear.

## Required Views

1. Hero view of the assembled C3-C6 marimba on a simple shop frame.
2. Exploded view showing bars above resonator tubes above frame rails.
3. Detail inset for one bar: node holes, underside arch, grain direction.
4. Detail inset for one resonator: tube, cap/stopper, mounting clearance.
5. Detail inset for the pilot jig set: two-sided spoilboard, arch cradle, node-drilling backer, tube V-block.
6. Material swatches: Padauk bar wood, tube material, rubber supports, frame wood, MDF/plywood fixture stock.

## BOM Rows To Show

| Item | Visual Needed | Source |
| --- | --- | --- |
| Tuned Padauk bars | Actual shop photo once cut; concept placeholder acceptable before build | `family-spec.csv` |
| Resonator tubes | Supplier image or shop photo | `sourcing.csv` |
| Support cord | Supplier image or shop photo | `bom.csv` |
| Rubber supports | Supplier image or shop photo | `bom.csv` |
| Frame rails | CAD render or shop photo | `cad/` |
| Pilot jigs | CAD render, shop photo, or drawing placeholder | `jig-decision.md` |
| CNC bits | Supplier image or shop photo | `bom.csv` |
| Tuning tools | Shop photo | `validation.csv` workflow |

## Labeling Rules

- Label generated images as concept placeholders.
- Do not use generated images for exact dimensions.
- Every dimension callout must match `family-spec.csv` or be marked `TBD`.
- Keep supplier prices out of the visual until current quotes are verified.

## First Plate Layout

Top: title, date, range, and material.

Middle left: exploded assembly with numbered callouts.

Middle right: BOM table grouped by bars, resonators, frame, hardware, tooling.

Bottom: assumptions and missing purchase-verification items.

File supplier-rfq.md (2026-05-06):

# Supplier RFQ - Marimba C3-C6 Build

## Scope

Request quotes for one 37-bar C3-C6 marimba prototype build. Prices, stock, and lead times are intentionally not assumed in this repo; verify current facts before purchasing.

## Bar Lumber

Please quote clear straight-grain African Padauk suitable for tuned percussion bars.

Required:

- Final thickness after surfacing: `0.875 in`.
- Longest finished bar: `32.251 in`.
- Widest finished bar: `2.000 in`.
- Preferred rough allowance: at least `34 in x 2.25 in x 1.00 in` for the longest bass blanks.
- Quantity: enough for 37 bars plus at least 3 pilot/scrap bars.
- Grain: straight, stable, no checks through the finished bar area.
- Moisture content: provide measured or estimated value.

Alternates:

- Hard maple for education/prototype comparison.
- Cherry for easier machining comparison.

Do not substitute material directly into the build schedule without updating the K constant and validating pitch.

## Resonator Tubes

Please quote PVC or aluminum tube options for 37 quarter-wave resonators.

Required quote data:

- Material.
- Nominal size.
- Actual ID and OD.
- Wall thickness.
- Available lengths.
- Compatible caps, plugs, or stopper hardware.
- Cutting service availability.

The first-pass length range in this packet is about `2.2 in` to `24.3 in`, before oversize tuning allowance. Actual lengths must be recalculated if bore differs from the workbook proxy.

## Hardware

Please quote:

- Low-stretch support cord or equivalent.
- Rubber or silicone tubing/grommets for support isolation.
- Frame fasteners suitable for removable tuning access.
- Optional threaded inserts for rail/cross-member joints.

## CNC Tooling

Please quote:

- 3/4 in carbide ball-end mill, hardwood capable.
- 1/2 in carbide ball-end mill, hardwood capable.
- 1/4 in downcut spiral router bit.
- 1/8 in upcut spiral router bit.

Include shank diameter, cut length, recommended feed/speed range, and replacement availability.

## Response Format

Please return:

```text
item
supplier part number
material/spec
actual dimensions
quantity available
unit price
lead time
shipping estimate
notes/substitution risks
```

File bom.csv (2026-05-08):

item | subassembly | part_name | qty | unit | material_or_spec | make_buy | status | notes
1 | Bar set | C3-C6 tuned bars | 37 | ea | African Padauk 7/8 in nominal edge thickness | make | workbook-derived | Individual dimensions in family-spec.csv.
2 | Resonators | C3-C6 resonator tubes | 37 | ea | PVC or aluminum tube; bore TBD by sourcing | buy | TBD | Lengths in family-spec.csv are first-pass quarter-wave values using workbook bore proxy.
3 | Resonators | Tube caps or adjustable stoppers | 37 | ea | Matched to selected tube bore | buy | TBD | Use adjustable closure for first validation build.
4 | Frame | Bass-side rail | 1 | ea | Hard maple or laminated hardwood | make | TBD | Final length and curve depend on CAD frame layout.
5 | Frame | Treble-side rail | 1 | ea | Hard maple or laminated hardwood | make | TBD | Must follow support nodes or carry adjustable posts.
6 | Frame | Cross members | 4 | ea | Hardwood or plywood fixture stock | make | TBD | Temporary shop frame acceptable for validation build.
7 | Hardware | Support cord | 1 | roll | Low-stretch braided cord or synthetic marimba cord | buy | TBD | Size to match 1/4 in node holes and rubber isolators.
8 | Hardware | Rubber support tubing or grommets | 74 | ea | Rubber or silicone isolation supports | buy | TBD | Two supports per bar minimum.
9 | Hardware | Frame fasteners | 1 | set | Wood screws, threaded inserts, washers | buy | TBD | Prefer removable fasteners for tuning access.
10 | CNC tooling | 3/4 in ball-end mill | 1 | ea | Hardwood-capable ball-end cutter | buy | TBD | Primary arch undercut tool for bass/mid bars.
11 | CNC tooling | 1/2 in ball-end mill | 1 | ea | Hardwood-capable ball-end cutter | buy | TBD | Alternative or treble arch finish tool.
12 | CNC tooling | 1/4 in downcut spiral | 1 | ea | Hardwood-capable router bit | buy | TBD | Bar profile cleanup and fixture pockets.
13 | CNC tooling | 1/8 in upcut spiral | 1 | ea | Hardwood-capable router bit | buy | TBD | Small reliefs, pilot features, or templates.
14 | Finish | Sanding and finish consumables | 1 | set | 80-320 grit abrasives plus oil/shellac/lacquer TBD | buy | TBD | Finish must not load bar underside or node areas.
15 | Measurement | Tuning and data capture | 1 | set | Chromatic tuner, microphone, calipers, scale | buy/owned | TBD | Needed for validation.csv completion.

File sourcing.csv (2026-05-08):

item | stable_spec | supplier_candidates | current_price_status | lead_time_status | verification_needed | notes
African Padauk lumber | Clear straight-grain stock at least 34 in long and 7/8 in final thickness; quartersawn preferred | Local hardwood dealer; Woodcraft; Rockler; specialty tonewood supplier | not verified | not verified | Verify board width/defect-free yield before purchase | Buy enough extra for C3/A4/C6 pilot bars and tuning failures.
Alternative bar lumber | Hard maple or cherry at 7/8 in final thickness | Local hardwood dealer; Woodcraft; Rockler | not verified | not verified | Verify K constant before substituting | Use only for material study or education build, not direct swap without validation.
Resonator tube stock | PVC or aluminum tubes in selected bores from about 1.25-2.00 in or revised bore set | McMaster-Carr; local plumbing supplier; OnlineMetals | not verified | not verified | Verify ID/OD, wall thickness, cap availability, and cut length | Current workbook lengths use a bore proxy; update after selecting tube sizes.
Tube caps/stoppers | Adjustable or removable closed end matching tube ID | McMaster-Carr; plumbing supplier; 3D printed plugs | not verified | not verified | Confirm air seal and tuning adjustability | Prototype with removable caps before permanent end caps.
Frame hardwood | Hard maple or stable hardwood rail stock | Local hardwood dealer | not verified | not verified | Confirm straightness and final rail length | Frame geometry is still CAD-driven TBD.
Support cord | Low-stretch braided synthetic cord sized for 1/4 in support holes | Music hardware supplier; climbing accessory cord supplier | not verified | not verified | Confirm diameter and stretch | Must not buzz against bar holes.
Rubber supports | Silicone/rubber tubing or grommets sized to isolate bars | McMaster-Carr; marimba parts supplier | not verified | not verified | Confirm durometer and fit | Two supports per bar minimum.
CNC ball-end bit | 3/4 in carbide ball-end mill suitable for hardwood | Amana; Whiteside; Onsrud; local tooling supplier | not verified | not verified | Verify shank, flute length, machine collet, and feeds/speeds | Use actual bit geometry in CAM.
CNC downcut bit | 1/4 in carbide downcut spiral for clean top edges | Amana; Whiteside; Onsrud | not verified | not verified | Verify cut length and chip evacuation | Profile passes need tabs or fixture retention.
Finish | Thin oil/shellac/lacquer finish compatible with tuned bars | Wood finishing supplier | not verified | not verified | Test on offcuts for pitch shift | Heavy finishes can detune/damp bars.

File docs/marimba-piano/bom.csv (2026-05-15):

item_id | item | quantity | material_or_spec | status | source_status | notes
B001 | P0 key lever | 1 | hardwood or plywood | planned | available_or_shop_scrap | Simple lever is enough for P0.
B002 | P0 hammer arm | 1 | hardwood or aluminum flat bar | planned | available_or_shop_scrap | Leave room for adjustable strike angle.
B003 | three-face hammer head | 1 | printed carrier or small machined hub | planned | measurement_required | Manual indexing is acceptable for P0.
B004 | hammer face samples | 3_to_7 | rubber/yarn/felt/wood/plastic | planned | unverified_until_purchase | Use sacrificial samples before final carriers.
B005 | P0 tone bar | 1 | padauk/maple/aluminum/synthetic | planned | unverified_until_purchase | A4 or C5 coupon recommended.
B006 | bar support cord or posts | 1_set | braided cord/rubber posts/felt washers | planned | available_or_shop_scrap | Support at 22.4 percent and 77.6 percent of bar length.
B007 | aperture plate | 1 | plywood/acrylic/aluminum | planned | available_or_shop_scrap | Use replaceable inserts if possible.
B008 | gasket sheet | 1 | neoprene/silicone/felt | planned | unverified_until_purchase | Compression set must be measured.
B009 | P0 resonator tube | 1 | PVC/aluminum/cardboard test tube | planned | unverified_until_purchase | Use adjustable trim or telescoping sleeve.
B010 | mini platen clamp | 1 | toggle clamp or cam lever | planned | unverified_until_purchase | Must have adjustable hard stop.
B011 | resonator bed adjusters | 2_to_4 | threaded inserts/standoffs/springs | planned | unverified_until_purchase | Used to test float and slack take-up.
B012 | tuner/measurement setup | 1 | phone app/mic/audio interface | planned | available | Record pitch, sustain, and attack samples.
B013 | P1 key/action hardware | 13 | TBD | defer | measurement_required | Do not buy until P0 closes.
B014 | P1 tone-bar cassette hardware | 1_set | TBD | defer | measurement_required | Do not dimension until P0/P1 layout is chosen.

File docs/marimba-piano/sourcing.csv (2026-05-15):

source_id | item | candidate_source | source_status | next_check | notes
S001 | tonewood bar stock | local hardwood supplier or luthier offcut bin | needs_current_check | verify species/dimensions/moisture before purchase | Padauk and hard maple are good first candidates.
S002 | aluminum bar stock | local metal supplier or online metals vendor | needs_current_check | verify alloy/thickness/flatness before purchase | 6061 is a practical first coupon material.
S003 | synthetic bar stock | plastics supplier or instrument repair source | needs_current_check | identify exact material and dimensions | Do not assume Kelon-like behavior without material data.
S004 | rubber balls or mallet heads | sporting goods or percussion supplier | needs_current_check | measure diameter and hardness if possible | Cut sacrificial samples first.
S005 | yarn/felt/leather covering | craft or upholstery supplier | needs_current_check | test wear and adhesive | Could wrap interchangeable inserts instead of whole heads.
S006 | gasket sheet | industrial supply or hardware supplier | needs_current_check | check thickness and compression set | Neoprene and silicone are first candidates.
S007 | resonator tube stock | hardware store or metal supplier | needs_current_check | check inner diameter and wall consistency | PVC is fine for P0; aluminum may be used later.
S008 | toggle clamps/cam hardware | hardware or fixture supplier | needs_current_check | check clamp force and throw | Must not over-compress bars or gasket.

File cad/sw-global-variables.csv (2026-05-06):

global_name | unit | default_value | source | description
bar_note | text | C3 | family-spec.csv | Human-readable note name for the active configuration.
midi | unitless | 48 | family-spec.csv | MIDI note number.
target_frequency_hz | hz | 130.813 | family-spec.csv | Equal-temperament target frequency with A4 = 440 Hz.
bar_length_in | in | 32.251 | family-spec.csv | Finished bar length before final tuning adjustment.
bar_width_in | in | 2.000 | family-spec.csv | Finished bar width and current resonator bore proxy.
edge_thickness_in | in | 0.875 | workbook | Nominal bar thickness at the ends/edges.
center_thickness_in | in | 0.250 | family-spec.csv | Minimum thickness at center of underside arch.
arch_depth_in | in | 0.625 | family-spec.csv | Maximum underside relief depth from edge thickness.
arch_length_ratio | unitless | 0.600 | workbook notes | Underside arch spans about 60 percent of bar length.
node_1_in | in | 7.224 | family-spec.csv | Left support node measured from left end.
node_2_in | in | 25.027 | family-spec.csv | Right support node measured from left end.
cord_hole_diameter_in | in | 0.250 | workbook build specs | Initial node/support hole diameter.
resonator_length_in | in | 24.260 | family-spec.csv | First-pass quarter-wave tube length.
resonator_bore_in | in | 2.000 | family-spec.csv | Current bore/end-correction proxy; update after sourcing.
resonator_mount_clearance_in | in | 0.500 | assumption | Minimum clearance from tube to vibrating bar/frame.
tube_cap_allowance_in | in | 0.500 | assumption | Extra length/space for adjustable stopper or cap.
bar_spacing_in | in | 0.375 | assumption | Initial clear gap between adjacent bars; validate ergonomically.
natural_row_offset_in | in | 0.000 | assumption | Player-side natural row datum.
accidental_row_offset_in | in | 2.500 | assumption | Back-row offset for accidental bars; validate with mallets.
frame_rail_width_in | in | 1.500 | assumption | Starting rail width.
frame_rail_height_in | in | 1.500 | assumption | Starting rail height.
ball_end_bit_diameter_in | in | 0.750 | workbook CNC notes | Primary ball-end tool for arch surfacing.
stepover_in | in | 0.375 | workbook CNC notes | 50 percent stepover for 3/4 in ball-end bit.
stock_allowance_length_in | in | 0.750 | shop assumption | Rough stock length added before final tune/profile.
tab_allowance_in | in | 0.250 | shop assumption | Temporary CNC tab allowance where profile cutting needs retention.

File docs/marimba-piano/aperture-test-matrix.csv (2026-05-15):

aperture_id | geometry | relative_open_area | expected_effect | best_first_pairing | test_status | notes
A1 | round open throat | 0.85 | strong coupling and high projection | wood bars | planned | Start as the open control.
A2 | round medium throat | 0.65 | balanced coupling | synthetic bars | planned | Likely useful general cassette throat.
A3 | round narrow throat | 0.45 | reduced sustain and lower resonator drive | aluminum bars | planned | May tame metallic wash.
A4 | horizontal slot | 0.45 | directional coupling and possible attack focus | aluminum bars | planned | Compare against A3 at the same area.
A5 | round throat with removable baffle washer | 0.35_to_0.70 | field-adjustable coupling | all materials | planned | Useful if cassette-specific aperture plates are too many.
A6 | round throat with damping screen | 0.60 | reduced high-frequency energy | aluminum bars | defer | Treat as experimental until clean baseline data exists.
A7 | no gasket or loose seal control | TBD | leakage reference | all materials | planned | Use only as a comparison to prove the platen seal matters.

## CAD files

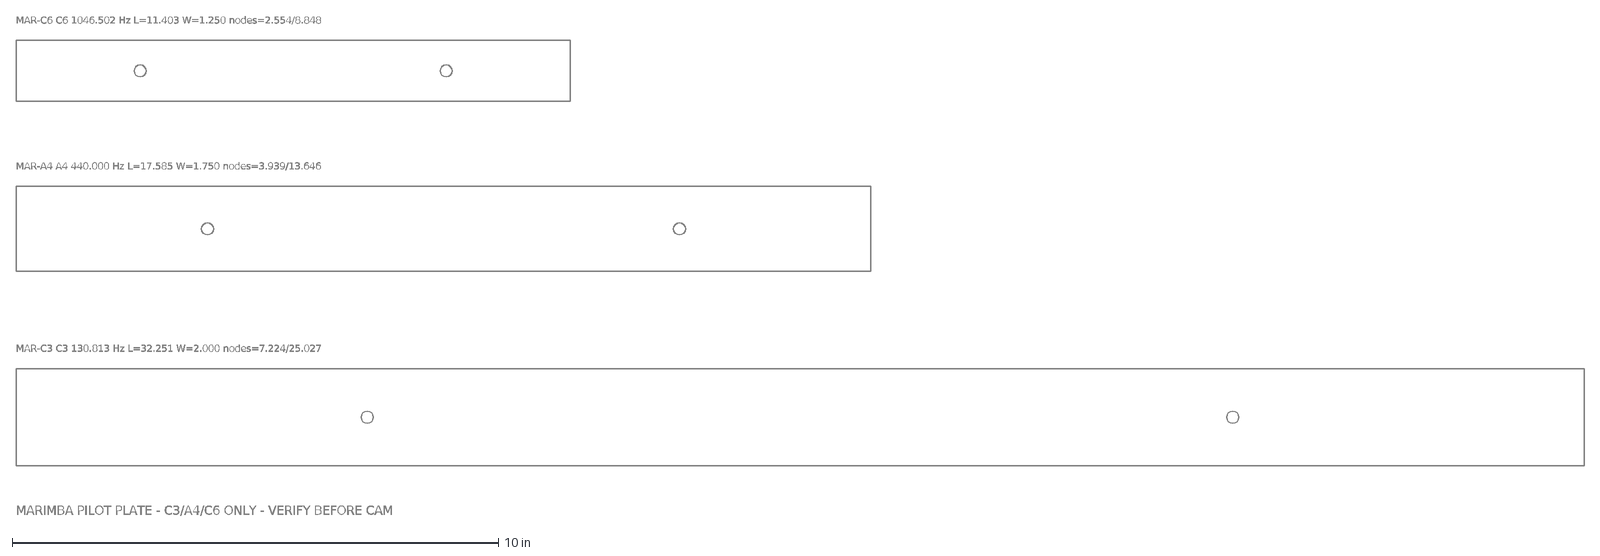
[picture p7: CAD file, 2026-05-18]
drawings/marimba-pilot-plate.dxf
MARIMBA PILOT PLATE - C3/A4/C6 ONLY - VERIFY BEFORE CAM
MAR-C3 C3 130.813 Hz L=32.251 W=2.000 nodes=7.224/25.027
MAR-A4 A4 440.000 Hz L=17.585 W=1.750 nodes=3.939/13.646
MAR-C6 C6 1046.502 Hz L=11.403 W=1.250 nodes=2.554/8.848

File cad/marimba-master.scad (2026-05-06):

// Marimba OpenSCAD starter.
// Build-critical dimensions live in family-spec.csv and CAD CSV files.
// This starter is for visual/spacing review, not final CAM.

$fn = 48;

function inch(x) = x * 25.4;

module bar(length_in, width_in, edge_thickness_in, center_thickness_in, arch_depth_in, node_1_in, node_2_in) {
    length = inch(length_in);
    width = inch(width_in);
    edge = inch(edge_thickness_in);
    center = inch(center_thickness_in);
    node1 = inch(node_1_in);
    node2 = inch(node_2_in);

    difference() {
        cube([length, width, edge], center=false);

        // Simplified centered underside relief. The real CAM path should use a
        // parabolic surface over about 60 percent of the bar length.
        translate([length * 0.20, -1, -0.1])
            cube([length * 0.60, width + 2, edge - center], center=false);

        translate([node1, width / 2, edge / 2])
            rotate([90, 0, 0])
                cylinder(h=width + 2, d=inch(0.25), center=true);

        translate([node2, width / 2, edge / 2])
            rotate([90, 0, 0])
                cylinder(h=width + 2, d=inch(0.25), center=true);
    }
}

module resonator(length_in, bore_in) {
    length = inch(length_in);
    bore = inch(bore_in);
    difference() {
        cylinder(h=length, d=bore + inch(0.125), center=false);
        translate([0, 0, -1])
            cylinder(h=length + 2, d=bore, center=false);
    }
}

module note_assembly(length_in, width_in, edge_thickness_in, center_thickness_in, arch_depth_in, node_1_in, node_2_in, resonator_length_in, resonator_bore_in) {
    bar(length_in, width_in, edge_thickness_in, center_thickness_in, arch_depth_in, node_1_in, node_2_in);
    translate([inch(length_in) / 2, inch(width_in) / 2, -inch(resonator_length_in) - inch(0.75)])
        resonator(resonator_length_in, resonator_bore_in);
}

// Representative configurations. Use cad/design-table-inputs.csv for the full
// SolidWorks configuration set.
translate([0, 0, 0])
    note_assembly(32.251, 2.000, 0.875, 0.250, 0.625, 7.224, 25.027, 24.260, 2.000);

translate([0, inch(4.0), 0])
    note_assembly(17.585, 1.750, 0.875, 0.523, 0.352, 3.939, 13.646, 6.265, 1.750);

translate([0, inch(7.5), 0])
    note_assembly(11.403, 1.250, 0.875, 0.719, 0.156, 2.554, 8.848, 2.212, 1.250);

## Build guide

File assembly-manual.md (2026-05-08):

# Marimba Assembly Manual

## Build Philosophy

Cut three pilot bars before committing the whole set: C3, A4, and C6. They bound the low arch-depth limit, the center of the scale, and the short/high-bar behavior. Use their measured pitch and resonator response to decide whether the workbook K constant, selected wood, and CNC arch path are ready for the full run.

## Preflight

- [ ] Confirm active range: C3-C6 chromatic, 37 bars.
- [ ] Confirm selected bar wood and moisture content.
- [ ] Confirm actual resonator tube bore and update `family-spec.csv` if it differs from the workbook proxy.
- [ ] Confirm CNC bed size, hold-down, bit length, and dust collection.
- [ ] Review `jig-decision.md` and build only the pilot jigs required for C3, A4, and C6.
- [ ] Print or open `drawings/arch-undercut-section.svg`, `drawings/resonator-layout.svg`, and `cnc/setup-sheet.md`.

## Jig Decision Gate

Use `jig-decision.md` as the shop stop/go sheet. Do not build the full 37-bar fixture, final frame, or fixed resonator stop system until the pilot rows in `validation.csv` have measured values for `flat_blank`, `post_arch`, `post_sand`, `resonator_coupled`, and `final_frame`.

## Bar Workflow

1. Break down rough Padauk stock into oversize blanks using `cut-list.csv`.
2. Joint one face and edge. Mark grain direction and top face.
3. Plane or sand each blank to `0.875 in` nominal edge thickness.
4. Label every blank with `member_id`, note, target Hz, and top face.
5. CNC profile each bar oversize or leave tabs for final cleanup.
6. Mark node positions from `family-spec.csv`.
7. Drill support/cord holes at the node line. Start with `0.250 in`, then adapt to the actual cord/rubber support system.
8. Cut the underside parabolic arch. Use a conservative Z-zero and leave a sanding/tuning allowance.
9. Deburr and sand without rounding node contact areas excessively.
10. Strike-test on soft supports at the node positions and record measured Hz in `validation.csv`.

## Tuning Direction

- To lower pitch: remove material from the center underside arch region.
- To raise pitch: shorten the bar or reduce mass near the ends; raising pitch after over-cutting is limited, so sneak up slowly.
- Keep both ends visually balanced. Asymmetric mass removal can pull modes sideways or create uneven sustain.
- Tune bars before final resonator matching.

## Resonator Workflow

1. Select tube material and bore.
2. Recalculate tube lengths if the selected bore differs from `resonator_bore_in`.
3. Cut tubes oversize per `cut-list.csv`.
4. Deburr both ends.
5. Add removable caps or adjustable stoppers.
6. Mount under the matching bar with the opening centered below the vibrating region.
7. Trim or adjust caps after the bar pitch is stable in the frame.
8. Record final resonator length, cap style, and response notes.

## Frame Workflow

1. Build a temporary straight or lightly tapered validation frame before the final furniture-grade frame.
2. Lay out rail supports from the node schedule, not from equal bar-end offsets.
3. Keep resonator access open so tubes can be removed and tuned.
4. Add cross members only after checking mallet clearance, tube clearance, and player reach.
5. Use removable fasteners until tuning and buzz checks are done.

## Final Checks

- [ ] All bars are labeled and match `family-spec.csv`.
- [ ] Node supports touch at node positions.
- [ ] No bar contacts the frame except through intended rubber/cord supports.
- [ ] No resonator tube touches a vibrating bar.
- [ ] Every measured pitch has a `validation.csv` row.
- [ ] Any bar outside +/- 10 cents after final tuning is flagged for rework.

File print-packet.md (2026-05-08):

# Marimba CNC Bar And Resonator Build Packet Print Packet

Generated: 2026-05-06
Packet folder: `/mnt/c/Users/Tony/Documents/GitHub/marimba`

## File Map

| File | Purpose |
| --- | --- |
| `design.md` | Project intent, catalog metadata, assumptions, and validation plan. |
| `bom.csv` | Starter bill of materials with part categories, quantities, drawing refs, and notes. |
| `sourcing.csv` | Supplier/search tracker with specs, price/date fields, lead time, substitutes, and risks. |
| `cut-list.csv` | Rough/final stock sizes, material, grain/orientation, operations, yield, and offcuts. |
| `drawing-brief.md` | Manufacturing drawing and technical product sketch brief. |
| `assembly-manual.md` | Shop-facing sequence, tools, fixtures, safety, tuning, finishing, and maintenance notes. |
| `validation.csv` | Target/measured values, tolerance, environment, result, and tuning/build action log. |
| `supplier-rfq.md` | Supplier email/request-for-quote starter. |
| `visual-bom-brief.md` | Art direction for an image-forward visual BOM. |
| `jig-decision.md` | Fixture decision record and pilot jig release gates. |
| `README.md` | Project artifact. |
| `family-spec.csv` | Project artifact. |
| `photo-shotlist.md` | Project artifact. |
| `risks.md` | Project artifact. |

## design.md

Project intent, catalog metadata, assumptions, and validation plan.

# Marimba Design Packet

## Project Intent

Build a 37-bar C3-C6 marimba packet from the existing workbook design table. The first build target is a CNC-friendly instrument with African Padauk bars, parabolic underside arch undercuts, drilled node supports, quarter-wave resonators, and a frame layout that can become a SolidWorks master sketch.

The useful boundary for this packet is "build-ready documentation, not finished CAD." Native SolidWorks files do not exist yet. The CAD folder defines the global-variable and design-table contract Tony can use to build the real model.

## Design Intake

| Field | Value |
| --- | --- |
| Instrument | Marimba |
| Instrument family | Free-free beam idiophone with tuned quarter-wave resonators |
| Active build range | C3-C6 chromatic, 37 bars |
| Source workbook | `marimba-design-table.xlsx`, sheet `Marimba`, range `A1:X106` |
| Primary material | African Padauk bars, workbook K constant `155502` |
| Bar thickness | `0.875 in` nominal edge thickness |
| Minimum center thickness | `0.250 in` after arch undercut |
| Construction pipeline | CNC surfaced blanks, 3D arch undercut, profile/tabs, node drilling, resonator cutting, frame assembly |
| Done-bar reference | `tongue-drum` README and wooden idiophone validation discipline |

The guided v4.2 intake artifacts are in `data/design-intake.json` and `data/design-input-row.csv`.

## Governing Model

### Bar Pitch

The marimba bars are treated as free-free beams. The first flexural mode uses:

```text
lambda_1 = 4.730
f_1 = (lambda_1^2 / (2*pi*L^2)) * sqrt(E*I/(rho*A))
```

The workbook uses the practical shop form:

```text
f ~= K * t / L^2
L ~= sqrt(K * t / f)
```

where:

- `f` is target frequency in Hz.
- `K` is the material-specific free-free bar constant.
- `t` is nominal bar thickness at the edge.
- `L` is bar length.

For the active packet:

```text
K = 155502
t = 0.875 in
```

The workbook material library derives this free-free K from the beam material properties and the `lambda_1 = 4.730` mode shape. Do not apply flute-bore K2 corrections here; those belong to Native American style flute bore correction work, not beam idiophones.

### Nodes And Supports

The suspension node locations are:

```text
node_1 = 0.224 * L
node_2 = 0.776 * L
```

Cord holes and rail pins reference these two locations. Holes must be drilled at the nodal line so the support does not damp the main mode.

### Arch Undercut

The workbook defines a linear MIDI-scaled arch-depth schedule:

```text
arch_depth = (edge_thickness - min_center_thickness) * min(1, (96 - midi)/48)
center_thickness = edge_thickness - arch_depth
```

This makes the low bars carry the deepest undercut and the high bars approach a shallow arch. The current minimum center thickness is `0.250 in`, so C3 reaches the minimum while C6 remains about `0.719 in` at center.

The arch should be cut as a centered parabolic underside relief over roughly 60 percent of the bar length. Final voicing still requires controlled sanding and tuner checks; the workbook is the first-pass schedule.

### Resonators

The resonator tubes are treated as quarter-wave closed pipes:

```text
L_res = 13552 / (4 * f) - 0.82 * bore
```

The sheet currently uses the bar-width column as the resonator bore/end-correction proxy. That is acceptable as a first-pass planning value, but the sourcing pass should decide real tube diameters and update `family-spec.csv` if the selected bore differs from the workbook proxy.

The distinction is important:

- Bar pitch is tuned by bar length, thickness, arch geometry, and material.
- Resonator length is tuned to reinforce the already-tuned bar frequency.
- A resonator mismatch changes sustain/loudness/color; it does not fix a wrong bar pitch.

## Bar Schedule

The full schedule is in `family-spec.csv`. Representative rows:

| Note | MIDI | Target Hz | Length in | Width in | Node 1 in | Node 2 in | Arch in | Center in | Resonator in |
| --- | ---: | ---: | ---: | ---: | ---: | ---: | ---: | ---: | ---: |
| C3 | 48 | 130.813 | 32.251 | 2.000 | 7.224 | 25.027 | 0.625 | 0.250 | 24.260 |
| C4 | 60 | 261.626 | 22.805 | 1.750 | 5.108 | 17.697 | 0.469 | 0.406 | 11.515 |
| A4 | 69 | 440.000 | 17.585 | 1.750 | 3.939 | 13.646 | 0.352 | 0.523 | 6.265 |
| C6 | 84 | 1046.502 | 11.403 | 1.250 | 2.554 | 8.848 | 0.156 | 0.719 | 2.212 |

## Resonator Schedule

`family-spec.csv` includes a first-pass tube length for every note. Treat these as cut-long values until a tube material, bore, cap style, and stopper/trim strategy are selected.

Recommended build behavior:

1. Cut resonators at least `0.5 in` long for C5 and above, and at least `1.0 in` long below C5.
2. Use adjustable caps or removable plugs for the first build.
3. Tune resonators after the bars are struck and measured in the frame.
4. Record final tube length and cents response in `validation.csv`.

## Hardware Alignment

The support rails follow the node path rather than a fixed straight rail. For each bar:

- Left support: `node_1_in`.
- Right support: `node_2_in`.
- Cord/support hole diameter: `0.250 in` starting point.
- Frame pin/rubber support must touch at the node, not at the bar end.
- Bar spacing and frame taper are `TBD` until mallet clearance and resonator tube diameters are chosen.

## SolidWorks MasterLayout Plan

The SolidWorks model should be driven from a master sketch and equations:

1. A `Master_Bar` part with configurations from `cad/design-table-inputs.csv`.
2. A `Master_Resonator` part with tube length, bore, cap allowance, and mounting hole variables.
3. A `Frame_MasterLayout` sketch defining bass and treble rail curves, bar spacing, resonator centerlines, and player-side datum.

Do not model hand-edited dimensions in SolidWorks. Every repeated note configuration should be driven by the variables listed in `cad/sw-global-variables.csv`.

## Open Assumptions

- Active packet uses C3-C6 instead of the workbook's full C2-F6 or portable C4-F6 variants.
- African Padauk is the workbook-selected material; actual board availability and moisture content are not verified.
- Resonator tube material and exact bore are `TBD`; current resonator lengths use the workbook width/end-correction proxy.
- Frame geometry, rail spacing, bar spacing, and transport strategy need CAD and ergonomic review.
- CNC feeds/speeds are starting notes only; final CAM must use the actual bit, router, hold-down, stock, and simulation.
- No measured bar data exists yet, so all frequencies are target predictions.

## Validation Plan

1. Surface three sacrificial bars first: C3, A4, and C6. These bound the length, arch, and treble-end assumptions.
2. Measure blank thickness, length, density estimate, and moisture content before cutting the arch.
3. Record flat-bar pitch, post-arch pitch, post-sanding pitch, and final assembled pitch.
4. Update `validation.csv` with measured Hz and cents error:

```text
cents = 1200 * log2(measured_hz / target_hz)
```

5. If the C3/A4/C6 pilot set misses by more than +/- 15 cents before final sanding, update the K constant or arch schedule before cutting the remaining 34 bars.
6. Tune resonators only after bars are within the target tuning window.

## Provenance

- Source workbook: `marimba-design-table.xlsx`, generated before this v4.2 packet run.
- Skill workflow: `instrument-maker-v4` v4.2.
- Reference family: `cantilever-idiophone` in `repo-relationships.yaml`; marimba notes call out bar tuning plus resonator coupling.

## bom.csv

Starter bill of materials with part categories, quantities, drawing refs, and notes.

| item | subassembly | part_name | qty | unit | material_or_spec | make_buy | status | notes |  |  |  |
| --- | --- | --- | --- | --- | --- | --- | --- | --- | --- | --- | --- |
| 1 | Bar set | C3-C6 tuned bars | 37 | ea | African Padauk 7/8 in nominal edge thickness | make | workbook-derived | Individual dimensions in family-spec.csv. |  |  |  |
| 2 | Resonators | C3-C6 resonator tubes | 37 | ea | PVC or aluminum tube; bore TBD by sourcing | buy | TBD | Lengths in family-spec.csv are first-pass quarter-wave values using workbook bore proxy. |  |  |  |
| 3 | Resonators | Tube caps or adjustable stoppers | 37 | ea | Matched to selected tube bore | buy | TBD | Use adjustable closure for first validation build. |  |  |  |
| 4 | Frame | Bass-side rail | 1 | ea | Hard maple or laminated hardwood | make | TBD | Final length and curve depend on CAD frame layout. |  |  |  |
| 5 | Frame | Treble-side rail | 1 | ea | Hard maple or laminated hardwood | make | TBD | Must follow support nodes or carry adjustable posts. |  |  |  |
| 6 | Frame | Cross members | 4 | ea | Hardwood or plywood fixture stock | make | TBD | Temporary shop frame acceptable for validation build. |  |  |  |
| 7 | Hardware | Support cord | 1 | roll | Low-stretch braided cord or synthetic marimba cord | buy | TBD | Size to match 1/4 in node holes and rubber isolators. |  |  |  |
| 8 | Hardware | Rubber support tubing or grommets | 74 | ea | Rubber or silicone isolation supports | buy | TBD | Two supports per bar minimum. |  |  |  |
| 9 | Hardware | Frame fasteners | 1 | set | Wood screws |  threaded inserts |  washers | buy | TBD | Prefer removable fasteners for tuning access. |  |
| 10 | CNC tooling | 3/4 in ball-end mill | 1 | ea | Hardwood-capable ball-end cutter | buy | TBD | Primary arch undercut tool for bass/mid bars. |  |  |  |
| 11 | CNC tooling | 1/2 in ball-end mill | 1 | ea | Hardwood-capable ball-end cutter | buy | TBD | Alternative or treble arch finish tool. |  |  |  |
| 12 | CNC tooling | 1/4 in downcut spiral | 1 | ea | Hardwood-capable router bit | buy | TBD | Bar profile cleanup and fixture pockets. |  |  |  |
| 13 | CNC tooling | 1/8 in upcut spiral | 1 | ea | Hardwood-capable router bit | buy | TBD | Small reliefs |  pilot features |  or templates. |  |
| 14 | Finish | Sanding and finish consumables | 1 | set | 80-320 grit abrasives plus oil/shellac/lacquer TBD | buy | TBD | Finish must not load bar underside or node areas. |  |  |  |
| 15 | Measurement | Tuning and data capture | 1 | set | Chromatic tuner |  microphone |  calipers |  scale | buy/owned | TBD | Needed for validation.csv completion. |

## sourcing.csv

Supplier/search tracker with specs, price/date fields, lead time, substitutes, and risks.

| item | stable_spec | supplier_candidates | current_price_status | lead_time_status | verification_needed | notes |  |  |  |
| --- | --- | --- | --- | --- | --- | --- | --- | --- | --- |
| African Padauk lumber | Clear straight-grain stock at least 34 in long and 7/8 in final thickness; quartersawn preferred | Local hardwood dealer; Woodcraft; Rockler; specialty tonewood supplier | not verified | not verified | Verify board width/defect-free yield before purchase | Buy enough extra for C3/A4/C6 pilot bars and tuning failures. |  |  |  |
| Alternative bar lumber | Hard maple or cherry at 7/8 in final thickness | Local hardwood dealer; Woodcraft; Rockler | not verified | not verified | Verify K constant before substituting | Use only for material study or education build |  not direct swap without validation. |  |  |
| Resonator tube stock | PVC or aluminum tubes in selected bores from about 1.25-2.00 in or revised bore set | McMaster-Carr; local plumbing supplier; OnlineMetals | not verified | not verified | Verify ID/OD |  wall thickness |  cap availability |  and cut length | Current workbook lengths use a bore proxy; update after selecting tube sizes. |
| Tube caps/stoppers | Adjustable or removable closed end matching tube ID | McMaster-Carr; plumbing supplier; 3D printed plugs | not verified | not verified | Confirm air seal and tuning adjustability | Prototype with removable caps before permanent end caps. |  |  |  |
| Frame hardwood | Hard maple or stable hardwood rail stock | Local hardwood dealer | not verified | not verified | Confirm straightness and final rail length | Frame geometry is still CAD-driven TBD. |  |  |  |
| Support cord | Low-stretch braided synthetic cord sized for 1/4 in support holes | Music hardware supplier; climbing accessory cord supplier | not verified | not verified | Confirm diameter and stretch | Must not buzz against bar holes. |  |  |  |
| Rubber supports | Silicone/rubber tubing or grommets sized to isolate bars | McMaster-Carr; marimba parts supplier | not verified | not verified | Confirm durometer and fit | Two supports per bar minimum. |  |  |  |
| CNC ball-end bit | 3/4 in carbide ball-end mill suitable for hardwood | Amana; Whiteside; Onsrud; local tooling supplier | not verified | not verified | Verify shank |  flute length |  machine collet |  and feeds/speeds | Use actual bit geometry in CAM. |
| CNC downcut bit | 1/4 in carbide downcut spiral for clean top edges | Amana; Whiteside; Onsrud | not verified | not verified | Verify cut length and chip evacuation | Profile passes need tabs or fixture retention. |  |  |  |
| Finish | Thin oil/shellac/lacquer finish compatible with tuned bars | Wood finishing supplier | not verified | not verified | Test on offcuts for pitch shift | Heavy finishes can detune/damp bars. |  |  |  |

## cut-list.csv

Rough/final stock sizes, material, grain/orientation, operations, yield, and offcuts.

| cut_id | subassembly | qty | material | rough_dimension_in | finished_dimension_or_reference | operation | notes |  |
| --- | --- | --- | --- | --- | --- | --- | --- | --- |
| CUT-BAR-BASS | Bars C3-B3 | 12 | African Padauk | 34.0 x 2.25 x 1.00 each max rough blank | See MAR-C3 through MAR-B3 in family-spec.csv | Surface/thickness/profile/arch/drill | Long bars are the stock-yield driver; cut long and tune down. |  |
| CUT-BAR-MID | Bars C4-B4 | 12 | African Padauk | 24.0 x 2.00 x 1.00 each max rough blank | See MAR-C4 through MAR-B4 in family-spec.csv | Surface/thickness/profile/arch/drill | Keep grain direction consistent across the octave. |  |
| CUT-BAR-TREBLE | Bars C5-B5 | 12 | African Padauk | 17.0 x 1.75 x 1.00 each max rough blank | See MAR-C5 through MAR-B5 in family-spec.csv | Surface/thickness/profile/arch/drill | Smaller arch depths need careful Z-zero discipline. |  |
| CUT-BAR-TOP | Bars C6 | 1 | African Padauk | 12.5 x 1.50 x 1.00 rough blank | See MAR-C6 in family-spec.csv | Surface/thickness/profile/arch/drill | High bar is short and sensitive to over-sanding. |  |
| CUT-RES-BASS | Resonators C3-B3 | 12 | PVC or aluminum tube | Cut 1.0 in oversize from family-spec.csv lengths | Final trim after bar tuning | Tube cut/deburr/cap/drill | Use selected tube bore |  not blindly the workbook bore proxy. |
| CUT-RES-MID | Resonators C4-B4 | 12 | PVC or aluminum tube | Cut 0.75 in oversize from family-spec.csv lengths | Final trim after bar tuning | Tube cut/deburr/cap/drill | Mark each tube with note and target Hz. |  |
| CUT-RES-TREBLE | Resonators C5-C6 | 13 | PVC or aluminum tube | Cut 0.5 in oversize from family-spec.csv lengths | Final trim after bar tuning | Tube cut/deburr/cap/drill | Very short tubes may need larger bore or box coupling review. |  |
| CUT-RAIL-BASS | Frame bass rail | 1 | Hard maple or laminated hardwood | TBD | Node-following rail curve from CAD | Rip/plane/CNC drill | Do not freeze until bar spacing and tube diameters are selected. |  |
| CUT-RAIL-TREBLE | Frame treble rail | 1 | Hard maple or laminated hardwood | TBD | Node-following rail curve from CAD | Rip/plane/CNC drill | Keep removable for tuning access. |  |
| CUT-CROSS | Frame cross members | 4 | Hardwood or plywood | TBD | Width set by resonator clearance | Cut/drill/assemble | Prototype frame can be sacrificial. |  |
| CUT-JIG | Bar underside arch fixture | 1 | MDF or plywood spoilboard | CNC bed sized | Datum fence and tabs per cnc/setup-sheet.md | CNC fixture | Use repeatable X datum and replaceable spoilboard. |  |

## drawing-brief.md

Manufacturing drawing and technical product sketch brief.

# Drawing Brief

## Drawing Set

The current packet requires four build-critical drawing classes:

1. Per-bar SVGs generated from `family-spec.csv`.
2. `arch-undercut-section.svg` showing underside relief, edge thickness, center thickness, and tool assumptions.
3. `resonator-layout.svg` showing first-pass tube lengths and note mapping.
4. `frame-overview.svg` showing the frame datum plan, rail concept, bar order, and resonator clearance assumptions.

## Drawing Standards

- Units: inches.
- Primary datum for each bar: left end and centerline.
- Support holes: show `0.224 * L` and `0.776 * L`.
- Bar dimensions: length, width, edge thickness, center thickness, arch depth.
- Resonator dimensions: tube bore, acoustic length, trim allowance, cap style.
- Tolerances:
  - Bar length rough cut: +0.125 in / -0.000 in before tuning.
  - Final length: tune-to-pitch, not dimension-only.
  - Thickness before arch: +/- 0.005 in.
  - Node hole placement: +/- 0.020 in first-pass, improve after pilot data.
- CNC notes: bit diameter, stepover, Z-zero surface, tabs, workholding, and release checks.

## Open Drawing Questions

- Final resonator tube bore and cap style.
- Final frame rail curve and cross-member spacing.
- Bar spacing and accidental/natural row layout.
- Whether the first build uses a temporary validation frame or final furniture frame.

## Source Files

- `family-spec.csv`
- `design.md`
- `marimba-design-table.xlsx`
- `cad/SolidWorks-MasterLayout-Plan.md`
- `cnc/setup-sheet.md`

## assembly-manual.md

Shop-facing sequence, tools, fixtures, safety, tuning, finishing, and maintenance notes.

# Marimba Assembly Manual

## Build Philosophy

Cut three pilot bars before committing the whole set: C3, A4, and C6. They bound the low arch-depth limit, the center of the scale, and the short/high-bar behavior. Use their measured pitch and resonator response to decide whether the workbook K constant, selected wood, and CNC arch path are ready for the full run.

## Preflight

- [ ] Confirm active range: C3-C6 chromatic, 37 bars.
- [ ] Confirm selected bar wood and moisture content.
- [ ] Confirm actual resonator tube bore and update `family-spec.csv` if it differs from the workbook proxy.
- [ ] Confirm CNC bed size, hold-down, bit length, and dust collection.
- [ ] Print or open `drawings/arch-undercut-section.svg`, `drawings/resonator-layout.svg`, and `cnc/setup-sheet.md`.

## Bar Workflow

1. Break down rough Padauk stock into oversize blanks using `cut-list.csv`.
2. Joint one face and edge. Mark grain direction and top face.
3. Plane or sand each blank to `0.875 in` nominal edge thickness.
4. Label every blank with `member_id`, note, target Hz, and top face.
5. CNC profile each bar oversize or leave tabs for final cleanup.
6. Mark node positions from `family-spec.csv`.
7. Drill support/cord holes at the node line. Start with `0.250 in`, then adapt to the actual cord/rubber support system.
8. Cut the underside parabolic arch. Use a conservative Z-zero and leave a sanding/tuning allowance.
9. Deburr and sand without rounding node contact areas excessively.
10. Strike-test on soft supports at the node positions and record measured Hz in `validation.csv`.

## Tuning Direction

- To lower pitch: remove material from the center underside arch region.
- To raise pitch: shorten the bar or reduce mass near the ends; raising pitch after over-cutting is limited, so sneak up slowly.
- Keep both ends visually balanced. Asymmetric mass removal can pull modes sideways or create uneven sustain.
- Tune bars before final resonator matching.

## Resonator Workflow

1. Select tube material and bore.
2. Recalculate tube lengths if the selected bore differs from `resonator_bore_in`.
3. Cut tubes oversize per `cut-list.csv`.
4. Deburr both ends.
5. Add removable caps or adjustable stoppers.
6. Mount under the matching bar with the opening centered below the vibrating region.
7. Trim or adjust caps after the bar pitch is stable in the frame.
8. Record final resonator length, cap style, and response notes.

## Frame Workflow

1. Build a temporary straight or lightly tapered validation frame before the final furniture-grade frame.
2. Lay out rail supports from the node schedule, not from equal bar-end offsets.
3. Keep resonator access open so tubes can be removed and tuned.
4. Add cross members only after checking mallet clearance, tube clearance, and player reach.
5. Use removable fasteners until tuning and buzz checks are done.

## Final Checks

- [ ] All bars are labeled and match `family-spec.csv`.
- [ ] Node supports touch at node positions.
- [ ] No bar contacts the frame except through intended rubber/cord supports.
- [ ] No resonator tube touches a vibrating bar.
- [ ] Every measured pitch has a `validation.csv` row.
- [ ] Any bar outside +/- 10 cents after final tuning is flagged for rework.

## validation.csv

Target/measured values, tolerance, environment, result, and tuning/build action log.

| member_id | target_note | target_hz | predicted_length_in | stage | measured_hz | cents_error | tuner | environment | notes |  |  |  |
| --- | --- | --- | --- | --- | --- | --- | --- | --- | --- | --- | --- | --- |
| MAR-C3 | C3 | 130.813 | 32.251 | prebuild |  |  |  |  | Pilot low bar; record flat blank |  post-arch |  post-sand |  final frame. |
| MAR-Csharp3 | C#3 | 138.591 | 31.333 | prebuild |  |  |  |  |  |  |  |  |
| MAR-D3 | D3 | 146.832 | 30.441 | prebuild |  |  |  |  |  |  |  |  |
| MAR-Dsharp3 | D#3 | 155.563 | 29.575 | prebuild |  |  |  |  |  |  |  |  |
| MAR-E3 | E3 | 164.814 | 28.733 | prebuild |  |  |  |  |  |  |  |  |
| MAR-F3 | F3 | 174.614 | 27.915 | prebuild |  |  |  |  |  |  |  |  |
| MAR-Fsharp3 | F#3 | 184.997 | 27.120 | prebuild |  |  |  |  |  |  |  |  |
| MAR-G3 | G3 | 195.998 | 26.348 | prebuild |  |  |  |  |  |  |  |  |
| MAR-Gsharp3 | G#3 | 207.652 | 25.598 | prebuild |  |  |  |  |  |  |  |  |
| MAR-A3 | A3 | 220.000 | 24.869 | prebuild |  |  |  |  |  |  |  |  |
| MAR-Asharp3 | A#3 | 233.082 | 24.161 | prebuild |  |  |  |  |  |  |  |  |
| MAR-B3 | B3 | 246.942 | 23.473 | prebuild |  |  |  |  |  |  |  |  |
| MAR-C4 | C4 | 261.626 | 22.805 | prebuild |  |  |  |  |  |  |  |  |
| MAR-Csharp4 | C#4 | 277.183 | 22.156 | prebuild |  |  |  |  |  |  |  |  |
| MAR-D4 | D4 | 293.665 | 21.525 | prebuild |  |  |  |  |  |  |  |  |
| MAR-Dsharp4 | D#4 | 311.127 | 20.912 | prebuild |  |  |  |  |  |  |  |  |
| MAR-E4 | E4 | 329.628 | 20.317 | prebuild |  |  |  |  |  |  |  |  |
| MAR-F4 | F4 | 349.228 | 19.739 | prebuild |  |  |  |  |  |  |  |  |
| MAR-Fsharp4 | F#4 | 369.994 | 19.177 | prebuild |  |  |  |  |  |  |  |  |
| MAR-G4 | G4 | 391.995 | 18.631 | prebuild |  |  |  |  |  |  |  |  |
| MAR-Gsharp4 | G#4 | 415.305 | 18.100 | prebuild |  |  |  |  |  |  |  |  |
| MAR-A4 | A4 | 440.000 | 17.585 | prebuild |  |  |  |  | Pilot reference bar; use to calibrate K and arch schedule. |  |  |  |
| MAR-Asharp4 | A#4 | 466.164 | 17.085 | prebuild |  |  |  |  |  |  |  |  |
| MAR-B4 | B4 | 493.883 | 16.598 | prebuild |  |  |  |  |  |  |  |  |
| MAR-C5 | C5 | 523.251 | 16.126 | prebuild |  |  |  |  |  |  |  |  |
| MAR-Csharp5 | C#5 | 554.365 | 15.667 | prebuild |  |  |  |  |  |  |  |  |
| MAR-D5 | D5 | 587.330 | 15.221 | prebuild |  |  |  |  |  |  |  |  |
| MAR-Dsharp5 | D#5 | 622.254 | 14.787 | prebuild |  |  |  |  |  |  |  |  |
| MAR-E5 | E5 | 659.255 | 14.366 | prebuild |  |  |  |  |  |  |  |  |
| MAR-F5 | F5 | 698.456 | 13.957 | prebuild |  |  |  |  |  |  |  |  |
| MAR-Fsharp5 | F#5 | 739.989 | 13.560 | prebuild |  |  |  |  |  |  |  |  |
| MAR-G5 | G5 | 783.991 | 13.174 | prebuild |  |  |  |  |  |  |  |  |
| MAR-Gsharp5 | G#5 | 830.609 | 12.799 | prebuild |  |  |  |  |  |  |  |  |
| MAR-A5 | A5 | 880.000 | 12.435 | prebuild |  |  |  |  |  |  |  |  |
| MAR-Asharp5 | A#5 | 932.328 | 12.081 | prebuild |  |  |  |  |  |  |  |  |
| MAR-B5 | B5 | 987.767 | 11.737 | prebuild |  |  |  |  |  |  |  |  |
| MAR-C6 | C6 | 1046.502 | 11.403 | prebuild |  |  |  |  | Pilot high bar; validate shallow arch and short resonator behavior. |  |  |  |

## supplier-rfq.md

Supplier email/request-for-quote starter.

# Supplier RFQ - Marimba C3-C6 Build

## Scope

Request quotes for one 37-bar C3-C6 marimba prototype build. Prices, stock, and lead times are intentionally not assumed in this repo; verify current facts before purchasing.

## Bar Lumber

Please quote clear straight-grain African Padauk suitable for tuned percussion bars.

Required:

- Final thickness after surfacing: `0.875 in`.
- Longest finished bar: `32.251 in`.
- Widest finished bar: `2.000 in`.
- Preferred rough allowance: at least `34 in x 2.25 in x 1.00 in` for the longest bass blanks.
- Quantity: enough for 37 bars plus at least 3 pilot/scrap bars.
- Grain: straight, stable, no checks through the finished bar area.
- Moisture content: provide measured or estimated value.

Alternates:

- Hard maple for education/prototype comparison.
- Cherry for easier machining comparison.

Do not substitute material directly into the build schedule without updating the K constant and validating pitch.

## Resonator Tubes

Please quote PVC or aluminum tube options for 37 quarter-wave resonators.

Required quote data:

- Material.
- Nominal size.
- Actual ID and OD.
- Wall thickness.
- Available lengths.
- Compatible caps, plugs, or stopper hardware.
- Cutting service availability.

The first-pass length range in this packet is about `2.2 in` to `24.3 in`, before oversize tuning allowance. Actual lengths must be recalculated if bore differs from the workbook proxy.

## Hardware

Please quote:

- Low-stretch support cord or equivalent.
- Rubber or silicone tubing/grommets for support isolation.
- Frame fasteners suitable for removable tuning access.
- Optional threaded inserts for rail/cross-member joints.

## CNC Tooling

Please quote:

- 3/4 in carbide ball-end mill, hardwood capable.
- 1/2 in carbide ball-end mill, hardwood capable.
- 1/4 in downcut spiral router bit.
- 1/8 in upcut spiral router bit.

Include shank diameter, cut length, recommended feed/speed range, and replacement availability.

## Response Format

Please return:

```text
item
supplier part number
material/spec
actual dimensions
quantity available
unit price
lead time
shipping estimate
notes/substitution risks
```

## visual-bom-brief.md

Art direction for an image-forward visual BOM.

# Visual BOM Brief

## Goal

Create a visual BOM plate that lets another maker understand the marimba build at a glance: bars, resonators, support hardware, frame rails, tooling, and measurement gear.

## Required Views

1. Hero view of the assembled C3-C6 marimba on a simple shop frame.
2. Exploded view showing bars above resonator tubes above frame rails.
3. Detail inset for one bar: node holes, underside arch, grain direction.
4. Detail inset for one resonator: tube, cap/stopper, mounting clearance.
5. Material swatches: Padauk bar wood, tube material, rubber supports, frame wood.

## BOM Rows To Show

| Item | Visual Needed | Source |
| --- | --- | --- |
| Tuned Padauk bars | Actual shop photo once cut; concept placeholder acceptable before build | `family-spec.csv` |
| Resonator tubes | Supplier image or shop photo | `sourcing.csv` |
| Support cord | Supplier image or shop photo | `bom.csv` |
| Rubber supports | Supplier image or shop photo | `bom.csv` |
| Frame rails | CAD render or shop photo | `cad/` |
| CNC bits | Supplier image or shop photo | `bom.csv` |
| Tuning tools | Shop photo | `validation.csv` workflow |

## Labeling Rules

- Label generated images as concept placeholders.
- Do not use generated images for exact dimensions.
- Every dimension callout must match `family-spec.csv` or be marked `TBD`.
- Keep supplier prices out of the visual until current quotes are verified.

## First Plate Layout

Top: title, date, range, and material.

Middle left: exploded assembly with numbered callouts.

Middle right: BOM table grouped by bars, resonators, frame, hardware, tooling.

Bottom: assumptions and missing purchase-verification items.

## README.md

Project artifact.

# Marimba - CNC Bar And Resonator Build Packet

> A workbook-derived 37-bar C3-C6 marimba packet for CNC-cut Padauk bars, 3D arch undercuts, tuned quarter-wave resonators, and a SolidWorks-ready master-layout handoff.

## What This Is

This repository is the Mode A v4.2 build packet for a marimba: tuned wooden free-free bars suspended at their nodes, with a matched resonator under each note. It turns the existing `marimba-design-table.xlsx` scaffold into a shop-facing documentation set:

1. `design.md` explains the physics model, build range, assumptions, and validation plan.
2. `family-spec.csv` is the 37-bar C3-C6 schedule extracted from the workbook formulas.
3. `bom.csv`, `sourcing.csv`, and `cut-list.csv` separate stable specifications from supplier facts that should be verified before buying.
4. `drawings/`, `cad/`, `cnc/`, `wolfram/`, and `site/` carry the technical handoff layers.

Part of the [tonykoop/instrument-maker](https://github.com/tonykoop/instrument-maker) catalog.

## Physics In One Minute

A marimba bar is a free-free beam. The first mode uses `lambda_1 = 4.730`, and the practical workbook model is:

```text
f ~= K * t / L^2
L ~= sqrt(K * t / f)
```

Length is the dominant pitch lever. Bar thickness and the underside arch tune the bar; width mostly affects feel, loudness, stiffness distribution, and available resonator bore. The cord/support points land at about `0.224 * L` and `0.776 * L`.

The resonator tubes are quarter-wave closed pipes:

```text
L_res ~= c / (4 * f) - 0.82 * bore
```

The resonator reinforces the bar's target frequency. It does not tune the bar itself.

## Build Range

The active packet is a 37-bar chromatic range from C3 to C6, using the workbook's African Padauk setting:

| Note | Frequency | Bar length | Width | Arch depth | Resonator |
| --- | ---: | ---: | ---: | ---: | ---: |
| C3 | 130.813 Hz | 32.251 in | 2.000 in | 0.625 in | 24.260 in |
| C4 | 261.626 Hz | 22.805 in | 1.750 in | 0.469 in | 11.515 in |
| A4 | 440.000 Hz | 17.585 in | 1.750 in | 0.352 in | 6.265 in |
| C6 | 1046.502 Hz | 11.403 in | 1.250 in | 0.156 in | 2.212 in |

The workbook also documents two expansion shapes: a full C2-F6 marimba and a portable C4-F6 instrument. Those are not cut lists yet; they are future configurations once the C3-C6 bar and resonator workflow is validated.

## Repository Structure

```text
marimba/
|-- README.md
|-- design.md
|-- marimba-design-table.xlsx
|-- family-spec.csv
|-- bom.csv
|-- sourcing.csv
|-- cut-list.csv
|-- validation.csv
|-- assembly-manual.md
|-- supplier-rfq.md
|-- visual-bom-brief.md
|-- drawing-brief.md
|-- risks.md
|-- photo-shotlist.md
|-- cad/
|-- cnc/
|-- data/
|-- drawings/
|-- images/
|-- site/
`-- wolfram/
```

## Status

| Area | Status |
| --- | --- |
| Workbook scaffold | done, source table in `marimba-design-table.xlsx` |
| Guided intake | done, see `data/design-intake.json` |
| C3-C6 bar schedule | done, see `family-spec.csv` |
| CNC operation plan | generated, pre-CAM only |
| SolidWorks handoff | prepared as CSV/Markdown contract, no native CAD yet |
| Wolfram source | prepared as `.wl`; notebook execution pending local Wolfram |
| Build photos | pending first shop build |
| Measured tuning data | pending prototype validation |

## License

[CC BY 4.0](LICENSE) - see `LICENSE` for details.

## family-spec.csv

Project artifact.

| member_id | target_note | midi | target_hz | predicted_length_in | predicted_width_in | predicted_thick_in | node_1_in | node_2_in | arch_depth_in | center_thickness_in | resonator_length_in | resonator_bore_in | material | k_constant | scale_label | notes |
| --- | --- | --- | --- | --- | --- | --- | --- | --- | --- | --- | --- | --- | --- | --- | --- | --- |
| MAR-C3 | C3 | 48 | 130.813 | 32.251 | 2.000 | 0.875 | 7.224 | 25.027 | 0.625 | 0.250 | 24.260 | 2.000 | African Padauk | 155502 | C3-C6 chromatic | Workbook-derived from Marimba sheet; resonator bore currently follows width/end-correction proxy. |
| MAR-Csharp3 | C#3 | 49 | 138.591 | 31.333 | 2.000 | 0.875 | 7.019 | 24.315 | 0.612 | 0.263 | 22.806 | 2.000 | African Padauk | 155502 | C3-C6 chromatic | Workbook-derived from Marimba sheet; resonator bore currently follows width/end-correction proxy. |
| MAR-D3 | D3 | 50 | 146.832 | 30.441 | 2.000 | 0.875 | 6.819 | 23.622 | 0.599 | 0.276 | 21.434 | 2.000 | African Padauk | 155502 | C3-C6 chromatic | Workbook-derived from Marimba sheet; resonator bore currently follows width/end-correction proxy. |
| MAR-Dsharp3 | D#3 | 51 | 155.563 | 29.575 | 2.000 | 0.875 | 6.625 | 22.950 | 0.586 | 0.289 | 20.139 | 2.000 | African Padauk | 155502 | C3-C6 chromatic | Workbook-derived from Marimba sheet; resonator bore currently follows width/end-correction proxy. |
| MAR-E3 | E3 | 52 | 164.814 | 28.733 | 2.000 | 0.875 | 6.436 | 22.297 | 0.573 | 0.302 | 18.917 | 2.000 | African Padauk | 155502 | C3-C6 chromatic | Workbook-derived from Marimba sheet; resonator bore currently follows width/end-correction proxy. |
| MAR-F3 | F3 | 53 | 174.614 | 27.915 | 2.000 | 0.875 | 6.253 | 21.662 | 0.560 | 0.315 | 17.763 | 2.000 | African Padauk | 155502 | C3-C6 chromatic | Workbook-derived from Marimba sheet; resonator bore currently follows width/end-correction proxy. |
| MAR-Fsharp3 | F#3 | 54 | 184.997 | 27.120 | 2.000 | 0.875 | 6.075 | 21.045 | 0.547 | 0.328 | 16.674 | 2.000 | African Padauk | 155502 | C3-C6 chromatic | Workbook-derived from Marimba sheet; resonator bore currently follows width/end-correction proxy. |
| MAR-G3 | G3 | 55 | 195.998 | 26.348 | 2.000 | 0.875 | 5.902 | 20.446 | 0.534 | 0.341 | 15.646 | 2.000 | African Padauk | 155502 | C3-C6 chromatic | Workbook-derived from Marimba sheet; resonator bore currently follows width/end-correction proxy. |
| MAR-Gsharp3 | G#3 | 56 | 207.652 | 25.598 | 2.000 | 0.875 | 5.734 | 19.864 | 0.521 | 0.354 | 14.676 | 2.000 | African Padauk | 155502 | C3-C6 chromatic | Workbook-derived from Marimba sheet; resonator bore currently follows width/end-correction proxy. |
| MAR-A3 | A3 | 57 | 220.000 | 24.869 | 2.000 | 0.875 | 5.571 | 19.298 | 0.508 | 0.367 | 13.760 | 2.000 | African Padauk | 155502 | C3-C6 chromatic | Workbook-derived from Marimba sheet; resonator bore currently follows width/end-correction proxy. |
| MAR-Asharp3 | A#3 | 58 | 233.082 | 24.161 | 2.000 | 0.875 | 5.412 | 18.749 | 0.495 | 0.380 | 12.896 | 2.000 | African Padauk | 155502 | C3-C6 chromatic | Workbook-derived from Marimba sheet; resonator bore currently follows width/end-correction proxy. |
| MAR-B3 | B3 | 59 | 246.942 | 23.473 | 2.000 | 0.875 | 5.258 | 18.215 | 0.482 | 0.393 | 12.080 | 2.000 | African Padauk | 155502 | C3-C6 chromatic | Workbook-derived from Marimba sheet; resonator bore currently follows width/end-correction proxy. |
| MAR-C4 | C4 | 60 | 261.626 | 22.805 | 1.750 | 0.875 | 5.108 | 17.697 | 0.469 | 0.406 | 11.515 | 1.750 | African Padauk | 155502 | C3-C6 chromatic | Workbook-derived from Marimba sheet; resonator bore currently follows width/end-correction proxy. |
| MAR-Csharp4 | C#4 | 61 | 277.183 | 22.156 | 1.750 | 0.875 | 4.963 | 17.193 | 0.456 | 0.419 | 10.788 | 1.750 | African Padauk | 155502 | C3-C6 chromatic | Workbook-derived from Marimba sheet; resonator bore currently follows width/end-correction proxy. |
| MAR-D4 | D4 | 62 | 293.665 | 21.525 | 1.750 | 0.875 | 4.822 | 16.704 | 0.443 | 0.432 | 10.102 | 1.750 | African Padauk | 155502 | C3-C6 chromatic | Workbook-derived from Marimba sheet; resonator bore currently follows width/end-correction proxy. |
| MAR-Dsharp4 | D#4 | 63 | 311.127 | 20.912 | 1.750 | 0.875 | 4.684 | 16.228 | 0.430 | 0.445 | 9.454 | 1.750 | African Padauk | 155502 | C3-C6 chromatic | Workbook-derived from Marimba sheet; resonator bore currently follows width/end-correction proxy. |
| MAR-E4 | E4 | 64 | 329.628 | 20.317 | 1.750 | 0.875 | 4.551 | 15.766 | 0.417 | 0.458 | 8.843 | 1.750 | African Padauk | 155502 | C3-C6 chromatic | Workbook-derived from Marimba sheet; resonator bore currently follows width/end-correction proxy. |
| MAR-F4 | F4 | 65 | 349.228 | 19.739 | 1.750 | 0.875 | 4.421 | 15.317 | 0.404 | 0.471 | 8.266 | 1.750 | African Padauk | 155502 | C3-C6 chromatic | Workbook-derived from Marimba sheet; resonator bore currently follows width/end-correction proxy. |
| MAR-Fsharp4 | F#4 | 66 | 369.994 | 19.177 | 1.750 | 0.875 | 4.296 | 14.881 | 0.391 | 0.484 | 7.722 | 1.750 | African Padauk | 155502 | C3-C6 chromatic | Workbook-derived from Marimba sheet; resonator bore currently follows width/end-correction proxy. |
| MAR-G4 | G4 | 67 | 391.995 | 18.631 | 1.750 | 0.875 | 4.173 | 14.458 | 0.378 | 0.497 | 7.208 | 1.750 | African Padauk | 155502 | C3-C6 chromatic | Workbook-derived from Marimba sheet; resonator bore currently follows width/end-correction proxy. |
| MAR-Gsharp4 | G#4 | 68 | 415.305 | 18.100 | 1.750 | 0.875 | 4.054 | 14.046 | 0.365 | 0.510 | 6.723 | 1.750 | African Padauk | 155502 | C3-C6 chromatic | Workbook-derived from Marimba sheet; resonator bore currently follows width/end-correction proxy. |
| MAR-A4 | A4 | 69 | 440.000 | 17.585 | 1.750 | 0.875 | 3.939 | 13.646 | 0.352 | 0.523 | 6.265 | 1.750 | African Padauk | 155502 | C3-C6 chromatic | Workbook-derived from Marimba sheet; resonator bore currently follows width/end-correction proxy. |
| MAR-Asharp4 | A#4 | 70 | 466.164 | 17.085 | 1.750 | 0.875 | 3.827 | 13.258 | 0.339 | 0.536 | 5.833 | 1.750 | African Padauk | 155502 | C3-C6 chromatic | Workbook-derived from Marimba sheet; resonator bore currently follows width/end-correction proxy. |
| MAR-B4 | B4 | 71 | 493.883 | 16.598 | 1.750 | 0.875 | 3.718 | 12.880 | 0.326 | 0.549 | 5.425 | 1.750 | African Padauk | 155502 | C3-C6 chromatic | Workbook-derived from Marimba sheet; resonator bore currently follows width/end-correction proxy. |
| MAR-C5 | C5 | 72 | 523.251 | 16.126 | 1.500 | 0.875 | 3.612 | 12.513 | 0.312 | 0.562 | 5.245 | 1.500 | African Padauk | 155502 | C3-C6 chromatic | Workbook-derived from Marimba sheet; resonator bore currently follows width/end-correction proxy. |
| MAR-Csharp5 | C#5 | 73 | 554.365 | 15.667 | 1.500 | 0.875 | 3.509 | 12.157 | 0.299 | 0.576 | 4.881 | 1.500 | African Padauk | 155502 | C3-C6 chromatic | Workbook-derived from Marimba sheet; resonator bore currently follows width/end-correction proxy. |
| MAR-D5 | D5 | 74 | 587.330 | 15.221 | 1.500 | 0.875 | 3.409 | 11.811 | 0.286 | 0.589 | 4.538 | 1.500 | African Padauk | 155502 | C3-C6 chromatic | Workbook-derived from Marimba sheet; resonator bore currently follows width/end-correction proxy. |
| MAR-Dsharp5 | D#5 | 75 | 622.254 | 14.787 | 1.500 | 0.875 | 3.312 | 11.475 | 0.273 | 0.602 | 4.215 | 1.500 | African Padauk | 155502 | C3-C6 chromatic | Workbook-derived from Marimba sheet; resonator bore currently follows width/end-correction proxy. |
| MAR-E5 | E5 | 76 | 659.255 | 14.366 | 1.500 | 0.875 | 3.218 | 11.148 | 0.260 | 0.615 | 3.909 | 1.500 | African Padauk | 155502 | C3-C6 chromatic | Workbook-derived from Marimba sheet; resonator bore currently follows width/end-correction proxy. |
| MAR-F5 | F5 | 77 | 698.456 | 13.957 | 1.500 | 0.875 | 3.126 | 10.831 | 0.247 | 0.628 | 3.621 | 1.500 | African Padauk | 155502 | C3-C6 chromatic | Workbook-derived from Marimba sheet; resonator bore currently follows width/end-correction proxy. |
| MAR-Fsharp5 | F#5 | 78 | 739.989 | 13.560 | 1.500 | 0.875 | 3.037 | 10.523 | 0.234 | 0.641 | 3.348 | 1.500 | African Padauk | 155502 | C3-C6 chromatic | Workbook-derived from Marimba sheet; resonator bore currently follows width/end-correction proxy. |
| MAR-G5 | G5 | 79 | 783.991 | 13.174 | 1.500 | 0.875 | 2.951 | 10.223 | 0.221 | 0.654 | 3.091 | 1.500 | African Padauk | 155502 | C3-C6 chromatic | Workbook-derived from Marimba sheet; resonator bore currently follows width/end-correction proxy. |
| MAR-Gsharp5 | G#5 | 80 | 830.609 | 12.799 | 1.500 | 0.875 | 2.867 | 9.932 | 0.208 | 0.667 | 2.849 | 1.500 | African Padauk | 155502 | C3-C6 chromatic | Workbook-derived from Marimba sheet; resonator bore currently follows width/end-correction proxy. |
| MAR-A5 | A5 | 81 | 880.000 | 12.435 | 1.500 | 0.875 | 2.785 | 9.649 | 0.195 | 0.680 | 2.620 | 1.500 | African Padauk | 155502 | C3-C6 chromatic | Workbook-derived from Marimba sheet; resonator bore currently follows width/end-correction proxy. |
| MAR-Asharp5 | A#5 | 82 | 932.328 | 12.081 | 1.500 | 0.875 | 2.706 | 9.375 | 0.182 | 0.693 | 2.404 | 1.500 | African Padauk | 155502 | C3-C6 chromatic | Workbook-derived from Marimba sheet; resonator bore currently follows width/end-correction proxy. |
| MAR-B5 | B5 | 83 | 987.767 | 11.737 | 1.500 | 0.875 | 2.629 | 9.108 | 0.169 | 0.706 | 2.200 | 1.500 | African Padauk | 155502 | C3-C6 chromatic | Workbook-derived from Marimba sheet; resonator bore currently follows width/end-correction proxy. |
| MAR-C6 | C6 | 84 | 1046.502 | 11.403 | 1.250 | 0.875 | 2.554 | 8.848 | 0.156 | 0.719 | 2.212 | 1.250 | African Padauk | 155502 | C3-C6 chromatic | Workbook-derived from Marimba sheet; resonator bore currently follows width/end-correction proxy. |

## photo-shotlist.md

Project artifact.

# Photo Shotlist

This shotlist follows the repo-level photo pipeline expectations from `instrument-maker/docs/photo-pipeline.md`: capture real process images first, use generated or supplier images only as labeled placeholders, and keep build-log image names stable enough for `site/index.html`.

## Intake And Materials

- `images/01-workbook-table.png`: screenshot of `marimba-design-table.xlsx` showing the Marimba sheet.
- `images/02-padauk-stock.jpg`: rough Padauk boards with ruler and grain direction.
- `images/03-resonator-tube-options.jpg`: tube material and cap options.
- `images/04-cnc-tooling.jpg`: ball-end mills and profile bits.

## Bar Fabrication

- `images/10-blank-layout.jpg`: labeled rough blanks before cutting.
- `images/11-thickness-check.jpg`: calipers on surfaced blank.
- `images/12-node-marking.jpg`: node positions marked on one bass and one treble bar.
- `images/13-cnc-arch-setup.jpg`: bar blank held for underside arch.
- `images/14-arch-detail.jpg`: finished underside arch with straightedge.
- `images/15-support-hole-detail.jpg`: clean support hole at node.

## Resonators And Frame

- `images/20-resonator-cutting.jpg`: tube cutting/deburring setup.
- `images/21-resonator-cap-detail.jpg`: adjustable cap or stopper.
- `images/22-frame-rail-layout.jpg`: rail layout with node/support marks.
- `images/23-dry-fit-overview.jpg`: bars, rails, and resonators dry-fit.

## Validation

- `images/30-pilot-c3-tuning.jpg`: C3 supported at nodes and measured.
- `images/31-pilot-a4-tuning.jpg`: A4 tuning reference.
- `images/32-pilot-c6-tuning.jpg`: C6 treble validation.
- `images/33-validation-log.jpg`: tuner, microphone, and `validation.csv` workflow.

## Final Documentation

- `images/40-finished-front.jpg`: full instrument front view.
- `images/41-finished-player-view.jpg`: player reach/ergonomics view.
- `images/42-resonator-underneath.jpg`: underside resonator alignment.
- `images/43-detail-beauty.jpg`: finish/detail close-up.

## risks.md

Project artifact.

# Marimba Risk Register

## Acoustic Risks

### Bar pitch misses workbook prediction

- Risk: The selected Padauk stock has a different effective stiffness/density than the workbook K constant.
- Impact: All bars may cut sharp or flat by a consistent amount.
- Test: Cut and measure C3, A4, and C6 pilot bars before the full run.
- Pass criterion: Post-arch bars can be brought within +/- 10 cents by normal sanding/tuning allowance.
- Mitigation: Update K constant or arch schedule before cutting the remaining bars.

### Resonator bore proxy is wrong

- Risk: The workbook currently uses bar width as the resonator bore/end-correction proxy.
- Impact: Tube lengths may be wrong after real tube diameters are selected.
- Test: Select actual tube ID, recalculate C3/A4/C6 resonator lengths, and compare response.
- Pass criterion: Resonator reinforcement peaks near target pitch without strong buzz or deadening.
- Mitigation: Update `family-spec.csv` and regenerate resonator drawings before cutting all tubes.

## Structural Risks

### Arch cut-through or weak low bars

- Risk: C3 reaches the `0.250 in` minimum center thickness.
- Impact: Bass bars may crack, warp, or lose sustain.
- Test: Measure remaining center thickness after CNC and after final sanding.
- Pass criterion: No pilot bar falls below `0.250 in`; no visible checking under normal strike force.
- Mitigation: Increase minimum center thickness or choose denser/stiffer stock.

### Support holes weaken bars

- Risk: 1/4 in holes near nodes may split if drilled too close to edges or with poor backing.
- Impact: Cracks, buzzes, or support failure.
- Test: Drill sample holes in offcuts and pilot bars with the intended bit and backing board.
- Pass criterion: Clean holes with no breakout or splitting.
- Mitigation: Reduce hole diameter, use cord grooves, or add rubber support posts instead.

## Ergonomic Risks

### Frame too wide or awkward for reach

- Risk: C3-C6 chromatic layout may become too wide/deep once resonators and accidental row are placed.
- Impact: Poor playing ergonomics or impossible transport.
- Test: Tape full-size bar positions on a bench and test mallet reach before building the final frame.
- Pass criterion: Natural and accidental rows are reachable without shoulder strain for intended player.
- Mitigation: Use a compact portable range, split frame, or revised bar spacing.

## Supply Risks

### Padauk availability and quality

- Risk: Clear long Padauk stock may be expensive, unstable, or unavailable.
- Impact: Build delays or inconsistent tone.
- Test: Request current quotes and inspect board quality/moisture before purchase.
- Pass criterion: Enough straight stock for 37 bars plus pilot failures.
- Mitigation: Use hard maple/cherry for an education prototype and update material constants.

### Tube/cap system mismatch

- Risk: Selected tube caps may leak, rattle, or be hard to tune.
- Impact: Weak or noisy resonators.
- Test: Build three tube prototypes with removable caps.
- Pass criterion: Tubes hold adjustment and do not buzz under playing vibration.
- Mitigation: Use adjustable stoppers, gasketed plugs, or alternate tube material.

## Fit And Finish Risks

### Finish shifts pitch or damps sustain

- Risk: A heavy finish adds mass and damping to tuned bars.
- Impact: Bars go flat or lose sustain after finishing.
- Test: Finish an offcut and one sacrificial tuned test bar; measure before/after Hz and decay.
- Pass criterion: Pitch shift is predictable and within final tuning allowance.
- Mitigation: Use thin finish, tune after finish, or mask underside tuning zones until final pass.

### Frame buzzes after assembly

- Risk: Bars, tubes, caps, or fasteners touch unintentionally.
- Impact: Audible buzzes and unreliable validation data.
- Test: Strike every bar at soft, medium, and loud dynamics while muting adjacent parts.
- Pass criterion: No persistent buzz in the assembled frame.
- Mitigation: Add clearance, isolate hardware, and use thread-locking or removable dampers where appropriate.

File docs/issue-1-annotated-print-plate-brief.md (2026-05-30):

# Issue #1 Annotated Print Plate Brief

Status: honest V5 packet surface, pending Photoshop MCP and measurement.

Issue #1 asks for a Photoshop-MCP annotated print-plate test. This lane does
not have Photoshop MCP, CAD measurement tools, physical measurements, or a
reviewed plate export. It therefore scaffolds the plate contract and register
rows only. No CAD geometry, DXF coordinates, tuning frequencies, or measured
dimensions were created in this lane.

## Intended Plate

Planned artifact:

- `print-packet/assembly-plate.pdf`

Current state:

- not generated;
- not Photoshop-reviewed;
- not fabrication authority;
- not evidence of measured tuning or CAM readiness.

The plate should eventually be a print-facing assembly callout sheet for the
existing C3/A4/C6 pilot marimba subset. It should cite existing packet assets
instead of inventing new measurements.

## Required Callout Rows

| callout_id | subject | source artifact | authority | required evidence before promotion |
| --- | --- | --- | --- | --- |
| PP-C3-001 | C3 pilot bar outline and node locations | `drawings/marimba-pilot-plate.dxf`; `cad/design-table-inputs.csv` | pending_measurement | Photoshop MCP session log plus print-check/air-cut review. |
| PP-A4-001 | A4 pilot bar outline and node locations | `drawings/marimba-pilot-plate.dxf`; `cad/design-table-inputs.csv` | pending_measurement | Photoshop MCP session log plus print-check/air-cut review. |
| PP-C6-001 | C6 pilot bar outline and node locations | `drawings/marimba-pilot-plate.dxf`; `cad/design-table-inputs.csv` | pending_measurement | Photoshop MCP session log plus print-check/air-cut review. |
| PP-DATUM-001 | Plate datum, scale, and unit note | `docs/cad-dxf-authority-review.md` | pending_measurement | Human review that the exported page preserves inch units and scale. |
| PP-WARN-001 | Authority warning block | this file; `docs/v5-authority-register.csv` | concept_only | Warning remains visible on any exported proof. |

## Plate Text Requirements

Any future annotated print plate must include these statements:

- "Concept/prototype review only; not CAM-ready."
- "Pilot subset only: C3/A4/C6."
- "Dimensions trace to existing register artifacts; no measured tuning data is
  claimed by this plate."
- "Authority remains `pending_measurement` until validation.csv contains real
  pilot measurements and the print proof is reviewed."

## Visual Direction

Use the existing pilot layout as a background only after a real Photoshop MCP
session imports the source. The plate should show:

- one callout cluster per pilot bar;
- datum/scale note near the title block;
- node callouts that cite the design-table source rather than retyping
  unverified coordinates;
- a visible pending-authority warning block;
- a provenance footer with the Photoshop MCP session id and export timestamp.

## Register Links

- `visual-output-register.csv` row `PP-001` records the future plate artifact.
- `docs/v5-authority-register.csv` rows `PP-001` and `PP-BRIEF-001` record
  the issue #1 authority boundary.
- `cad/mcp-session-log.md` records the required future Photoshop MCP row.

## Retrieval And Provenance

- qmd Step 0 search: `qmd search "marimba" -c instrument-builds` returned the
  May 6 marimba v4.2 handoff plus marimba family-aware design references.
- qmd Step 0 query: `qmd query "marimba tuning packet"` crashed in the local
  node-llama-cpp path under timeout, so it was not used as authority.
- Existing repo artifacts were treated as the only packet evidence for this
  lane.
- No Photoshop MCP, Illustrator MCP, CAD MCP, physical measurement, tuner, or
  image inspection session was available.

## Promotion Gates

The print plate can move from `concept_only` / `pending_measurement` only
after all of the following are true:

1. A real Photoshop MCP session creates or reviews the plate and logs a
   session id in `cad/mcp-session-log.md`.
2. The plate source is tied to existing registered artifacts, not hand-entered
   dimensions.
3. A print-check or air-cut review verifies scale, units, and legibility.
4. `validation.csv` contains real pilot measurements if the plate makes any
   tuning or measured-performance claim.
5. The exported plate is registered with its final path and checksum or
   equivalent provenance note.

Until then, this is a V5 packet surface scaffold, not a fabricated plate.

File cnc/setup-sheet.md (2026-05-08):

# CNC / Manufacturing Setup Sheet

- Packet: `/mnt/c/Users/Tony/Documents/GitHub/marimba`
- Family: `beam-idiophone`
- Generated: 2026-05-06
- Machine note: Maker Nexus/home shop; verify exact machine, spindle, collet, bed size, and hold-down before CAM.

## Assumptions

- This is a pre-CAM operation graph, not verified G-code.
- The active build range is C3-C6, 37 bars.
- Source dimensions come from `family-spec.csv` and `marimba-design-table.xlsx`.
- The CNC plan assumes African Padauk blanks surfaced to `0.875 in`.
- Resonator tube bore is still a sourcing variable; update tube lengths after selecting actual ID.
- Fixture choices are controlled by `jig-decision.md`; do not promote pilot jigs to full-set CAM until C3/A4/C6 pass.

## Pilot Gate

Cut C3, A4, and C6 before cutting the full set.

Release to full production only if:

- C3 center thickness remains at least `0.250 in`.
- A4 tunes within normal sanding allowance.
- C6 shallow arch does not become overly stiff or dead.
- Resonator prototypes reinforce without buzz.
- The measured K trend is consistent enough to continue.

## Operation Graph

### OP-010 - Review design package and pilot gate

- Machine: Bench
- Tool: `README.md`, `design.md`, calipers, tuner
- Workholding: Flat bench, drawing packet
- Datum: Top face A, left end B, bar centerline C
- Inputs: `design.md`, `family-spec.csv`, `drawings/arch-undercut-section.svg`, `validation.csv`
- Outputs: pilot-build checklist
- Checks:
  - C3/A4/C6 pilot bars identified.
  - `jig-decision.md` reviewed and pilot-only fixture scope confirmed.
  - Actual wood species and tube bore confirmed.
  - Full-set cutting is held until pilot data is reviewed.

### OP-205 - Build pilot jig set

- Machine: Bench and CNC router
- Tool: MDF/plywood fixture stock, clamps, tape, centerline pins, backer board, V-block stock
- Workholding: Planer carrier, two-sided spoilboard, soft arch cradle, node-drilling backer, tube V-block
- Datum: Top face A, left end B, bar centerline C
- Inputs: `jig-decision.md`, `family-spec.csv`, `drawings/arch-undercut-section.svg`
- Outputs: Pilot jig set for C3, A4, and C6
- Checks:
  - A/B/C datums transfer through profile, flip, arch, drill, and tube-cut operations.
  - Clamp/tape zones avoid node holes and arch region.
  - C3/A4/C6 air cuts clear all hold-downs.
  - Full 37-bar nest remains blocked until pilot validation rows are measured.

### OP-110 - Surface and thickness bar blanks

- Machine: Jointer, planer, drum sander
- Tool: Jointer knives, planer, drum sander, calipers
- Workholding: Flat carrier board, push blocks
- Datum: Top face A and grain arrow
- Inputs: `cut-list.csv`, `family-spec.csv`
- Outputs: 37 surfaced oversize blanks
- Checks:
  - Thickness `0.875 in +/- 0.005 in`.
  - Grain direction logged.
  - Defects outside finished bar area.

### OP-120 - Label blanks and mark nodes

- Machine: Bench
- Tool: Marking knife, square, center punch, calipers
- Workholding: Flat bench with stop block
- Datum: Left end B and centerline C
- Inputs: `family-spec.csv`, generated bar drawings
- Outputs: Labeled blanks with note, target Hz, nodes
- Checks:
  - `node_1_in` and `node_2_in` match `family-spec.csv`.
  - Top face remains marked through the flip operation.

### OP-210 - Prepare CNC fixture and datum verification

- Machine: CNC router
- Tool: Spoilboard surfacing bit, edge finder/probe, clamps/tape
- Workholding: Replaceable spoilboard, datum fence, optional vacuum plus clamps
- Datum: X0 at left end B, Y0 at centerline C, Z0 at top face A
- Inputs: `cnc/setup-sheet.md`, `drawings/arch-undercut-section.svg`
- Outputs: Verified fixture and air-cut report
- Checks:
  - Spoilboard surfaced.
  - Clamps clear every toolpath.
  - Sample air-cut passes.

### OP-220 - Rough profile bars with tabs

- Machine: CNC router
- Tool: 1/4 in downcut spiral; optional 1/8 in upcut for small reliefs
- Workholding: Spoilboard tape/clamps, tabs at non-vibrating ends
- Datum: Top face A, left end B, centerline C
- Inputs: `family-spec.csv`, `cad/design-table-inputs.csv`
- Outputs: Profiled bar blanks with tabs
- Checks:
  - Tabs avoid node holes and arch region.
  - Final length retains tuning allowance.
  - Note label survives operation.

### OP-230 - 3D arch underside relief

- Machine: CNC router
- Tool: 3/4 in ball-end mill; 1/2 in ball-end for treble alternative
- Workholding: Cradle or flip fixture supporting top face without denting
- Datum: Top face A re-referenced after flip; left end B retained
- Inputs: `family-spec.csv`, `drawings/arch-undercut-section.svg`
- Outputs: Underside arch cut on each bar
- Checks:
  - Center thickness never below `0.250 in`.
  - Arch is centered.
  - No chatter or burning.
  - Toolpath simulation or air-cut completed.

### OP-240 - Drill support holes at nodes

- Machine: Drill press or CNC router
- Tool: 1/4 in brad-point bit or boring tool
- Workholding: Backer board, bar support fixture
- Datum: Left end B, centerline C
- Inputs: `family-spec.csv`, generated bar drawings
- Outputs: Clean node/support holes
- Checks:
  - Hole breakout absent.
  - Node positions within `+/- 0.020 in`.
  - Holes deburred.

### OP-310 - Hand tune bars

- Machine: Bench
- Tool: Soft node supports, tuner, sanding block, scraper, scale
- Workholding: Padded bench, supports at `node_1_in` and `node_2_in`
- Datum: Acoustic node support datum
- Inputs: `validation.csv`, `family-spec.csv`
- Outputs: Measured pitch log and tuned bars
- Checks:
  - Measured Hz recorded at flat, post-arch, post-sand, and final frame stages.
  - Cents error computed.
  - Material removal region documented.

### OP-410 - Cut and deburr resonator tubes

- Machine: Chop saw, band saw, or tube cutter
- Tool: Tube cutter, deburring tool, calipers
- Workholding: Tube V-block, stop block
- Datum: Tube open end
- Inputs: `family-spec.csv`, `sourcing.csv`, `drawings/resonator-layout.svg`
- Outputs: Oversize resonator tubes labeled by note
- Checks:
  - Tube ID matches updated bore.
  - Cut length includes trim allowance.
  - Burrs removed.

### OP-420 - Cap and mount resonators

- Machine: Bench and drill press
- Tool: Drill bits, caps/stoppers, seal material
- Workholding: Tube holding jig, frame mockup
- Datum: Tube open end and bar centerline
- Inputs: `assembly-manual.md`, `drawings/frame-overview.svg`
- Outputs: Mounted adjustable resonators
- Checks:
  - Caps seal without buzz.
  - Tubes clear bars and rails.
  - Note labels visible after assembly.

### OP-510 - Build frame and support rails

- Machine: Table saw, CNC router, drill press
- Tool: Saw blade, drill bits, router bits
- Workholding: Rail fixture, cross-member clamps
- Datum: Player-side datum and rail centerlines
- Inputs: `drawings/frame-overview.svg`, `cad/SolidWorks-MasterLayout-Plan.md`
- Outputs: Temporary or final support frame
- Checks:
  - Supports land at nodes.
  - Cross members remain removable.
  - Mallet and resonator clearance checked.

### OP-900 - Final validation and release

- Machine: Bench
- Tool: Chromatic tuner, microphone, calipers, camera
- Workholding: Assembled frame on stable stand
- Datum: Same support and strike datum used for every note
- Inputs: `validation.csv`, `photo-shotlist.md`
- Outputs: Updated validation.csv and process photos
- Checks:
  - All notes measured.
  - Outliers flagged.
  - Resonator response notes captured.

## Release Checks

- [ ] Every operation has a datum and workholding method.
- [ ] Every tool has a real machine available or an escalation note.
- [ ] All tuning-critical features include trim allowance.
- [ ] C3/A4/C6 pilot data is reviewed before cutting all 37 bars.
- [ ] Actual resonator bore is selected before final tube lengths are frozen.
- [ ] `validation.csv` receives measured data after the first prototype.

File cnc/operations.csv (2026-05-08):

op_id | name | machine | tool | workholding | datum | inputs | outputs | checks | notes
OP-010 | Review design package and pilot gate | Bench | README.md, design.md, calipers, tuner | Flat bench, drawing packet | Top face A, left end B, bar centerline C | design.md; family-spec.csv; drawings/arch-undercut-section.svg; validation.csv | pilot-build checklist | C3/A4/C6 pilot bars identified; actual wood species and tube bore confirmed | Do not cut full set until pilot bars validate K constant and arch schedule.
OP-205 | Build pilot jig set | Bench/CNC router | MDF fixture stock, clamps, tape, centerline pins, backer board, V-block stock | Planer carrier, two-sided spoilboard, soft arch cradle, node-drilling backer, tube V-block | Top face A, left end B, bar centerline C | jig-decision.md; family-spec.csv; drawings/arch-undercut-section.svg | Pilot jig set for C3/A4/C6 | A/B/C datums survive profile/flip/arch/drill/tube-cut; air cuts clear hold-downs | Full 37-bar nest remains blocked until pilot validation rows are measured.
OP-110 | Surface and thickness bar blanks | Jointer/planer/drum sander | Jointer knives, planer, drum sander, calipers | Flat carrier board, push blocks | Top face A and grain arrow | cut-list.csv; family-spec.csv | 37 surfaced oversize blanks | Thickness 0.875 in +/- 0.005; grain direction logged; defects outside finished area | Leave length and width allowance for tabs and final tuning cleanup.
OP-120 | Label blanks and mark nodes | Bench | Marking knife, square, center punch, calipers | Flat bench with stop block | Left end B and centerline C | family-spec.csv; drawings/*-body.svg | Labeled blanks with note, target Hz, nodes | node_1 and node_2 match family-spec.csv; top face remains marked | Cord/support holes belong at free-free nodes.
OP-210 | Prepare CNC fixture and datum verification | CNC router | Spoilboard surfacing bit, edge finder/probe, clamps/tape | Replaceable spoilboard, datum fence, optional vacuum plus clamps | Machine X0 at left end B, Y0 at centerline C, Z0 top face A | cnc/setup-sheet.md; drawings/arch-undercut-section.svg | Verified fixture and air-cut report | Spoilboard surfaced; clamps clear toolpath; sample air-cut passes | This operation creates confidence before Padauk is loaded.
OP-220 | Rough profile bars with tabs | CNC router | 1/4 in downcut spiral; optional 1/8 in upcut for small reliefs | Spoilboard tape/clamps, tabs at non-vibrating ends | Top face A, left end B, centerline C | family-spec.csv; cad/design-table-inputs.csv | Profiled bar blanks with tabs | Tabs do not overlap node holes or arch region; final length retains tuning allowance | Use conservative depth per pass and preserve labeled orientation.
OP-230 | 3D arch underside relief | CNC router | 3/4 in ball-end mill; 1/2 in ball-end for treble alternative | Cradle or flip fixture supporting top face without denting | Top face A re-referenced after flip; left end B retained | family-spec.csv; drawings/arch-undercut-section.svg | Underside arch cut on each bar | Center thickness never below 0.250 in; arch centered; no chatter/burn | Use parabolic toolpath over about 60 percent of bar length. This is the pitch-lowering operation.
OP-240 | Drill support holes at nodes | Drill press or CNC router | 1/4 in brad-point bit or boring tool | Backer board, V/support fixture | Left end B, centerline C | family-spec.csv; generated bar drawings | Clean node/support holes | Hole breakout absent; node positions within +/- 0.020 in; holes deburred | Pilot on scrap before drilling tuned bars.
OP-310 | Hand tune bars | Bench | Soft node supports, tuner, sanding block, scraper, scale | Padded bench, supports at node_1 and node_2 | Acoustic node support datum | validation.csv; family-spec.csv | Measured pitch log and tuned bars | Measured Hz recorded at flat/post-arch/post-sand/final; cents error computed | Remove underside center material to lower pitch. Sneak up slowly.
OP-410 | Cut and deburr resonator tubes | Chop saw/band saw/tube cutter | Tube cutter, deburring tool, calipers | Tube V-block, stop block | Tube open end datum | family-spec.csv; sourcing.csv; drawings/resonator-layout.svg | Oversize resonator tubes labeled by note | Tube ID matches updated bore; cut length includes trim allowance; burrs removed | Recalculate lengths if selected bore differs from current proxy.
OP-420 | Cap and mount resonators | Bench/drill press | Drill bits, caps/stoppers, seal material | Tube holding jig, frame mockup | Tube open end and bar centerline | assembly-manual.md; drawings/frame-overview.svg | Mounted adjustable resonators | Caps seal without buzz; tubes clear bars/rails; note labels visible | Use removable caps for first validation build.
OP-510 | Build frame and support rails | Table saw/CNC/drill press | Saw blade, drill bits, router bits | Rail fixture, cross-member clamps | Player-side datum, rail centerlines | drawings/frame-overview.svg; cad/SolidWorks-MasterLayout-Plan.md | Temporary or final support frame | Supports land at nodes; cross members removable; mallet and resonator clearance checked | Temporary validation frame is acceptable before final furniture-grade frame.
OP-900 | Final validation and release | Bench | Chromatic tuner, microphone, calipers, camera | Assembled frame on stable stand | Same support and strike datum used for every note | validation.csv; photo-shotlist.md | Updated validation.csv and process photos | All notes measured; outliers flagged; resonator response notes captured | Do not treat dimensions as final until measured data closes the loop.

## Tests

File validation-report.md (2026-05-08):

# Marimba Validation Report

Generated: 2026-05-08

## Clean Checks

- `validate_packet.py . --fix --json` returned `ok: true` with no pass-1 or pass-2 findings.
- Required Tier 1 files exist for the current Mode A packet.
- `capstone-deck.md` has enough slides and no placeholder intent fallback.
- README length and referenced files pass the v4 verifier heuristics.
- `print-packet.pdf` exists and passes the verifier's light PDF sanity check.
- Referenced deck drawings exist on disk.
- CSV row-shape check passes for `validation.csv`, `cnc/operations.csv`, `bom.csv`, `cut-list.csv`, and `sourcing.csv`.

## Fixed In V4 Verifier Loop

- None. The scripted verifier had no fixable findings.

## Manual Fixes During This Pass

- Added `jig-decision.md` as the fixture decision and pilot-release layer.
- Added C3/A4/C6 pilot validation rows for `flat_blank`, `post_arch`, `post_sand`, `resonator_coupled`, and `final_frame`.
- Cross-linked the jig layer from `README.md`, `design.md`, `assembly-manual.md`, `cnc/setup-sheet.md`, `cnc/operations.csv`, `drawing-brief.md`, `visual-bom-brief.md`, `capstone-deck.md`, `print-packet.md`, and `site/index.html`.
- Quoted comma-containing CSV cells in `bom.csv`, `sourcing.csv`, and `cut-list.csv` so downstream CSV readers keep a stable column count.

## Escalated

- None for packet completeness.
- Shop decisions still open by design: actual resonator tube ID/material, support method, final frame geometry, and CAM feeds/speeds must be selected after pilot data.

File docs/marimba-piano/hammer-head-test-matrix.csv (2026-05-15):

face_id | material_candidate | hardness_guess | expected_attack | best_first_pairing | risk | test_status
H1 | yarn-wrapped rubber core | soft | warm rounded attack with reduced high partials | wood or synthetic bars | May be too soft for small bars; wrapping can wear. | planned
H2 | solid bouncy-ball rubber | soft_medium | clear rebound with fundamental-heavy tone | aluminum or synthetic bars | Too much bounce may double-strike; needs rebound test. | planned
H3 | silicone or urethane pad | soft_medium | controlled mellow strike | wood or aluminum bars | Durometer must be selected; adhesive bond may fail. | planned
H4 | hard felt over wood core | medium | piano-like softened attack | wood bars | May compact over time and change tone. | planned
H5 | soft maple or basswood face | medium_hard | woody xylophone-like bite | wood or synthetic bars | Can dent softer bars; may be noisy mechanically. | planned
H6 | Delrin or phenolic face | hard | bright sharp attack | aluminum bars | Can sound harsh; may damage finished wood bars. | planned
H7 | thin brass or aluminum cap over compliant backing | hard_experimental | tack-piano metallic transient | aluminum bars only | High damage and glare risk; use only after sacrificial tests. | defer

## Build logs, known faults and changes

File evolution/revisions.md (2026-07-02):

# Revision Register — marimba

| Rev | Date | Parent | Delta | Downstream artifacts invalidated |
| --- | --- | --- | --- | --- |
| A | 2026-07-01 | — | Stage 0 intake of existing master (cad/marimba-master.scad + marimba-design-table.xlsx). Master kept as-is, not rewritten. | none (no alpha/beta/production artifacts exist yet) |

Stage 0 only. Gate A has not been run; no Alpha compiles, vendor quotes, or production lock exist for this product. Remains L1 concept/scaffold.

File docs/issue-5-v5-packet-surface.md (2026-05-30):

# Issue #5 V5 Packet Surface

Status: reviewed scaffold, with CAD/DXF authority pending measurement.

This note records the Round 2 recovery surface for issue #5. It does not
invent CAD geometry, DXF coordinates, tuning frequencies, resonator lengths,
MCP provenance, or measured validation results. It organizes the existing V5
assets so the next reviewer can see which files are traceable and which gates
remain open.

## Authority Chain

1. Workbook-derived packet inputs live in `marimba-design-table.xlsx`,
   `cad/design-table-inputs.csv`, and `family-spec.csv`.
2. `cad/marimba-master.scad` is the current CAD surface. Its authority state is
   `pending_measurement`, not build-ready CAD.
3. `drawings/marimba-pilot-plate.dxf` is the current DXF surface. It covers the
   existing pilot subset only and remains `pending_measurement`.
4. `scripts/validate_marimba_pilot_dxf.py` is a traceability check from the
   pilot DXF back to the design-table rows. It is not CAM review.
5. `validation.csv` is the measurement ledger. The measured fields are empty,
   so no tuning or cents-error authority is claimed.
6. `docs/v5-authority-register.csv` is the issue #5 register for the current
   authority state of each asset.

## Current Permission Boundary

Allowed:

- Use the design tables and pilot DXF for traceability review.
- Use the OpenSCAD file as a concept/prototype CAD surface.
- Run the repo-local DXF traceability script.
- Plan pilot measurements and record them in `validation.csv`.

Not allowed yet:

- Treat the CAD file as native CAD authority.
- Treat the pilot DXF as a full 37-bar export.
- Treat any DXF as CAM-ready toolpath input.
- Claim measured tuning, measured frequencies, cents error, sustain, or
  resonator coupling.
- Generate or backfill dimensions from memory, AI reasoning, screenshots, or
  non-measurement tools.

## Promotion Gates

The packet can move beyond `pending_measurement` only after a future lane
provides real evidence:

- C3/A4/C6 pilot bars measured through the stages already listed in
  `validation.csv`.
- Pilot DXF verified physically by air-cut, print-check, or shop setup review.
- Native CAD or reviewed export produced from the same table source.
- Full-family DXF generated from the reviewed source and registered separately.
- CAM feeds, speeds, tabs, cutter compensation, and workholding reviewed by a
  human or shop-qualified process.

Until then, V5 assets are organized and reviewable, but not fabrication
authority.

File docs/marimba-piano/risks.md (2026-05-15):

# Risks

## Acoustic Risks

- The bar estimates may miss real pitch because stock density, grain, thickness, support holes, and undercut geometry dominate the final result.
  Mitigation: build one sacrificial coupon first and record correction factors before cutting a full octave.

- A shared resonator bank may not suit wood, synthetic, and aluminum cassettes equally.
  Mitigation: test aperture inserts first, then build a second pipe bank only if measurements show the first cannot be corrected.

- Bent resonators may lose energy or shift effective tuning.
  Mitigation: compare straight, bent, and downward-facing tubes with the same effective length before committing to packaging.

- Aluminum bars may sustain too long and blur fast playing.
  Mitigation: test smaller apertures, damping screens, and softer hammer faces before redesigning the chassis.

## Mechanical Risks

- A ganged hammer selector may add friction, noise, or unreliable half-index states.
  Mitigation: prove one hammer manually, then prove a small 3-note selector before building 13 notes.

- The platen lever may apply uneven pressure across the cassette.
  Mitigation: use adjustable stops, spring float in the resonator bed, and pressure/witness tests.

- Gaskets may take a compression set and lose the seal.
  Mitigation: use replaceable gasket strips and adjustable resonator standoffs.

- Cassette swaps may change strike alignment.
  Mitigation: use tapered pins, V-block rails, and visible strike targets during P1 setup.

## Fabrication Risks

- Batch-cutting bars from estimates could waste good stock.
  Mitigation: cut oversize, tune by measurement, and do not trust the table as final cut geometry.

- Full-keyboard scale may make selector torque and resonator packaging difficult.
  Mitigation: keep P1 to 13 notes and promote to 25+ notes only after mechanism data exists.

## Safety Risks

- Platen and selector mechanisms create pinch points.
  Mitigation: add hard stops, guards, and an interlock preventing cassette removal while clamped.

- Hard hammer faces can damage soft wood bars or launch fragments from brittle test pieces.
  Mitigation: use eye protection, sacrificial bars, and low-force tests before performance strikes.

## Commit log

2026-05-02 Initial scaffold: Marimba
    [marimba-design-table.xlsx]
2026-05-06 update v4
    [bom.csv, cut-list.csv, design-input-row.csv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]
2026-05-15 Add marimba piano concept packet
    [aperture-test-matrix.csv, bom.csv, cut-list.csv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]
2026-05-18 Add honest V5 explorer scaffold for marimba (#4)
    [marimba-pilot-plate.dxf, validation-loop.csv, visual-output-register.csv]
2026-05-20 Add marimba pilot DXF authority check (#6)
    [visual-output-register.csv]
2026-05-30 [marimba] V5 honest packet surface — Photoshop-MCP register (#1) + CAD/DXF authority chain (#5) (#7)
    * v5(marimba): honest packet surface (Refs #5)
    * v5(marimba): honest packet surface (Refs #1)
    ---------
    [v5-authority-register.csv, visual-output-register.csv]
2026-05-31 Add image-gen concept prompt; wire explorer images
2026-06-21 Wire 5 rendered concept image(s) into explorer gallery
2026-07-02 V5 packet refresh: status line, provenance note, evolution intake
    - README had no validator-parseable Status line (only a "**Readiness: L1**"
    heading). Added "Status: L1 concept packet" near the top, keeping all
    existing L1/"not a V5 build-packet candidate" language as-is — no
    promotion of readiness level.
    - Kept cad/marimba-master.scad as the existing master (not rewritten, per
    the percussion addendum's EXISTING MASTERS rule). Verified it still
    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
